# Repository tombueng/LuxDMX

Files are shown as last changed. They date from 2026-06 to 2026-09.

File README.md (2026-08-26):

<p align="center">
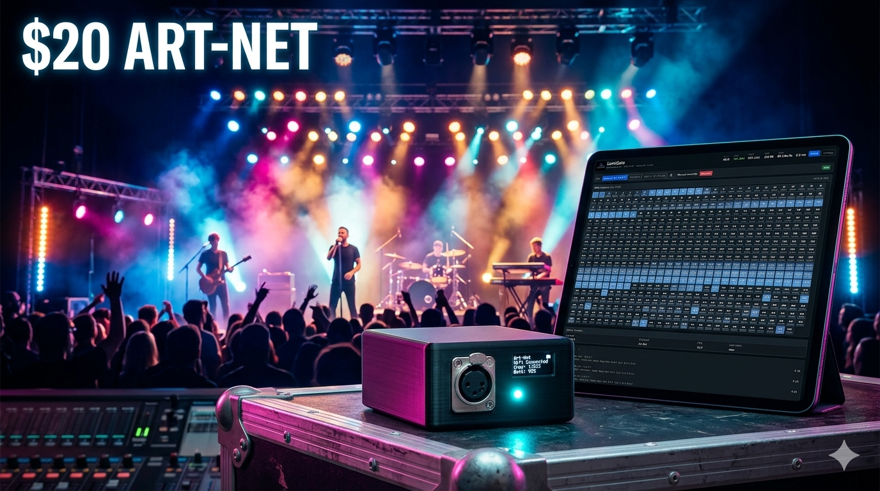
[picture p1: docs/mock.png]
LuxDMX — open-source Art-Net / sACN to DMX512 gateway with a live diagnostic web UI
  
</p>

<p align="center">
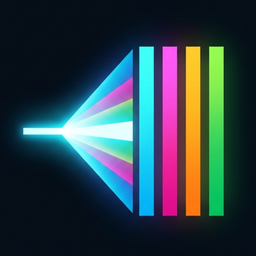
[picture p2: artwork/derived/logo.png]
LuxDMX logo
  
</p>

<h1 align="center">LuxDMX</h1>

<p align="center">
  <b>Open-source Art-Net / sACN (E1.31) &rarr; DMX512 gateway for ESP32 / ESP32-S3 / Ethernet.</b>
</p>

<p align="center">
  Not just another Art-Net node &mdash; a network DMX node <i>and</i> a live diagnostic tool.<br>
  Watch all 512 channels update in real time in your browser, get warned the instant
  <b>two consoles fight over a universe</b>, see per-sender FPS and frame jitter, and drive
  <b>galvanically-isolated</b> DMX out. Builds for a few dollars.
</p>

<p align="center">
  
  
  
  
</p>

<p align="center">
  <a href="https://tombueng.github.io/LuxDMX/"><b>⚡ Flash from your browser</b></a> &nbsp;·&nbsp;
  <a href="https://luxdmx.org/video"><b>▶ Watch the demo</b></a> &nbsp;·&nbsp;
  <a href="hardware/README.md"><b>🛠 Custom PCB</b></a> &nbsp;·&nbsp;
  <a href="#flashing-pre-built-firmware"><b>Install</b></a>
</p>

| Status page | Settings page |
|---|---|
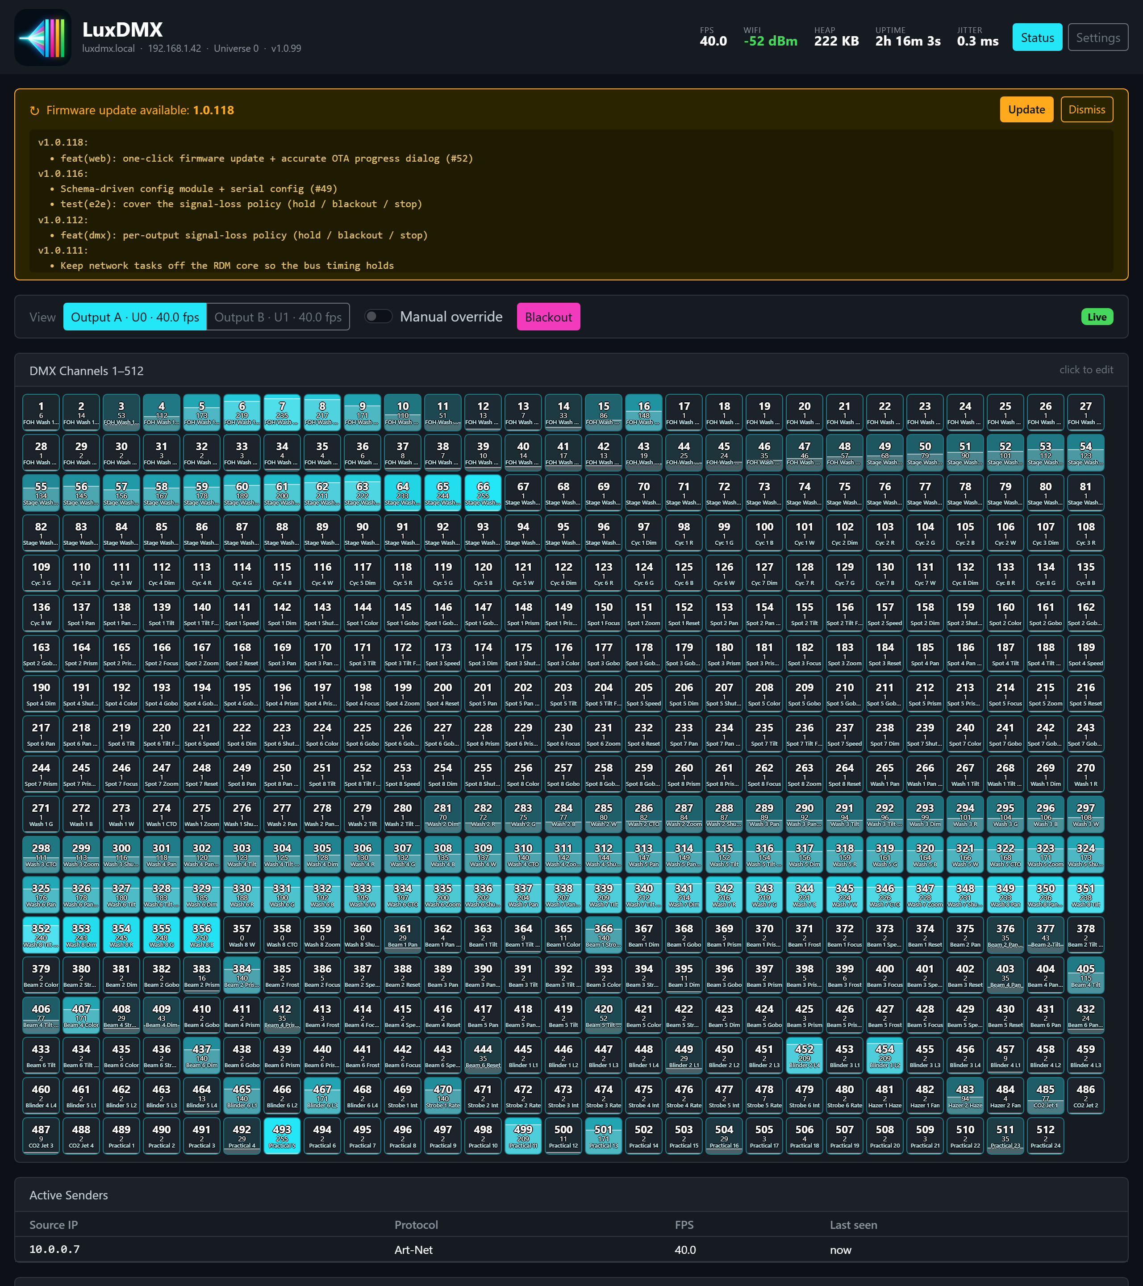
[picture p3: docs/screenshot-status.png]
Status page
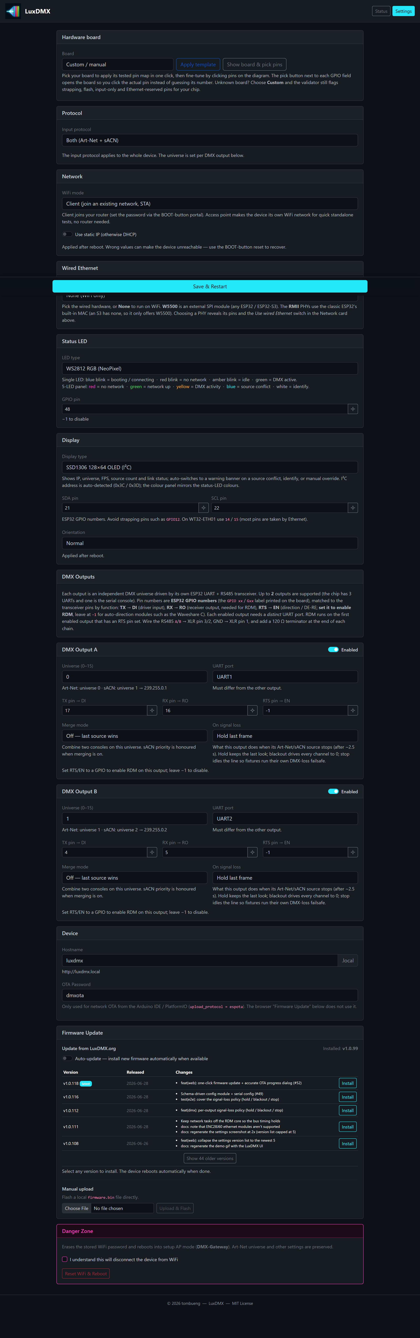
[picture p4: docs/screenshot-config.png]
Settings page
|  |  |

### Web UI walkthrough

A guided tour of every control — manual channel control, labels, sparkline history, identify, blackout, and all settings:

LuxDMX web UI walkthrough (https://luxdmx.org/video)

▶ **[Watch the full walkthrough on YouTube](https://luxdmx.org/video)** &nbsp;·&nbsp; regenerate with [`docs/screenshot.mjs`](docs/screenshot.mjs)

---

## Features

| Feature | Details |
|---|---|
| **Art-Net → DMX512** | Full 512-channel, unicast or broadcast, universe configurable (0–15) |
| **sACN / E1.31 → DMX512** | Multicast receive, universe configurable, runs alongside Art-Net |
| **Protocol selection** | Art-Net only / sACN only / Both — configurable in web UI |
| **Live Web UI** | Bootstrap 5 dark theme, WebSocket push (~10/s), all 512 channels visible |
| **Sender list** | Shows all active Art-Net / sACN senders with per-sender FPS |
| **Conflict detection** | Warning banner when multiple senders are active simultaneously |
| **Source merging** | Per-output HTP (highest takes precedence) / LTP (latest wins) / off, honouring the sACN priority field |
| **Jitter stat** | Real-time inter-frame timing deviation (EMA) |
| **Change log** | Live log of DMX value changes with top-N changed channels per frame |
| **Sparkline** | Per-channel history sparkline in the channel detail modal |
| **Channel labels** | Name any channel (e.g. "Front Wash L") — shown in grid, modal, and change log |
| **Identify** | Flash a channel to full for ~1.5 s to physically locate the fixture |
| **Manual DMX control** | Click any channel in browser, set value via slider |
| **Blackout button** | Zero all channels instantly from browser |
| **Art-Net / Manual toggle** | Switch between protocol passthrough and manual override |
| **Signal-loss policy** | Per-output choice when the source stops: hold last frame (default), blackout, or stop sending. Continuous 40 Hz refresh bridges brief input gaps either way |
| **Static IP or DHCP** | Configurable static IP/gateway/subnet/DNS, or automatic DHCP |
| **Mesh-aware WiFi** | Scans all channels and joins the **strongest** AP (multi-AP/mesh friendly) |
| **First-run setup portal** | On first boot (or BOOT-button held) LuxDMX opens its own `LuxDMX-setup` access point with a captive portal. The on-brand page (served from the same web UI) lets you either join your WiFi or run the device as its own access point, no router needed |
| **Selectable network mode** | Pick the interface (WiFi or wired Ethernet) and WiFi mode (client/STA or standalone AP) in the web UI, on boards that have both |
| **Standalone AP mode** | LuxDMX hosts its own WiFi network so a phone/tablet/console connects directly and sends Art-Net with no router (reachable at `192.168.4.1`) |
| **Wired link-loss policy** | Pick what happens if wired Ethernet is selected but the link is down: keep retrying (default, never opens a hotspot), a standalone WPA2 AP, reboot, or fall back to your saved WiFi network. A runtime watchdog applies it even if the cable is pulled mid-run, and the fallback AP never opens *unsecured*. The WiFi setup portal is BOOT-button-only (physical access), never an automatic fallback |
| **Versioned OTA** | Pick & install any past release from a table, or auto-update to latest |
| **OTA Updates** | ArduinoOTA (IDE/CLI) + manual `.bin` upload + one-click update from luxdmx.org |
| **mDNS + DHCP hostname** | Reachable as `dmx-gateway.local` via mDNS, *and* the device sends its hostname over DHCP (option 12) so your router registers it by plain name. Clients without mDNS (e.g. Windows) can then reach it as `dmx-gateway` / `dmx-gateway.fritz.box`. Hostname configurable |
| **REST API** | `GET /dmx.json`, `/senders.json`, `/log.json`, `/version.json`, `/labels.json` |
| **Status LED** | Plain GPIO, WS2812 RGB NeoPixel, or 5-LED panel (v6 board) — one status language: green = up (stays on; slow blink = DMX coming in), blue = RDM/identify **added on top of green** (both LEDs on the panel, cyan on a single RGB LED), orange = Ethernet-on-WiFi-fallback, red = no network, Knight-Rider boot |
| **Up to 2 DMX outputs** | Two independent universes, each its own UART + RS485 transceiver (same universe on both = splitter) |
| **RDM (E1.20)** | Discover and configure fixtures on the wire: DISC_UNIQUE_BRANCH discovery, GET/SET DEVICE_INFO / DMX start address / identify / sensors, on an RDM-capable output (one with a DE/RE pin). esp_dmx-free RMT-TX + UART-RX engine |
| **RDM over Art-Net** | Full Art-Net 4 RDM output gateway (ArtPoll / ArtTodRequest / ArtTodControl / ArtRdm) so a console (DMX-Workshop, MagicQ, grandMA3, OLA) does RDM to the fixtures over the network. Discovery is scheduled one transaction per DMX frame, so RDM never stalls the DMX output. See [docs/rdm.md](docs/rdm.md) |
| **Remote node config (ArtAddress)** | Configure the node from the console's own network window (MagicQ Network Manager, DMX-Workshop, ...): rename it and move each output to a different universe, saved to NVS so it survives a reboot. On by default and **unauthenticated**, like every other Art-Net command. See [Remote node config over Art-Net](#remote-node-config-over-art-net-artaddress) |
| **Remote IP config (ArtIpProg)** | A controller can read and set the node's IP / mask / gateway (or switch it to DHCP) over the network with Art-Net `ArtIpProg`, so a box that landed on an unreachable address is recoverable without the BOOT button or a serial cable. **Off by default** (Art-Net has no auth, so on = anyone on the wire can renumber it); the new address applies on the next boot. See [Remote IP config over Art-Net](#remote-ip-config-over-art-net-artipprog-off-by-default) |
| **Status display** | Optional I²C OLED (SSD1306 / SH1106) or colour SPI OLED (SSD1351) — IP, universe, FPS, sources + auto-rotating conflict/identify/manual banners |
| **On-unit controls** | Optional rotary encoder and/or up to 4 buttons drive a small on-display menu to set the universe (and protocol) without a phone or PC, and the choice persists. Works with any mix of inputs — encoder-only, one button, or the lot. See [docs/controls.md](docs/controls.md) |
| **Configurable DMX pins** | Per output: universe, UART port, TX / RX / RTS GPIO — set at runtime via web UI, no recompile |
| **NVS persistence** | Universe, protocol, IP config, labels, hostname, OTA password, LED/DMX pin config survive reboots |
| **Config reset** | Hold BOOT button 3 s on startup, or via `/reset` page |
| **Remote restart** | Restart the box from the web UI (**Device → Restart device**) or `POST /reboot`, without changing a setting. Useful when a long-running gateway needs a nudge, or to free up memory before a firmware update |
| **Ethernet support** | WT32-ETH01 (LAN8720) and the v6 board (W5500) run wired LAN *or* WiFi, switchable at runtime; any ESP32 / ESP32-S3 + an external SPI module (W5500 or DM9051) works too, and a **classic ESP32 can pick a SPI chip (W5500 / DM9051) or the built-in MAC + an RMII PHY** (LAN8720, IP101, RTL8201, DP83848, KSZ8081, JL1101) in `/config`; DHCP or static |
| **Dual/triple target** | Builds for ESP32 (WROOM-32), ESP32-S3 (DevKitC-1), WT32-ETH01 |

---

## Hardware

> ### 🛠 Custom PCB — LuxDMX v6
>
> Want the real thing instead of breadboard + modules? There's a complete **open-source 4-layer PCB**:
> ESP32-S3 with **both WiFi and wired Ethernet** (W5500), **two galvanically-isolated DMX universes**
> (two XLR-5 outputs), **802.3af PoE** or USB-C power + flashing, a 5-LED status panel, BOOT/RST buttons,
> and an optional OLED/TFT display header. All palm-sized and fabricable at JLCPCB for a few dollars.
>
> **v6 is DMX512-A Protected** (ANSI E1.11 Annex C): each DMX output survives a sustained fault on the data
> pins — someone plugging mains (30 VAC) or up to ±42 VDC into the XLR — without damage. A series Bourns TBU
> high-speed protector blocks the fault in <1 µs and the board self-recovers when it's removed. Full
> [E1.11 / DMX512-A compliance breakdown →](hardware/E1.11_COMPLIANCE.md)
>
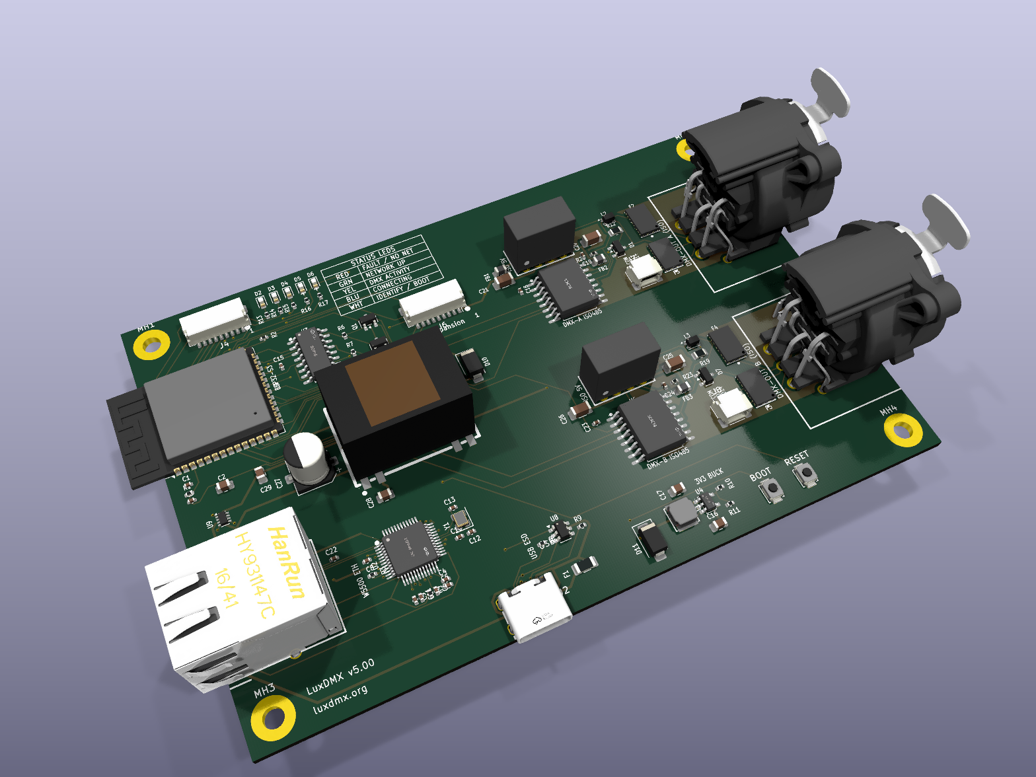
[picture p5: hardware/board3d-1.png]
LuxDMX v6 custom PCB — DMX512-A Protected
> [](hardware/README.md)
>
> **→ Full design, component rationale, BOM, gerbers & JLCPCB fab guide: [`hardware/`](hardware/README.md)**

The rest of this section covers the simpler **breadboard / module** build (an off-the-shelf ESP32 DevKit
+ an isolated RS485 module) — perfect for getting started without fabricating a board.

### Bill of Materials — WiFi build (ESP32 / ESP32-S3)

| # | Component | Description | Link |
|---|---|---|---|
| 1 | **ESP32 DevKit v1** | ESP32-WROOM-32, 30-pin, any CH340/CP2102 variant | [Amazon.de search](https://www.amazon.de/s?k=ESP32+DevKit+WROOM-32) |
| 2 | **Waveshare TTL to RS485 (C)** | Galvanically isolated RS485 transceiver, auto-direction | [Amazon.de – B0D4TZQYVG](https://www.amazon.de/dp/B0D4TZQYVG) |
| 3 | **XLR-5 female panel socket** | Standard DMX output connector (XLR-3 also works) | [Amazon.de search](https://www.amazon.de/s?k=XLR+5+Pin+Buchse+Panel) |
| 4 | **Jumper wires / dupont cables** | Male–male for breadboard, or direct solder | any |
| 5 | **USB-A to Micro-USB cable** | Power + serial flash | any |

### Bill of Materials — Ethernet build (WT32-ETH01)

| # | Component | Description | Link |
|---|---|---|---|
| 1 | **WT32-ETH01** | ESP32 + LAN8720 Ethernet PHY, built-in RJ45 | [Amazon.de search](https://www.amazon.de/s?k=WT32-ETH01) |
| 2 | **Waveshare TTL to RS485 (C)** | Same as WiFi build | [Amazon.de – B0D4TZQYVG](https://www.amazon.de/dp/B0D4TZQYVG) |
| 3 | **XLR-5 female panel socket** | Same as WiFi build | any |
| 4 | **Ethernet cable** | Cat5e or better | any |
| 5 | **5V power supply** (500 mA+) | WT32-ETH01 has no USB port — use a 5V supply on the VIN pin | any |

> The WT32-ETH01 has a built-in RJ45 jack and LAN8720 PHY soldered on-board. No additional Ethernet module needed.

**Optional for enclosure:**
- Project box / DIN-rail enclosure
- 120 Ω termination resistor across DMX A/B at the cable end (required for long runs)

---

### The RS485 Module: Waveshare TTL to RS485 (C)

This module is the key interface between the ESP32's UART and the DMX RS485 bus.

| Property | Value |
|---|---|
| Product name | Waveshare TTL to RS485 (C) |
| Isolation | Galvanic, 2500 V RMS (SP3485 + isolation transformer) |
| Direction control | Automatic — no DE/RE pin needed |
| TTL voltage | 3.3 V or 5 V (VCC selects level) |
| Max baudrate | ≥ 250 kbps (verified working at DMX rate) |
| Connector (TTL side) | 6-pin 2.54 mm header: VCC / GND / RXD / TXD / (unused) / (unused) |
| Connector (RS485 side) | Screw terminal: A / B / GND |
| Dimensions | ~38 × 14 mm |

> **Why galvanic isolation?**  
> DMX fixtures are often powered from separate circuits or have ground loops. The isolated module prevents ground noise from corrupting the signal and protects the ESP32 from voltage spikes.

> **Why auto-direction?**  
> Standard RS485 requires toggling a DE/RE pin to switch between transmit and receive. The Waveshare (C) variant handles this internally based on line activity — no GPIO needed, firmware is simpler. Trade-off: RDM (which requires half-duplex arbitration) is not supported by this module.

---

### Pinout Reference

**Waveshare TTL to RS485 (C) — TTL header (left side):**

```
Pin 1  VCC   → ESP32 3.3V
Pin 2  GND   → ESP32 GND
Pin 3  RXD   → ESP32 GPIO17  (default TX pin — configurable in web /config)
Pin 4  TXD   → ESP32 GPIO16  (default RX pin — configurable in web /config)
Pin 5  —     (not connected)
Pin 6  —     (not connected)
```

> **Different hardware?** If your RS485 module or ESP32 board uses different GPIO pins, change TX/RX under **Settings → DMX Output Pins** in the web UI. No recompile needed.

**Waveshare TTL to RS485 (C) — RS485 screw terminal (right side):**

```
A  →  DMX XLR pin 3  (Data+)
B  →  DMX XLR pin 2  (Data–)
GND→  DMX XLR pin 1  (Shield/Ground)  [optional but recommended]
```

---

### Wiring Diagram

LuxDMX Wiring Diagram

**Connection table:**

| ESP32 pin | → | Module pin | → | XLR pin |
|---|---|---|---|---|
| GPIO17 (TX) | → | RXD | — | — |
| GPIO16 (RX) | ← | TXD | — | — |
| 3.3V | → | VCC | — | — |
| GND | → | GND | — | — |
| — | — | A (RS485+) | → | Pin 3 |
| — | — | B (RS485–) | → | Pin 2 |
| GND | — | GND | → | Pin 1 (optional) |

#### WT32-ETH01 wiring (different pins — GPIO16 used by LAN8720)

| WT32-ETH01 pin | → | Module pin | → | XLR pin |
|---|---|---|---|---|
| GPIO4 (TX) | → | RXD | — | — |
| GPIO5 (RX) | ← | TXD | — | — |
| 3.3V | → | VCC | — | — |
| GND | → | GND | — | — |
| — | — | A (RS485+) | → | Pin 3 |
| — | — | B (RS485–) | → | Pin 2 |

> **Do not use GPIO16 on the WT32-ETH01** — it gates the LAN8720's 50 MHz oscillator (the Arduino core declares it as `ETH_PHY_POWER`), so driving it kills the Ethernet link. GPIO0 is the RMII reference clock and is equally off-limits.
>
> GPIO17 **is** free to use — it's plain `TXD2` on this board and has no Ethernet role. (An earlier version of this page said otherwise; that was wrong.) Note it also drives the on-board TX activity LED, so expect a few mA of extra load and a flickering LED while DMX is clocking.

---

### Assembly Guide

#### Step 1 — Prepare the ESP32

No soldering required if using a DevKit with pre-soldered headers. Place it on a breadboard or in your enclosure.

#### Step 2 — Connect ESP32 ↔ RS485 module

Using dupont jumper wires:

| Color convention | From | To |
|---|---|---|
| Red | ESP32 **3.3V** | Module **VCC** |
| Black | ESP32 **GND** | Module **GND** |
| Yellow | ESP32 **GPIO17** (TX) | Module **RXD** |
| Green | ESP32 **GPIO16** (RX) | Module **TXD** |

> Use **3.3V**, not 5V — the ESP32's GPIOs are not 5V tolerant.

#### Step 3 — Wire the XLR connector

The DMX standard uses XLR-5 (5-pin), but most DMX fixtures also accept XLR-3. Pin numbering is the same:

| XLR Pin | Signal | RS485 module |
|---|---|---|
| 1 | Shield / GND | Module GND (optional) |
| 2 | DMX Data– | Module **B** |
| 3 | DMX Data+ | Module **A** |
| 4 | (unused in DMX) | — |
| 5 | (unused in DMX) | — |

Screw the wires into the RS485 module's terminal block firmly.

#### Step 4 — Termination resistor (for longer cable runs)

For DMX cable runs over ~10 m, solder a **120 Ω resistor** between pins 2 and 3 (A and B) at the **far end** of the DMX chain (i.e., inside the last fixture's XLR input). Most professional fixtures include this internally.

#### Step 5 — Power

The ESP32 DevKit is powered via its **Micro-USB port**. Any 5V USB power supply works (500 mA is sufficient). The RS485 module draws its power from the ESP32's 3.3V rail.

---

### Notes

- **Do not connect DE/RE** — the Waveshare (C) handles direction automatically. Connecting them will break transmission.
- **Keep TTL wires short** (< 20 cm). Long unshielded wires on the TTL side pick up noise; the RS485 side handles long distances natively.
- **XLR gender:** Use a **female** XLR panel socket for the DMX output. DMX sources (transmitters) use female XLR; receivers use male XLR. LuxDMX is a source.

---

## Software Stack

LuxDMX is built entirely on free and open-source software: firmware, web UI, tests, and
the hardware design tooling. Firmware versions are pinned in `platformio.ini`; everything
below is what we actually pull in and what each piece does for us.

### Firmware, third-party libraries

| Library | Version | License | What we use it for |
|---|---|---|---|
| [rstephan/ArtnetWifi](https://github.com/rstephan/ArtnetWifi) | `^1.5.0` | MIT | Art-Net receiver: parses ArtDMX/ArtPoll on UDP 6454. |
| [ESP32Async/ESPAsyncWebServer](https://github.com/ESP32Async/ESPAsyncWebServer) | git | LGPL-3.0 | The whole HTTP side: web UI, REST API, WebSocket live channels, OTA upload, and the first-run setup portal. All non-blocking, so DMX keeps clocking while someone browses the config page. |
| [ESP32Async/AsyncTCP](https://github.com/ESP32Async/AsyncTCP) | git | LGPL-3.0 | TCP backend for the above. We give it a bigger stack/queue and pin it to core 0 (see the build flags in `platformio.ini`) so it can't preempt the RDM bus timing on core 1. |
| [Adafruit NeoPixel](https://github.com/adafruit/Adafruit_NeoPixel) | `^1.12.3` | LGPL-3.0 | Drives the WS2812 RGB status LED (DevKit boards, and any DIY build with an addressable LED). |
| [Adafruit GFX Library](https://github.com/adafruit/Adafruit-GFX-Library) | `^1.11.11` | BSD | Shared drawing primitives and fonts behind every supported display panel. |
| [Adafruit SSD1306](https://github.com/adafruit/Adafruit_SSD1306) | `^2.5.13` | BSD | 128×64 / 128×32 mono I²C OLEDs. |
| [Adafruit SH110X](https://github.com/adafruit/Adafruit_SH110X) | `^2.1.12` | BSD | SH1106 / SH1107 mono OLEDs (the 1.3" panels). |
| [Adafruit SSD1351](https://github.com/adafruit/Adafruit-SSD1351-library) | `^1.3.2` | BSD | 128×128 colour SPI OLED. |
| [Adafruit BusIO](https://github.com/adafruit/Adafruit_BusIO) | transitive | MIT | I²C/SPI abstraction the Adafruit display drivers sit on. |

> The two `ESP32Async` libraries and Adafruit NeoPixel are **LGPL-3.0**. We link them
> unmodified, which is what the LGPL asks for; the LuxDMX source itself stays MIT.

There is no DMX or RDM library. Both protocols are ours: `dmx_rmt.h` clocks DMX512 out of
the RMT peripheral, and `rdm_rmt.h` is an RDM E1.20 controller on RMT-TX plus a RX-only
UART, with the E1.20 types declared in `rdm_types.h`. This used to be
[someweisguy/esp_dmx](https://github.com/someweisguy/esp_dmx); we moved off its UART driver
when Ethernet DMA contention started tearing frames (issue #64) and dropped the dependency
entirely once nothing but its type declarations was left.

### Firmware, platform and built-ins

[arduino-esp32 v3](https://github.com/espressif/arduino-esp32) (LGPL-2.1) on top of
[ESP-IDF 5.x](https://github.com/espressif/esp-idf) (Apache-2.0), delivered by the
[pioarduino](https://github.com/pioarduino/platform-espressif32) platform fork (the
mainline PlatformIO platform is stuck on v2.x, which has no W5500 Ethernet).

| Component | What we use it for |
|---|---|
| RMT peripheral | DMX512 transmit clocked out in hardware, immune to the core-0 network DMA contention behind issue #64, plus the TX half of the RDM controller. |
| `WiFi.h` / `ETH.h` | WiFi STA/AP, and wired Ethernet on both paths: W5500 over SPI and LAN8720 over RMII. |
| built-in UDP | sACN / E1.31 receive on port 5568. |
| `ArduinoOTA`, `Update`, `HTTPUpdate`, `HTTPClient`, `WiFiClientSecure` | OTA updates: the Arduino OTA path, web upload, and the self-update check against the GitHub release. |
| `ESPmDNS` | `dmx-gateway.local` discovery. |
| `Preferences` | NVS-backed persistent config. |
| `DNSServer` | Captive-portal DNS while the device is in setup-AP mode. |
| `Wire` / `SPI` | I²C and SPI buses for the displays and the W5500. |
| `driver/uart.h` | The RX-only UART that catches RDM responses. |
| FreeRTOS | Tasks, queues, and the core pinning that keeps network work off the DMX/RDM core. |

### Web UI

| Library | Version | License | What we use it for |
|---|---|---|---|
| [Bootstrap](https://getbootstrap.com/) (CSS only) | 5.3.3 | MIT | Layout and styling for every page. Vendored at `src/assets/bootstrap.min.css` and served gzipped from flash, so the UI works on a device with no internet. |
| [esp-web-tools](https://github.com/esphome/esp-web-tools) | 10 | Apache-2.0 | The browser flasher on the project page (`web/index.html`), so nobody needs a toolchain to install firmware. |

No JS framework. The pages are plain ES6, and the board pin-picker and the RDM sensor
charts are hand-rolled SVG. It all has to fit in flash next to the firmware.

### Build, CI, and tests

| Tool | License | What we use it for |
|---|---|---|
| [PlatformIO Core](https://platformio.org/) | Apache-2.0 | Build system, dependency pinning, and flashing. |
| [esptool](https://github.com/espressif/esptool) | GPL-2.0 | Serial flashing and merging the factory image. |
| [Playwright](https://playwright.dev/) (`@playwright/test ^1.60`) | Apache-2.0 | The end-to-end suite in [docs/tests/](docs/tests/): drives a live device with real Art-Net/sACN and asserts the REST API, WebSocket, and web UI. |
| [Pillow](https://python-pillow.org/) | MIT-CMU | Renders the display previews in [docs/](docs/) from the firmware's own layout math. |
| [GitHub Actions](https://github.com/actions) (`checkout`, `cache`, `setup-python`, `upload-artifact`, `*-pages`) | MIT | Builds every push, publishes the OTA release, deploys the Pages site. |

The native config round-trip test (`test/native/`) deliberately uses no framework: it
compiles the config engine on the host against small `Arduino.h` / `Preferences.h` shims.

### Hardware design tooling

| Tool | License | What we use it for |
|---|---|---|
| [KiCad 9](https://www.kicad.org/) + the `pcbnew` Python API | GPL-3.0 | The board itself, and the scripts under [hardware/scripts/](hardware/scripts/) that place parts, fix planes, and gate the design on DRC. |
| `kicad-cli` | GPL-3.0 | Gerber/drill export, DRC runs, schematic PDF, all scripted with no GUI in the loop. |
| [SKiDL](https://github.com/devbisme/skidl) | MIT | Schematic-as-code: `hardware/scripts/luxdmx.py` generates the netlist the schematic and board are built from. |
| [Freerouting 2](https://github.com/freerouting/freerouting) | GPL-3.0 | Autorouting passes (the jar lives in `hardware/tools/`, not in git). |
| [openpyxl](https://openpyxl.readthedocs.io/) | MIT | Real `.xlsx` BOM and CPL files; JLCPCB rejects hand-rolled ones. |

### RDM test fixture (separate sub-project)

[RDM/](RDM/) is a standalone RP2350 (Pico Plus 2 W) DMX/RDM responder used to test this
controller's on-wire timing. It builds on [arduino-pico](https://github.com/earlephilhower/arduino-pico)
(LGPL-2.1) and [Pico-DMX](https://github.com/jostlowe/Pico-DMX) (BSD-3-Clause) for the PIO
DMX engine.

---

## Flashing Pre-built Firmware

> ### ⚡ Flash from your browser — no install, no command line
>
> Open **[the web flasher](https://tombueng.github.io/LuxDMX/)** in desktop **Chrome or Edge**,
> plug in your board over USB, pick your model, and click flash. That's it — no Python, no esptool,
> no toolchain. It always installs the latest release.
>
> The manual / scripted methods below still work if you prefer them, or for the WT32-ETH01 (which has no USB port).

No toolchain needed. GitHub CI builds the firmware on every push to master.

**[Download latest release](https://github.com/tombueng/LuxDMX/releases/tag/latest)** — includes `firmware.bin`, `bootloader.bin`, `partitions.bin`, `boot_app0.bin`.

### Boot mode (required for all methods)

You must manually enter download mode before flashing:

1. Hold **BOOT** button
2. Press and release **EN** (or **RST**) while keeping BOOT held
3. Release BOOT — the chip is now in download mode
4. Run the flash command

> **ESP32-S3 DevKitC-1:** use the **USB-UART** port (labeled on the board), not the native USB port. The native USB port cannot be used with esptool.

### Windows — one-liner (PowerShell)

Downloads and runs [`flash.ps1`](flash.ps1), which installs Python + esptool automatically:

```powershell
Set-ExecutionPolicy -Scope Process Bypass; irm https://raw.githubusercontent.com/tombueng/LuxDMX/master/flash.ps1 | iex
```

Or save and run it manually:

```powershell
# Download
Invoke-WebRequest https://raw.githubusercontent.com/tombueng/LuxDMX/master/flash.ps1 -OutFile flash.ps1
# Run
Set-ExecutionPolicy -Scope Process Bypass
.\flash.ps1
```

The script: installs Python 3 via `winget` if missing → installs `esptool` via pip → downloads the four firmware blobs from the latest GitHub release → lets you pick a COM port → guides you through boot mode → flashes.

### macOS / Linux — ESP32 (WROOM-32)

```bash
pip install esptool

REPO=tombueng/LuxDMX
for f in firmware.bin bootloader.bin partitions.bin boot_app0.bin; do
  curl -sL "$(curl -s https://api.github.com/repos/$REPO/releases/tags/latest \
    | python3 -c "import sys,json; assets=json.load(sys.stdin)['assets']; \
      print(next(a['browser_download_url'] for a in assets if a['name']=='$f'))")" -o $f
done

# Enter boot mode first (see above), then:
esptool.py --chip esp32 --port /dev/ttyUSB0 --baud 460800 \
  --before default_reset --after hard_reset \
  write_flash -z --flash_mode dio --flash_freq 80m \
  0x1000 bootloader.bin 0x8000 partitions.bin \
  0xe000 boot_app0.bin 0x10000 firmware.bin
```

### macOS / Linux — ESP32-S3 (DevKitC-1)

> **Important:** bootloader goes at `0x0000` on S3 (not `0x1000` like the original ESP32).

```bash
pip install esptool

REPO=tombueng/LuxDMX
for f in firmware-esp32s3.bin bootloader-esp32s3.bin partitions-esp32s3.bin boot_app0.bin; do
  curl -sL "$(curl -s https://api.github.com/repos/$REPO/releases/tags/latest \
    | python3 -c "import sys,json; assets=json.load(sys.stdin)['assets']; \
      print(next(a['browser_download_url'] for a in assets if a['name']=='$f'))")" -o $f
done

# Enter boot mode first, use the USB-UART port, then:
esptool.py --chip esp32s3 --port /dev/ttyUSB0 --baud 921600 \
  --before default_reset --after hard_reset \
  write_flash -z --flash_mode dio --flash_freq 80m \
  0x0000 bootloader-esp32s3.bin 0x8000 partitions-esp32s3.bin \
  0xe000 boot_app0.bin 0x10000 firmware-esp32s3.bin
```

> Replace `/dev/ttyUSB0` with your port (`/dev/tty.usbserial-*` on macOS).

### macOS / Linux — WT32-ETH01

```bash
pip install esptool

REPO=tombueng/LuxDMX
for f in firmware-wt32eth01.bin bootloader-wt32eth01.bin partitions-wt32eth01.bin boot_app0.bin; do
  curl -sL "$(curl -s https://api.github.com/repos/$REPO/releases/tags/latest \
    | python3 -c "import sys,json; assets=json.load(sys.stdin)['assets']; \
      print(next(a['browser_download_url'] for a in assets if a['name']=='$f'))")" -o $f
done

# Enter boot mode (hold BOOT + press RST), then:
esptool.py --chip esp32 --port /dev/ttyUSB0 --baud 460800 \
  --before default_reset --after hard_reset \
  write_flash -z --flash_mode dio --flash_freq 80m \
  0x1000 bootloader-wt32eth01.bin 0x8000 partitions-wt32eth01.bin \
  0xe000 boot_app0.bin 0x10000 firmware-wt32eth01.bin
```

---

## Build & Flash

### Requirements

- [PlatformIO](https://platformio.org/) with VS Code extension
- ESP32 connected via USB (CH340 or CP2102)

### Project Structure

```
LuxDMX/
├── src/
│   ├── main.cpp          ← firmware logic
│   ├── config/
│   │   └── config_schema.cpp  ← THE field table: one row per setting
│   ├── pages/            ← edit web UI here (plain HTML)
│   │   ├── index.html
│   │   ├── config.html
│   │   ├── config_saved.html
│   │   ├── reset.html
│   │   └── reset_done.html
│   ├── assets/           ← images served by the ESP32
│   │   └── logo.webp     ← 256×256 WebP (~5 KB), embedded into the firmware on build
│   └── generated/        ← auto-created at build time, gitignored
├── include/              ← config_schema.h (Config struct) + config_enums.h
├── lib/EmbeddedConfig/   ← reusable schema-driven config engine (NVS + serial console)
├── templates/            ← per-board default VALUES (esp32dev.ini, luxdmx_v6.ini, ...)
├── docs/                 ← documentation assets (README images)
├── extra_scripts.py      ← PlatformIO pre-build hook
└── platformio.ini
```

Config is schema-driven: every persisted setting is described once as a row in
`src/config/config_schema.cpp`, and that one table drives NVS load/save, the
`/config` web form, and the serial console. Defaults live in `templates/*.ini`
(picked per build with `-DDEFAULT_TEMPLATE=...`), not as `-D` macros. The engine
itself is a standalone PlatformIO library under `lib/EmbeddedConfig/`.

### How the build pipeline works

Before every `pio run`, PlatformIO executes `extra_scripts.py`, which:

1. Reads every `src/pages/*.html` file
2. Reads every image/CSS in `src/assets/` (`*.png`, `*.webp`, `*.svg`, `*.css`)
3. Converts them to C `PROGMEM` arrays / string literals and writes them to `src/generated/*.h`
4. `main.cpp` `#include`s those headers — the HTML and images become part of the firmware binary
5. Embeds the board default `templates/*.ini` into `src/generated/config_templates.cpp` (via `tools/gen_config_templates.py`), so a build's defaults come from a data file, not hand-edited macros

**To change the web UI**, edit the HTML files in `src/pages/` and rebuild — no C++ changes needed.  
**To replace the logo**, drop a new `src/assets/logo.webp` (or re-run `artwork/derive-logos.sh`) and rebuild. WebP keeps the embedded logo around 5 KB instead of ~117 KB for the equivalent PNG, and it is served straight from flash so it costs no heap.

Dynamic values (IP address, universe number, etc.) use `{{PLACEHOLDER}}` tokens in the HTML; `main.cpp` substitutes them at request time with `String::replace()`.

### First Flash (USB)

```bash
pio run --target upload
```

> **If upload fails** ("Wrong boot mode"): Hold **BOOT** button, tap **EN/RST**, release BOOT — chip enters download mode. Then retry upload.

### OTA Updates (after first flash)

- **From browser:** open `http://dmx-gateway.local/config` → Firmware Update section → upload a `.bin` file or click "Update from LuxDMX.org". (The home page also has an **Update** button when a newer release is out, which installs the latest straight away.)
- **From a URL (works when the upload doesn't):** same section → **Install from a URL**. The device reboots and fetches the file itself with a fresh heap, instead of you pushing it into a running system. That matters because a gateway that has been up a while fragments its heap, and a push upload can then die partway with nothing but a dropped connection to show for it. Serve your build off the machine you built it on and paste the URL:

  ```bash
  cd .pio/build/esp32s3dev && python -m http.server 8000
  # then: http://<your-ip>:8000/firmware.bin
  ```

  Use `http://`, not `https://` — a TLS handshake wants ~50 KB of *contiguous* heap, which is usually the exact thing you have run out of. Plain HTTP streams straight into flash and needs almost none.

> When you install from LuxDMX.org, the device reboots into a dedicated update mode and pulls the new firmware there, then reboots again into it. This is deliberate: the HTTPS download needs a large block of free RAM that the fully running gateway (DMX, RDM, Art-Net, web UI) no longer leaves free, so it does the download early at boot when the RAM is untouched. The device is offline for about a minute during the install; the progress page waits for it to come back. The local `.bin` upload doesn't need this and flashes directly.

| Downloading update | Back online |
|---|---|
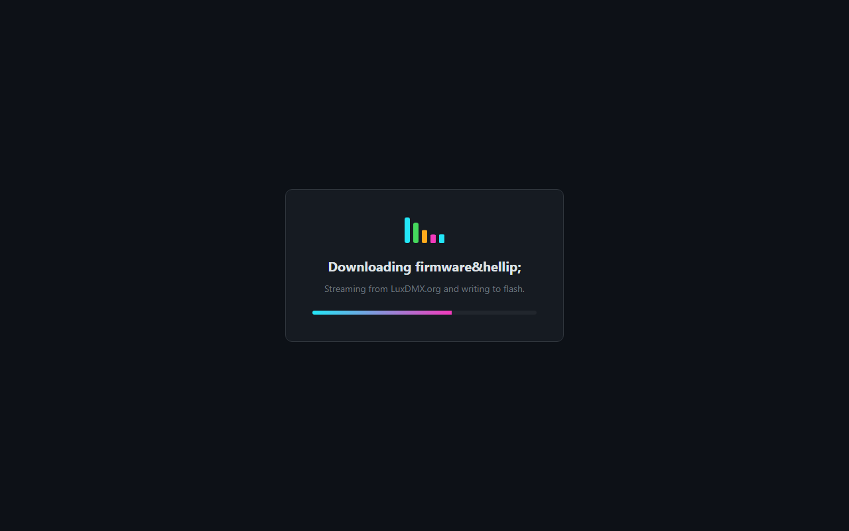
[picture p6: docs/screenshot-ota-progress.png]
OTA progress
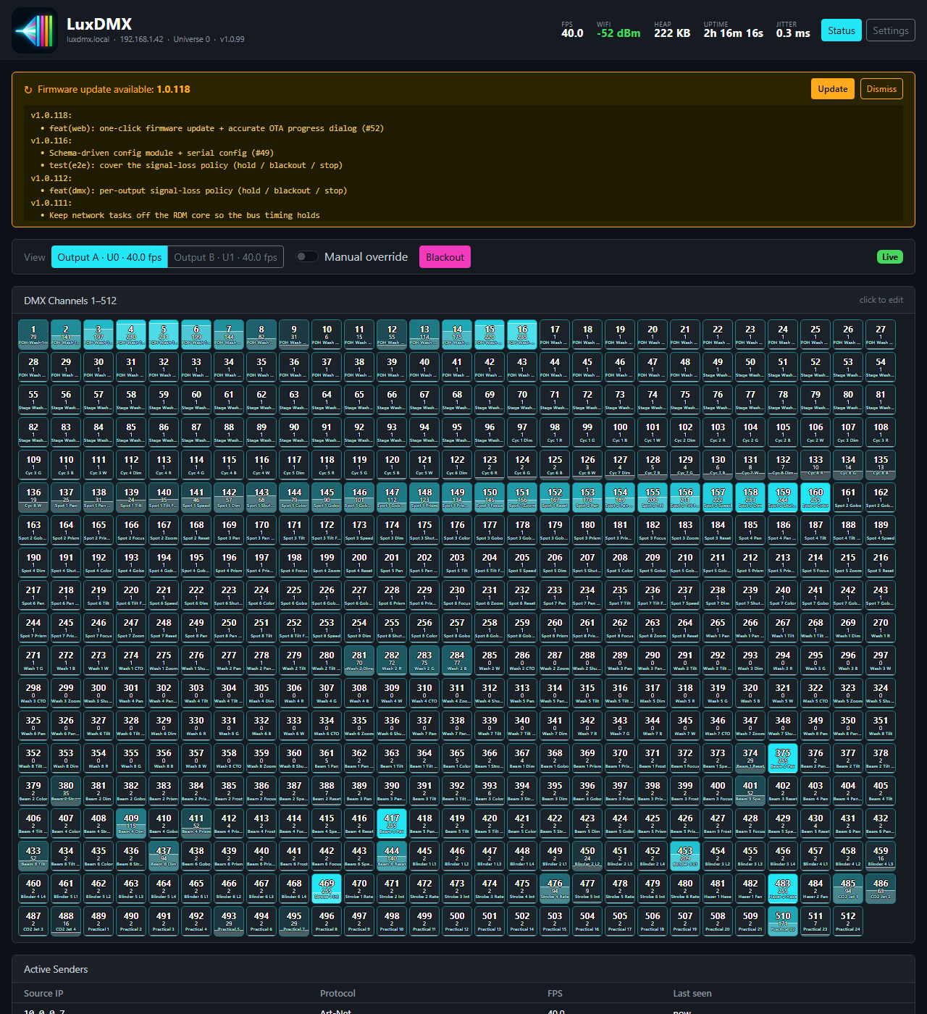
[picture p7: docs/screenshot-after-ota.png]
After OTA
|  |  |

- **From IDE:** uncomment in `platformio.ini`:
```ini
upload_protocol = espota
upload_port     = dmx-gateway.local
upload_flags    = --auth=dmxota
```

> The **OTA Password** (Settings → Device) guards **only** this IDE / PlatformIO
> `espota` path. The browser "Firmware Update" above (`.bin` upload + luxdmx.org install)
> is **not** protected by it.

---

## First Setup

### WT32-ETH01 (Ethernet)

Out of the box, connect an Ethernet cable and power on — DHCP assigns an IP automatically. Open `http://dmx-gateway.local` or check your router for the assigned IP. WT32-ETH01 also has WiFi: you can switch it to WiFi client or a standalone access point in **`/config` → Network** (see [Network mode](#network-mode-wifi-ethernet-or-standalone-ap) below).

### 1. Setup portal (first run)

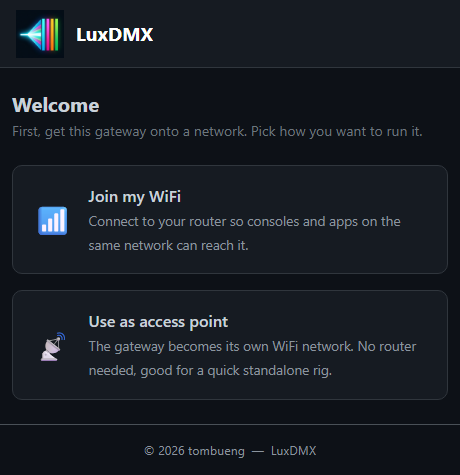
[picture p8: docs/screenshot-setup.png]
Setup portal — pick a path
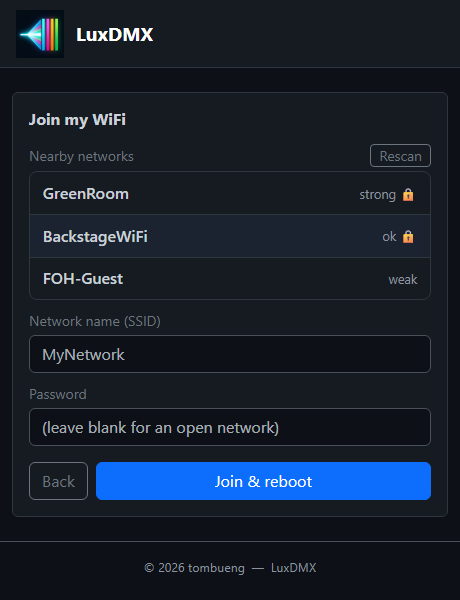
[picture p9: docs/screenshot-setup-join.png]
Setup portal — join WiFi
|  |  |
|---|---|

On first boot (or after a WiFi reset, or with the BOOT button held at power-up), LuxDMX
opens its own setup access point and a captive portal:

- **SSID:** `LuxDMX-setup` (open, no password — it's first-run physical-access setup)
- Connect with a phone or PC → the "sign in to WiFi" sheet auto-opens the on-brand setup
  page (or browse to `192.168.4.1`)
- Pick one of two paths:
  - **Join my WiFi** — choose your network from the scanned list (or type the name),
    enter the password.
  - **Use as access point** — the device becomes its own WiFi network, no router needed.
    Set an optional AP password (8+ chars for WPA2), or leave it open.
- The device saves your choice and reboots into it. The confirmation page then waits for
  the device to come back on its new network and jumps to it automatically: `http://<hostname>.local`
  (default `dmx-gateway.local`) after joining your WiFi, or `192.168.4.1` in access-point mode.
  Reconnect this phone/PC to the same network and it'll open on its own.

The setup AP is named `LuxDMX-setup` on purpose, so it doesn't collide with the device
hostname that the **standalone AP mode** broadcasts.

> **Mesh / multi-AP WiFi:** LuxDMX scans all channels and joins the
> **strongest** AP for your SSID (and re-picks it on reconnect), so it won't
> latch onto a distant node. The ESP32 is **2.4 GHz only** — make sure the AP
> nearest the device broadcasts 2.4 GHz. Check `rssi` on the status page: a
> healthy link is roughly −40 to −65 dBm. If it sits near −80 dBm right next to
> a router, the nearby node likely isn't offering 2.4 GHz — use a dedicated
> 2.4 GHz IoT SSID, or the **WT32-ETH01 (Ethernet) build** for a wired,
> rock-solid connection.

### Network mode: WiFi, Ethernet, or standalone AP

Choose how LuxDMX connects in **`/config` → Network**. Changes apply after a reboot.

- **Interface** (boards with wired Ethernet — WT32-ETH01, v3, or **any board with a W5500 / DM9051 SPI module** picked under *Wired Ethernet*): **WiFi** or **wired Ethernet**. WT32-ETH01/v3 default to Ethernet/DHCP; turn off "Use wired Ethernet" to run on WiFi. On a plain ESP32/ESP32-S3, first pick the SPI chip (W5500 or DM9051) under *Wired Ethernet* and set its pins, then enable "Use wired Ethernet".
- **WiFi mode:**
  - **Client (STA)** — join your existing 2.4 GHz network (the default; set the SSID + password via the setup portal above, or right here in **`/config` → Network**).
  - **Standalone AP** — LuxDMX hosts its own WiFi network, so a phone, tablet, or console joins it directly with **no router required**. SSID = the device hostname (`dmx-gateway` by default); set a password of 8+ characters for WPA2, or leave it empty for an open network. The device is reachable at **`192.168.4.1`**.
- **Wired link-loss policy** (boards on wired Ethernet), for when *the wired Ethernet link is down*:
  - **Keep retrying the wired link** (default): never opens a hotspot, reconnects on its own when the cable is back. Best on a show.
  - **Standalone WiFi AP**: the device becomes its own network (needs an **AP password**; it refuses to open an *unsecured* AP).
  - **Reboot and retry**: power-cycle to re-attempt the link.
  - **Join WiFi**: fall back to the saved WiFi network (STA) when there is no wired link — handy for a board that is sometimes wired and sometimes not. Needs stored WiFi credentials; a link drop while running reboots (a clean boot then joins WiFi), and the next boot prefers wired again if the cable is back. It only ever joins the *already-saved* network, so a dropped link can't move the device somewhere new.

  A runtime watchdog applies the policy even if the cable is pulled while running (the old fallback only ran at boot, so a mid-show unplug used to strand the device). There is **no automatic WiFi setup portal** on link loss, on purpose: that would let anyone who can drop the link force the device onto their own WiFi. To move the device to a new WiFi, hold the **BOOT button** at power-up for the setup portal (physical access required).

  On the W5500 (SPI Ethernet) the watchdog first tries to **recover the link in place** before falling back: the chip can occasionally come up (or come back after heavy traffic like an OTA) reporting no link even though the cable is fine, and a plain reboot doesn't clear it. A full re-initialise (tear the driver down, hard-reset the chip, bring it back up) re-negotiates the link and clears it, without a reboot and without DMX ever stopping. This runs both at boot and from the runtime watchdog, so a wedged link recovers on its own; `/info.json` exposes `ethRecoverAttempts` and `ethRecoveries` so you can see it happen.

**Using AP mode with an iPad / console app** (Luminair, Photon, etc.): set WiFi mode to Standalone AP and reboot, join the `dmx-gateway` network, then point the app's Art-Net output at **`192.168.4.1`** (or broadcast `192.168.4.255`).

> **AP-mode caveats:** the joined device has **no internet** while on LuxDMX's AP; it is **2.4 GHz only** with a small client limit; and **Art-Net** (unicast/broadcast) is more reliable than **sACN** multicast over a SoftAP, so prefer Art-Net in this mode.

#### Remote IP config over Art-Net (ArtIpProg): off by default

A node that ends up with an address that doesn't work on the network it's plugged into normally needs
the **BOOT button** or a serial cable to fix. Art-Net has an answer for exactly this: **ArtIpProg**
(opcode `0xf800`). A controller (e.g. DMX-Workshop's node list, right-click, *Configure IP Address*)
reads the node's IP / mask / gateway and can set a new one, or switch it to DHCP. LuxDMX applies the
change, persists it, and replies with **ArtIpProgReply** (`0xf900`).

This is **off by default** (`ipprog` in **`/config` → Network**), and for good reason: the Art-Net
protocol has **no authentication or rate limiting**, so while it is on, *anyone who can send a UDP
packet to the device can change its network address*, including onto an address you can't reach it at.
Turn it on only on a trusted network, when you actually need it. While it's off, the device does not
reply to ArtIpProg at all, which is the spec's own way of declaring "not supported".

A programmed address is **stored and applied on the next reboot**, not slammed onto the running
interface, so a controller can't knock a live node off the wire mid-frame. The reply confirms what was
stored, and the change takes effect cleanly at the next boot.

#### Remote node config over Art-Net (ArtAddress)

Consoles expect to configure an Art-Net node without leaving the console. LuxDMX answers
**ArtAddress** (opcode `0x6000`), so from MagicQ's *Network Manager* (or DMX-Workshop, OLA,
grandMA3, ...) you can:

- **Rename the node.** The short and long names a console lists it under. They are stored separately
  from the hostname on purpose: the hostname drives mDNS and the DHCP client name and needs a reboot,
  while these are just a label. Set them locally too, in **`/config` → Device**.
- **Move an output to another universe.** The console programs `NetSwitch` / `SubSwitch` / `SwOut`,
  which together make the 15-bit port-address; `BindIndex` picks which output. It applies **live** (no
  reboot, and sACN re-joins the new multicast group by itself) and is written to NVS.
- **Set the merge mode** (`AcMergeHtp` / `AcMergeLtp` / `AcCancelMerge`), the **transmit style**
  (`AcStyleDelta` / `AcStyleConst`) and the **BackgroundQueuePolicy** (`AcBqp0`…`AcBqp15`), all of
  which have been there since the RDM gateway landed.
- **Clear an output** (`AcClearOp`): zeroes that port's frame buffer. It is not a blackout latch, a
  source that keeps streaming refills it on the next frame.

Every ArtAddress is answered with an **ArtPollReply**, which is how the console reads back what
actually got applied.

Until a name is set, the node advertises its **hostname**, so several LuxDMX boxes on one network are
told apart out of the box. (They all used to answer "LuxDMX", which made a rack of them useless to
pick from in a node list.)

> **This is unauthenticated, and it is on.** Art-Net has no auth, no rate limit and no notion of who
> owns a node, so anyone who can send a UDP packet to the device can rename it or move its universes.
> There is deliberately no switch to turn it off: the same is already true of every other Art-Net
> command the node accepts, and being configurable from the console is the entire point. Treat a show
> network as the trust boundary. (`ArtIpProg` above is the exception, and stays off by default,
> because a bad address is the one change that can make the device unreachable.)

### 2. Status Page

Open `http://dmx-gateway.local` (mDNS), or `http://dmx-gateway/` if your router resolves DHCP hostnames (handy on Windows, which has no mDNS), or the IP shown in serial monitor at 115200 baud:

- Live stats: framerate, link (**WiFi** signal in dBm, **LAN** with link speed, or **AP**), uptime, free heap, jitter
- Conflict warning when sources clash on a universe, or a "merging" indicator when HTP/LTP merging is enabled for that output
- Active sender list with per-sender protocol and FPS
- All 512 DMX channels as a live grid — each cell shows the channel number large,
  its current value small, a value-proportional brightness, **and** a bottom-to-top
  gauge fill so levels read at a glance
- Hover any cell for an instant (no-delay) 2.5× zoomed preview of that cell
  (channel number, value, gauge and label)
- Click any cell → slider + sparkline history appear → set value directly
- Change log with recent DMX activity

### 3. Changing WiFi / Config Reset

The quickest way to move LuxDMX to a different WiFi network is **`/config` → Network**:
set the new SSID + password and save. If you can't reach the web UI, clear the stored
credentials instead and the device reopens the setup portal on next boot.

| Method | Steps |
|---|---|
| **Web** (easiest) | Open `http://dmx-gateway.local/reset` → click **Reset WiFi** → device reboots into the `LuxDMX-setup` portal |
| **Hardware** | Power off → hold **BOOT** → power on → keep holding for 3 seconds → release → device reboots into the `LuxDMX-setup` portal |

After reset, connect to the open `LuxDMX-setup` access point and follow the
[First Setup](#1-setup-portal-first-run) steps to join the new network.

### Serial configuration (USB)

Mostly a recovery and scripting hatch. If a board can't get on the network, plug
it in over USB, open a serial monitor at 115200 baud, and type `help`. It's a tiny
key=value interface using the same field names as the web form:

| Command | What it does |
|---|---|
| `dump` | print every setting as `key=value` (passwords masked) |
| `key=value [key=value ...]` | set one or more fields (partial: only the keys you list change) |
| `get <key>` / `set <key> <value>` | read / write a single field |
| `save [reboot]` | persist to NVS, optionally reboot to apply |
| `wifi <ssid> [pass]` | set WiFi credentials and reconnect (the usual "it's stuck offline" fix) |
| `reboot` / `factory` | restart / wipe config and restart |

`dump` and the bare `key=value` write round-trip: dump the config, change a couple
of lines, paste them back, `save`. For everyday setup use the web UI; the serial
path is there for headless tweaks and getting a stranded board back online.

---

## Web UI

The HTTP server and WebSocket are served by ESPAsyncWebServer (non-blocking),
so the web UI never stalls DMX output. Pages are gzip-compressed and dynamic
values are fetched as JSON.

The settings page has grown a lot, so every section on it (Hardware board,
Protocol, Network, Wired Ethernet, Status LED, Display, Controls, each DMX output,
Device, Firmware Update, Danger Zone) **folds away from its own header**, and the
page **opens with everything folded**. What you get is a one-screen overview: each
header carries a one-line summary of what is set inside it, e.g.

```
Network            WiFi client · Studio · DHCP
Status LED         5-LED status panel (LuxDMX v5)
Controls           encoder · 2 buttons
DMX Output A       universe 0 · UART1 · TX 17 · RDM · 40 fps
```

Click a header to unfold that section; **Expand all** at the top opens the lot. Which
sections you keep open is remembered in your browser, so the page comes back the way
you left it. Folding is purely visual: a folded section still saves its values with
the rest of the form, and a section holding a rejected pin pops back open by itself so
a blocking error can't hide behind a fold.

| URL | Method | Function |
|---|---|---|
| `/` | GET | Live status + 512-channel DMX grid (gzip) |
| `/config` | GET / POST | Change universe, protocol, per-output merge mode (off/HTP/LTP) and signal-loss policy (hold/blackout/stop), static IP, hostname, OTA password, LED config, DMX pins, on-unit controls (rotary encoder + buttons) (gzip) |
| `/reset` | GET / POST | Clear WiFi credentials, reboot to AP mode |
| `/reboot` | POST | Restart the device, changing nothing. **POST only** — a GET would let a link prefetch or a crawler drop the DMX output of a live rig. Also in the UI: **`/config` → Device → Restart device** |
| `/info.json` | GET | Current settings + status (SSID, IP, universe, version, detected `board`/`mcu` id, picked `boardSel`, etc.) |
| `/dmx.json` | GET | All 512 values, fps, rssi, uptime, heap, manual mode flag |
| `/enc.json` | GET | Rotary-encoder diagnostics: pins, the decoder's effective vs configured steps-per-detent, and counters for quadrature edges and emitted steps. `?reset=1` zeroes them, so `encsteps` can be measured rather than guessed, see [docs/controls.md](docs/controls.md) |
| `/senders.json` | GET | Active Art-Net / sACN senders (also pushed over the WebSocket) |
| `/log.json` | GET | Recent DMX change log entries (also pushed over the WebSocket) |
| `/labels.json` | GET | Channel labels object |
| `/labels` | POST | Store the full labels object (JSON body) |
| `/rdm.json` | GET | RDM controller state + discovered fixtures (TOD), incl. the Art-Net RDM node state (`artnetRdm`, `artPort`, `discovering`) + request counters |
| `/rdm/discover` | GET | Trigger an RDM discovery sweep on the bus (`{ok,op}`) |
| `/rdm/setaddr` | GET | Set a fixture's DMX start address — `?uid=MMMM:DDDDDDDD&addr=1..512` |
| `/rdm/identify` | GET | Toggle a fixture's identify — `?uid=MMMM:DDDDDDDD&on=0/1` |
| `/rdm/bqp` | GET | Set the Art-Net BackgroundQueuePolicy (background RDM status harvest), `?p=1..3` severity, `4` off |
| `/rdm/merge` | GET | Set an output's merge mode, `?out=<index>&mode=0/1/2` (off/HTP/LTP), applied live + persisted |
| `/led/bright` | GET | 5-LED panel per-colour brightness (`?r=&g=&y=&b=&w=`, 0-255), applied live; `&save=1` persists to NVS, `&test=1` lights all five for calibration (10-min window) |
| `/version.json` | GET | Current firmware version + update-available flag. `latest` is `null` when the check hasn't succeeded (it is never faked to equal `current`). The device checks `http://luxdmx.org/firmware/version.txt` over **plain HTTP** — no TLS at runtime, because a handshake needs ~40 KB of contiguous heap that a running gateway doesn't have. The old code used `setInsecure()` (no cert validation), so this gives up no authenticity that existed; the firmware image itself is the thing worth signing |
| `/autoupdate` | POST | Toggle auto-update (`enabled=0/1`) |
| `/ota/upload` | POST | Upload and flash a local `firmware.bin` |
| `/ota/github` | POST | Install a release (downloaded via luxdmx.org; `version=latest` or `1.0.N`) |
| `/ota/url` | POST | Install a `.bin` from any URL the device can reach (`url=http://host/firmware.bin`). Reboots first and downloads with a fresh heap, so it works where a push upload fails; `http://` needs no TLS and therefore almost no contiguous memory |
| `/ota/status` | GET | Live progress of an in-flight install (`{phase,pct}`) — the update page polls it |

### WebSocket (`ws://<device>/ws`, port 80)

Binary status/DMX frame pushed ~10×/s (528 + 2 bytes per output):

```
Bytes  0–1    fps × 10           uint16 big-endian (aggregate, all inputs)
Bytes  2–3    link metric        int16  big-endian (≤0 = WiFi RSSI dBm,
                                   ≥10 = wired link speed Mbps, 1 = standalone AP)
Bytes  4–7    free heap          uint32 big-endian
Bytes  8–11   uptime (s)         uint32 big-endian
Byte   12     active sender count uint8
Byte   13     source status       uint8 (0 = normal, 1 = conflict, 2 = merging)
Bytes  14–15  jitter × 10 (ms)   uint16 big-endian
Bytes  16–527 DMX ch 1–512       uint8[512] (the viewed output)
Bytes  528…   per-output fps × 10 uint16 big-endian × number of outputs
```

The web UI shows the **viewed output's** frame rate in the navbar and each output's own
rate on its selector button. `GET /dmx.json` also carries `"outfps":[…]` alongside `"fps"`.

### Source merging (HTP / LTP)

When more than one console targets the same universe, pick a per-output **merge mode** in `/config`
(or remotely from a console over Art-Net, where an `ArtAddress` `AcMergeHtp`/`AcMergeLtp`/`AcCancelMerge`
is applied live and persisted):

- **Off** — last frame wins; a clash raises the conflict warning.
- **HTP** (highest takes precedence) — each channel is the maximum across the active sources.
- **LTP** (latest takes precedence) — the most recently seen source drives the output.

The **sACN priority** field is honoured first: a higher-priority source wins outright, and equal priority falls back to the mode above (Art-Net joins at the default priority of 100). A source that stops sending drops out of the mix after ~4 s (long enough to ride out a console that throttles to a ~1 Hz keep-alive on a static look, which both sACN and most consoles do). While an output is actively merging, the status page shows a green "merging" indicator instead of the conflict banner.

### Signal-loss behaviour

DMX512 is a continuously-refreshed stream, so LuxDMX keeps clocking the line at its configured rate (40 fps by default) even when the values never change. That's normal, and it's what fixtures expect (a receiver that stops seeing frames runs its own loss timeout). What should happen once **every** source for a universe has gone quiet (no Art-Net/sACN for ~4 s) is a per-output choice in `/config`:

- **Hold last frame** (default): keep refreshing the last values, so a brief network drop or a lost multicast packet never disturbs the look.
- **Blackout**: drive every channel to 0 (still transmitted at the normal rate), so the rig goes dark when the source disappears.
- **Stop sending**: idle the line entirely, letting each fixture fall back to its own DMX-loss behaviour.

Manual control and identify always keep transmitting, whatever the policy. A freshly booted node with no source yet follows the same rule, so an output set to **stop** stays dark until a source appears.

A JSON **text** frame with the sender list + change log is pushed every 2 s
(`{"meta":1,"senders":[…],"log":[…]}`) so the browser never has to poll.

Browser → ESP32 (JSON text):
```json
{ "type": "set",      "ch": 1,  "val": 200 }
{ "type": "mode",     "manual": true       }
{ "type": "blackout"                       }
{ "type": "identify", "ch": 5              }
```

Channel labels are managed over REST (`GET /labels.json`, `POST /labels`).

### Saving settings (and when it restarts)

The save button says **Save**, not "Save & Restart", because most settings no longer need one. The
running firmware re-reads them on every use, so a universe, merge mode, signal-loss policy, output
rate, transmit style, LED brightness, encoder or button role takes effect the moment you save. The
DMX line keeps clocking through it.

Settings bound to a **GPIO** or to a **driver set up at boot** still need a restart: pin
assignments, UART port, LED and display type, and the whole network block (interface, PHY, WiFi,
static IP). When a save touches one of those, the device tells the page which ones, and you get a
dialog naming them rather than an unannounced reboot.

### Output rate and transmit style

A DMX gateway has to decide how fast to clock the wire. Until v1.0.216 LuxDMX free-ran at a fixed
40 fps no matter what the console sent, and that is fine only when the console happens to sit near
40. It isn't always: **MagicQ runs a 33.3 fps engine and MADRIX ships a 33.3 fps default**, and a
fixed 40 fps sampler fed 33.3 fps has to emit roughly one frame in six twice. Measured against a
DMX analyzer, the share of repeated frames tracks `(40 - input) / 40` almost exactly. On a 16-bit
fade that reads as stepping (issue #93).

Both settings are **per output** and apply the moment you save, without a restart.

| Transmit style | What the wire does |
|---|---|
| **Continuous** (default) | Free-runs at the rate below, whatever the source does. Predictable, and what most nodes ship. |
| **Delta** | One DMX frame per actual change from your console, so the wire follows its real update rate and nothing is repeated. Consoles often send each change several times (MagicQ sends it three times, which can look like ~100 packets/s off a 33 Hz engine); Delta ignores the duplicates and tracks the changes. Falls back to free-running after 800 ms of silence, so a held look keeps being refreshed. |

| Rate | Period | Use it when |
|---|---|---|
| 40 fps | 25 ms | default; QLC+, FreeStyler and most software sit here |
| 41.7 fps | 24 ms | fastest we offer; a full 513-slot frame already occupies 22.76 ms |
| **33.3 fps** | 30 ms | **MagicQ and MADRIX** |
| 25 fps | 40 ms | older or fussy fixtures |
| 20 fps | 50 ms | very old gear |

Two ways to fix stepping, then: set the rate to match your console, or switch that output to Delta
and stop thinking about it. Delta is the more general answer but it does hand your console's timing
jitter straight to the fixtures, which is why it isn't the default (ELC and Swisson both warn about
the same thing on their own sync modes).

There is no third option where the console tells us its rate: **neither Art-Net nor sACN has a field
for that**. A node can advertise the rate it accepts (we do, in `ArtPollReply` `RefreshRate`), but
nothing flows the other way. The rate is only ever inferred from how fast packets arrive, which is
what the **In FPS** readout in the navbar shows.

The navbar carries it too: a `C` or `D` per output (continuous or delta), with a dot on any style a
controller pushed over Art-Net, and the full wording in the tooltip. So you can see at a glance
whether a port is free-running or following the console, without opening `/config`.

**Beat warning.** You don't have to spot the mismatch yourself. When a Continuous output is
free-running against a source whose real change rate is off the output rate (e.g. a 33 fps MagicQ
engine into a fixed 40 fps output), the navbar marks that output's style with a **⚠** and the
`/config` page shows a live nudge right under its **Transmit style** dropdown, suggesting Delta. It
tracks the console's *change* rate, not the raw packet rate, so a source that sends each frame three
times still reads as ~33, and it clears the instant you switch to Delta or the two rates line up. A
static look never trips it, and neither does a console already running at the output rate.

A console can select the style remotely with Art-Net `ArtAddress` (`AcStyleDelta` / `AcStyleConst`).
When that happens the `/config` page labels the setting **set over Art-Net** instead of *set here*,
so a mode you did not pick doesn't look like your own doing. Changing it in the web UI takes it back.

---

## Visual pin configuration (board picker)

LuxDMX has a lot of GPIOs to set (status LED, 5-LED panel, OLED, two DMX outputs).
To make this idiot-proof, **Settings → Hardware board** offers:

- **Templates** — pick your board and click **Apply template** to fill every LED /
  display / DMX pin with the tested map in one step. Selecting the *LuxDMX v6*
  board applies the exact pin map of the open-hardware PCB. Your pick is saved with
  the rest of the settings, so it survives reboots and firmware updates. The v6 runs
  the generic ESP32-S3 firmware and can't be told apart from a DevKit by the firmware
  alone, so the page trusts what you picked over what it detects.
- **Click pins on a board diagram** — the pick button next to each GPIO field opens an
  interactive board so you click the actual pin instead of guessing GPIO numbers. The
  diagram colour-codes pins (free / caution / do-not-use) and shows your current
  assignments right on the board. The common dev boards (DevKitC, NodeMCU-32S, DOIT v1,
  S3 DevKitC-1) draw their **real physical header** — USB on the correct edge, every pin
  in its true row with the board's own silk, and the 3V3 / 5V / GND / EN pins shown (greyed,
  so you can wire VCC/GND by it) rather than only the GPIO pins.
- **Pick pins on the connectors too**: a board with wirable connectors (the LuxDMX board's J4
  display and J6 expansion headers) draws each one as a connector strip below the diagram:
  pins in their real order, pin 1 marked, rails greyed and inert, and every signal pin
  clickable. So you can assign display SCL by clicking J6 pin 5 rather than looking up which
  GPIO that is. Each GPIO field also carries a `J4.3` tag telling you which hole it comes
  out of.
- **Live validation** — duplicate pins, strapping/flash/input-only pins and
  Ethernet-reserved pins are flagged in red/amber before you can save.

Five boards are built into the firmware and work fully offline, covering the common
variants (which are **not** all the same pinout):

| Board | Notes |
|---|---|
| LuxDMX v6 | our board (ESP32-S3 + W5500); preset generated from the PCB source |
| ESP32 DevKitC (WROOM-32, 38-pin) | breaks out the flash pins too |
| ESP32 DevKit v1 (DOIT, 30-pin) | narrower, no flash pins on the header |
| ESP32-S3 DevKitC-1 (44-pin) | GPIO33-37 only free on no-PSRAM modules |
| Seeed XIAO ESP32-S3 | tiny board, D0-D10 silk |

The full catalog covers **34 boards** spanning every esp32 / esp32s3 board the firmware
runs on (DevKit / DOIT / NodeMCU, WEMOS LOLIN, Adafruit Feather / QtPy / HUZZAH32 / Metro,
Heltec OLED, Olimex PoE / Gateway / wESP32 Ethernet, Unexpected Maker, M5Stack, LilyGO,
SparkFun ...). It also carries the **Radig ESP32-S3 DMX/RDM Node** kit: a ready-made
carrier whose RS-485 driver and XLR socket are already wired, so picking it and hitting
Apply gives you a working, RDM-capable node without choosing a single pin (its DE/RE line
sits on a real GPIO, which is what RDM needs). Note it is not galvanically isolated.
The boards beyond the five built-ins are pulled lazily from the online
catalog ([web/boards/](web/boards/), served via GitHub Pages) and cached in your browser;
no network means you still get the built-ins plus manual entry. You can switch boards from
a dropdown inside the pin-picker popup itself.

All descriptors are generated from authoritative pinout data
(`hardware/scripts/gen_board_descriptor.py`, which doubles as a drift check over the committed
catalog): `hardware/scripts/luxdmx.py` for our own board, published header
pinouts for the hand-tuned dev boards, and the Arduino core `variants/<dir>/pins_arduino.h`
for the rest, so the GPIO numbers and reserved/strapping/flash flags are accurate per
variant (e.g. the PICO-based Feather V2 frees GPIO6-11 and reserves 16/17 instead). The
picker draws its own horizontal **diagram** for every board; there are no board photos or
realistic graphics.

See [docs/pin-picker.md](docs/pin-picker.md) for the design, the descriptor schema and
how to add a board.

---

## QLC+ Setup

1. Open **Eingänge/Ausgänge** tab
2. Click in the output area right of **Universe 1** → select **ArtNet** → interface = your PC's IP
3. Configure: Output IP = LuxDMX's IP, Art-Net Universe = `0`
4. Set transmission mode to **Full** (sends all 512 channels continuously at ~40 fps)
5. Test with **Einfaches Mischpult** → move fader → grid lights up cyan

> **Universe mapping:** QLC+ "Universe 1" = Art-Net Universe `0`. LuxDMX defaults to Universe `0`.  
> **Tip:** if "Standard" mode shows ~0.4 fps and values don't update, restart QLC+ or switch to "Full" mode.

### Ready-made demo shows

Two QLC+ workspaces are included to test fixtures and show off the gateway — open with **File → Open**, map Universe 1 → ArtNet (above), switch to **Operate** mode, and press the Virtual Console buttons:

| File | Description |
|---|---|
| [`docs/qlcplus-demo.qxw`](docs/qlcplus-demo.qxw) | Small 6-channel demo: fade, blink, running light |
| [`docs/qlcplus-show.qxw`](docs/qlcplus-show.qxw) | **30-minute, 20-channel show** — sine waves, comets, sparkle, VU bounce, crossfades, strobes, build-ups and more, sequenced into an intro→build→peak→groove→outro arc. Press **GREAT SHOW**. |

The big show is generated by [`docs/make_show.py`](docs/make_show.py) — edit the `arc` list and re-run to customize.

---

## Status LED

LuxDMX supports three LED types, configurable in the web UI. All three speak the **same
status language** — the single LED shows it as one colour at a time, the 5-LED panel lights
the matching LED:

| State | WS2812 RGB | 5-LED panel | Plain GPIO |
|---|---|---|---|
| Booting / connecting | white blink | Knight-Rider sweep | blink |
| Up, idle (no DMX in) | green (solid) | green (solid) | on |
| DMX coming in (Art-Net / sACN) | green, slow 2 s blink | green, slow 2 s blink | slow blink |
| RDM discovery / identify / RDM traffic | **green + blue = cyan** | **green stays + blue lights too** | on |
| Ethernet configured but on WiFi/AP fallback | orange (solid) | amber (solid) | on |
| No network at all | red (solid) | red (green off) | off |
| Setup portal / config AP active | purple | purple (blue + white) | on |

A few deliberate choices:

- **Green means "up and running", and it stays on.** RDM does **not** replace it — blue is *added*
  on top. On the panel that's literally two LEDs lit at once (green + blue); on the single RGB LED
  they mix to cyan. So "board is alive **and** doing RDM" reads at a glance, instead of the green
  vanishing whenever a sensor poll fires.
- **DMX *output* is not signalled.** A gateway transmits continuously, so a "DMX out" light is on
  all the time and tells you nothing. The green LED tracks DMX *coming in* from the network instead
  (a slow blink while frames arrive, solid when idle) — and blue can ride on top of that too.
- **Blue is RDM.** On whenever an RDM identify is active or RDM frames moved on the wire in the last
  second (discovery, sensor polling, or a fixture answering).
- **Only health replaces green.** Red (no network) and orange (running on the WiFi fallback because
  the wired link is down) turn the green off, because those aren't "up". Everything else keeps green.

The LED runs on its own task, so serving the web UI never freezes it.

**5-LED status panel** (`ledType 3`, the LuxDMX v6 board) — five discrete LEDs (R G Y B W). Because
they're independent, green (up) and blue (RDM) light **together**; on the single RGB LED the same
pair mixes to cyan. There is no discrete orange LED, so the panel's amber (Y) LED carries the
Ethernet-on-fallback state; purple (setup portal) lights blue + white together.

**Per-colour brightness (PWM).** The five LEDs are driven with PWM, not plain on/off, because
green and white are far brighter per mA than the others — left raw they wash the panel out. Each
colour has its own duty (`ledbrr`/`ledbrg`/`ledbry`/`ledbrb`/`ledbrw`, 0-255) so the panel looks
even; the v6 board defaults dim green/white hard. Tune it live (no reboot) via `/led/bright`
(`?g=8&w=17…`, `&save=1` to persist) — `?test=1` lights all five at once so you can balance them
by eye. **Boot/connecting** runs a Knight-Rider sweep back and forth across the five LEDs; a
single LED shows a white "working" blink instead.

Default GPIO: `2` (ESP32 DevKit on-board LED). ESP32-S3 DevKitC-1 uses GPIO `48` (built-in WS2812).
The v6 board uses **R=1 G=2 Y=6 B=7 W=15**.

---

## Display (OLED / colour OLED)

LuxDMX can drive an **optional status display** that shows the gateway's live state
without a browser — IP, output universe(s), protocol, frame rate, source count and link / DMX
activity — and **auto-switches to a full-screen alert** when something needs attention
(two consoles fighting over the universe, identify, or manual override). It's **off by
default**; enable and pin it under **Settings → Display**.

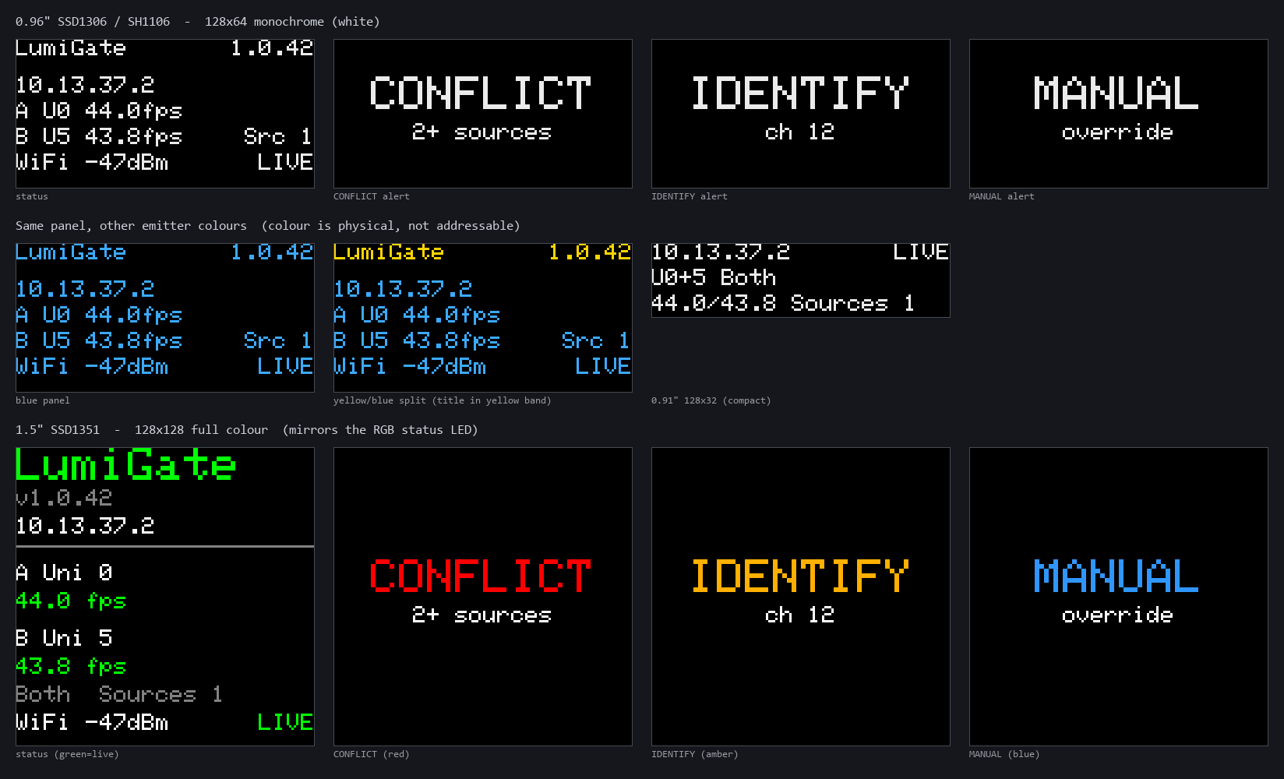
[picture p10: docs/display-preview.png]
LuxDMX display types


*Rendered from the firmware's own layout code with the real display font &nbsp;·&nbsp; regenerate
with [`docs/make_display_preview.py`](docs/make_display_preview.py). **Top:** 0.96″ /
1.3″ mono OLED (status, then the conflict / identify / manual banners). **Middle:** the same
panel in blue and yellow/blue-split, and the 0.91″ 128×32 compact layout. **Bottom:** the
1.5″ SSD1351 colour panel, which mirrors the RGB status-LED language (green = live,
amber = idle, red = conflict).*

The status screen adapts to the number of outputs: a single output shows `Uni 0` with one frame
rate, while **two enabled outputs get a row each** (`A`/`B`) with their own universe and **own
FPS** (shown above). The source count is labelled **Sources** (active Art-Net / sACN senders).

### Supported panels

| Panel | Controller | Bus | Pins | Boards |
|---|---|---|---|---|
| 0.96″ / 1.3″ OLED 128×64 | SSD1306 / SH1106 | I²C | 2 | all |
| 0.91″ OLED 128×32 | SSD1306 | I²C | 2 | all |
| 1.5″ colour OLED 128×128 | SSD1351 | SPI | ~5 | ESP32 / ESP32-S3 (not the Ethernet boards) |

Mono panels are 1-bit — white, blue and yellow/blue-split versions all behave identically
(the colour is the physical emitter, not addressable). The I²C address is auto-detected
(`0x3C` / `0x3D`). SPI colour panels need ~5 pins, so they only fit the non-Ethernet boards.

> **Two identical headers, and either cable fits.** The board has **J4 (display)** and **J6
> (expansion)** side by side, same JST SH 9-pin part. They deliberately share the same power pins
> (`1=+3V3 2=GND`), so plugging a cable into the wrong one does nothing worse than leave the display
> sitting in reset. A hard validator fails the fab export if that ever stops being true —
> [docs/display.md → Header safety](docs/display.md#header-safety-j4-vs-j6).

### Settings (Settings → Display)

| Field | Notes |
|---|---|
| Display type | off / SSD1306 128×64 / SSD1306 128×32 / SH1106 128×64 / SSD1351 colour |
| SDA, SCL | I²C pins (mono panels). Avoid strapping pins like GPIO12; WT32-ETH01 → `14` / `15` |
| CS, DC, RST, SCK, MOSI | hardware-SPI pins (colour panel) |
| Orientation | normal / flipped 180° |

See [docs/display.md](docs/display.md) for the full design — per-board pin tables and layout details.

---

## DMX Outputs

LuxDMX drives up to **2 independent DMX outputs** — each its own universe, UART port and
RS485 transceiver — configurable at runtime under **Settings → DMX Outputs** (no recompile).
The 2-output ceiling is a hardware limit: the ESP32 / ESP32-S3 expose 3 UARTs and UART0 is the
serial console, leaving UART1 + UART2. **Output B ships disabled**, so single-universe setups are
unchanged, and devices updated from older firmware keep their existing output as Output A.

Per output:

| Setting | Default (Output A / B) | Description |
|---|---|---|
| Enabled | A on / B off | Whether this output drives a DMX line |
| Universe | `0` / `1` | Art-Net universe (sACN universe = this + 1). Range 0–15 |
| UART port | `1` / `2` | Which ESP32 UART drives the line. Each enabled output needs a **distinct** port |
| TX pin | `17` (GPIO17) | ESP32 GPIO that drives the RS485 module's DI (data-in) |
| RX pin | `16` (GPIO16) | ESP32 GPIO connected to the RS485 module's RO (data-out); needed for RDM |
| RTS / DE pin | `−1` (disabled) | RS485 direction-control pin. −1 for auto-direction modules (Waveshare C). Required for RDM. |

Setting **both outputs to the same universe** turns LuxDMX into a 1-in / 2-out DMX splitter.
**RDM** runs on the first enabled output with an RTS pin set (one output at a time). For
multi-universe input, **Art-Net is recommended** (single UDP socket, no IGMP); sACN works too
(one multicast group joined per universe).

> **WT32-ETH01:** the Ethernet PHY consumes most GPIOs, so a second output is best run
> output-only (TX, no RX/RDM).

### Per-board defaults & capabilities

Applied on first boot; everything is overrideable in the web UI (no recompile).

| Board | Build env | Net | Outputs | Output A — TX / RX / RTS | Suggested Output B | Notes |
|---|---|---|---|---|---|---|
| ESP32 DevKit (WROOM-32) | `esp32dev` | WiFi | 2 | GPIO17 / 16 / −1 | UART2, TX 32, RX 33 | Plenty of free GPIO; RDM possible on both |
| ESP32-S3 DevKitC-1 | `esp32s3dev` | WiFi | 2 | GPIO17 / 16 / −1 | UART2, TX 18 (RX −1) | LED = WS2812 on GPIO48; v3 build disables the brownout detector (`CONFIG_ESP_BROWNOUT_DET=n`, a from-source build) to avoid an S3 boot-loop |
| WT32-ETH01 | `wt32eth01` | Ethernet | 2 | GPIO4 / 5 / −1 | UART2, TX-only | GPIO16 = LAN8720 PHY power, so pins are shifted; 2nd output best TX-only (no RX/RDM) |
| LuxDMX v6 (ESP32-S3 + W5500) | `esp32s3dev` + **LuxDMX v6** template | Ethernet (W5500 SPI) | 2 | GPIO17 / 18 / 8 | UART2 | Open-hardware board ([hardware/](hardware/)). No dedicated build — flash `esp32s3dev` and apply the **LuxDMX v6** template in `/config` for the fixed pin map. 5-LED status panel; W5500 on SPI3 (CS=10/INT=14/RST=9); RTS/EN=8 for RDM direction |
| ESP32-S3 with **octal** PSRAM (N8R8 / N16R8) | `esp32s3_psram` | WiFi | 2 | GPIO17 / 16 / −1 | UART2, TX 18 | Enables the 8 MB **octal** PSRAM: RDM tables, WiFi/lwIP buffers and pixel framebuffers move to external RAM, so the RDM cap auto-detects to 64 and the internal heap stays open. Measured on an N16R8: 8 MB found, 121 KB internal heap free against 57 KB with the plain image. **Octal only.** Quad vs octal is fixed at build time on the ESP32-S3, so a module with 2 MB *quad* PSRAM (`R2`) runs the plain `esp32s3dev` image and simply does not use its PSRAM. Folding quad into that image was tried and dropped on purpose: it would change the firmware every S3 in the field auto-updates to, in exchange for a size of PSRAM none of our boards use. PSRAM occupies GPIO33-37, DMX on 16/17 is clear |

**Any ESP32 / ESP32-S3 build can add wired Ethernet with an external SPI module**: the W5500 and
DM9051 drivers are compiled into every build. In **`/config` &rarr; Wired Ethernet** pick the chip
(**W5500** or **DM9051**), set its pins, then enable **Use wired Ethernet**. The two share the same
SPI wiring, so one pin card serves both. Pins default to the classic-ESP32 VSPI set (CS=5 / SCK=18 /
MOSI=23 / MISO=19 / INT=4 / RST=25) and are fully configurable (with the on-board pin-picker). The
**SPI clock** is set by **W5500 SPI MHz** (`ethfreq`, default **20**, range 1 to 80); 20 MHz is fine
on a real board, but drop it to ~8 MHz if the module is on long flying leads and is not detected (the
bring-up can otherwise hang). No special build is needed.

The **DM9051** is a W5500 alternative (sometimes easier to source). It's wired in and selectable, but
nobody's had one on the bench yet, so it's **untested on real hardware** so far. The W5500 path is
unchanged.

On a **classic ESP32** the card also lists the **ESP32 built-in MAC + RMII PHY** options (the
WT32-ETH01 style) alongside the SPI modules. The S3 has no internal MAC, so it only offers the SPI
modules (W5500 / DM9051).

When **RMII** is selected you can set the **PHY family** (LAN8720/LAN8742, IP101, RTL8201, DP83848,
KSZ8081, JL1101), the **PHY address**, the **MDC / MDIO / PHY-power** GPIOs and the **REF_CLK mode**
(GPIO0 in, or GPIO0 / 16 / 17 out). Defaults match the WT32-ETH01 (LAN8720) wiring, so a board wired
that way needs no changes. The RMII **data lines are fixed by the EMAC** (TXD0 19, TXD1 22, TX_EN 21,
RXD0 25, RXD1 26, RX_DV 27) and can't be moved; the pin-picker reserves those plus your configured
management / clock / power pins, so a DMX or LED pin that lands on one is flagged.

> **Not supported: ENC28J60.** The old blue ENC28J60 SPI modules don't work here. arduino-esp32's
> `ETH` library has no driver for them (its SPI options are W5500 / W6100 / DM9051), so there's
> nothing to call. They're also only 10 Mbit with an 8 KB buffer and no hardware TCP/IP stack, which
> is the wrong end of the trade for Art-Net/sACN under full DMX load. Use a **W5500** instead: same
> SPI bus, costs about the same, full hardware stack, and it's already built in.

> **All boards drive two outputs.** A 2nd output used to panic on the ESP32-S3 back when DMX went
> out over the UART: a latent **esp_dmx 4.1.0 bug** where the UART2 entry was guarded by an enum the
> preprocessor reads as 0, so it was compiled out (null peripheral pointer), and it needed a
> build-time patch to work at all. DMX is clocked out of the **RMT** peripheral now (`dmx_rmt.h`),
> and esp_dmx is gone from the project entirely, so neither the bug nor the patch exists any more.

**ESP32-S3 — safe GPIOs for a 2nd output:** free choices are **5, 6, 7, 8, 15, 18, 21**. Avoid
**26–37** (SPI flash / octal PSRAM — *will* crash), **19/20** (USB), **43/44** (serial console),
**0/45/46** (strapping), **48** (WS2812 LED), and Output A's **16/17**.

**Using a different RS485 module?** Wire your module's DI (data-in) to the TX GPIO and RO (data-out)
to the RX GPIO, then set the pins under Settings → DMX Outputs.

### Upgrade & crash safety

- **Existing single-universe devices are unaffected by the update.** Migration maps the old
  single-output config to **Output A** and leaves **Output B disabled**, so exactly one driver is
  installed on UART1 — byte-for-byte the same path as before.
- **No configuration can brick the device.** A safe-boot guard persists a crash counter around DMX
  init; if init ever panics (a bad pin/port), the next boots progressively disable outputs (keep
  A → all off) until the web UI is reachable. An enabled output with no TX pin is sanitized off
  automatically (firmware + a client-side check).

---

## Persistent Configuration (NVS)

| Key | Default | Change via |
|---|---|---|
| Art-Net Universe | `0` | Web `/config` or portal |
| Protocol | `Both (Art-Net + sACN)` | Web `/config` |
| Static IP / gateway / subnet / DNS | DHCP | Web `/config` (Network) |
| Art-Net remote IP config (`ipprog`) | **off** | Web `/config` (Network) |
| Art-Net node name, short (`artshort`) | — (falls back to the hostname) | Web `/config` (Device), or a console via `ArtAddress` |
| Art-Net node name, long (`artlong`) | — (falls back to the hostname) | Web `/config` (Device), or a console via `ArtAddress` |
| Auto-update | off | Web `/config` (Firmware) |
| RDM over Art-Net (`artrdm`) | on | Web `/config` (RDM) |
| RDM device limit (`rdmmaxdev`) | `0` (auto: **64** on ESP32-S3 / PSRAM, **16** on the classic ESP32) | Web `/config` (RDM) |
| Channel labels | — | Status page (channel modal) |
| Hostname | `dmx-gateway` | Web `/config` |
| OTA Password (IDE `espota` only) | `dmxota` | Web `/config` |
| LED type / GPIO pin | board default | Web `/config` (Status LED) |
| Per-output: enabled / universe / UART port / TX / RX / RTS | A on (uni 0, UART1, TX=17, RX=16, RTS=−1); B off | Web `/config` (DMX Outputs); the universe also from a console via `ArtAddress` |
| Display type / pins | off | Web `/config` (Display) |
| WiFi credentials | — | Setup portal, Web `/config` (Network), or `/reset` |

---

## Testing

End-to-end Playwright tests drive a **live device** — they inject real Art-Net and sACN/E1.31
packets over the network and assert the REST API, WebSocket and web UI react correctly (Art-Net/sACN
→ DMX, sender tracking, conflict banner, change log, manual override + blackout, labels, and the
2-output feature). See [`docs/tests/README.md`](docs/tests/README.md).

```bash
cd docs && npm install && npx playwright install chromium
LUXDMX_HOST=dmx-gateway.local npm test
```

---

## License

MIT — do whatever you want, attribution appreciated.

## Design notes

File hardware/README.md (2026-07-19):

> [!NOTE]
> **v6 has not been fabricated yet.** The board is on `master`, design-complete, and passes the full
> scripted validation (DRC, isolation, SPICE, Ethernet skew, header parity; see **VALIDATION.md**).
> An earlier spin of this design was built and came up working (rails, galvanic isolation, PoE
> standalone, both DMX universes bit-exact, RDM 64/64 on both lines), but v6 carries changes that
> have not been on physical copper yet: native USB instead of a CH340 bridge, TPS2116 priority mode,
> a 3225 crystal package, and the J4/J6 header re-pin. Those are what the first v6 article has to
> prove. Treat it as a prototype: the firmware on a plain ESP32 + an isolated RS-485 module is still
> the longest-proven path (see the main README). The ruggedization pass (USB ESD, PTC fuse, +5V TVS,
> a TPS2116 priority power mux, DMX common-mode chokes, ferrite supply filters), plated GND mounting
> holes, wider power traces, and the DMX512-A "Protected" series-TBU front end are all in.

# LuxDMX v6 — hardware

A compact, open-source **Art-Net / sACN → galvanically-isolated DMX512 gateway**, built around
an ESP32-S3 with **both** WiFi *and* wired Ethernet. Designed entirely as code (SKiDL netlist) and
routed by a fully-scripted, placement-driven pipeline — so the board regenerates itself from your
component placement, isolation barrier and all.

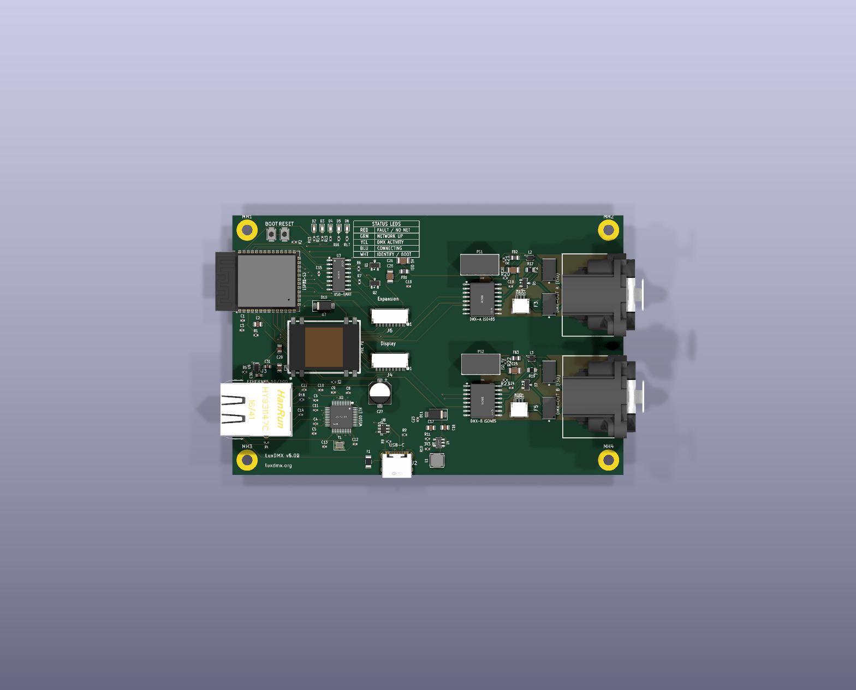
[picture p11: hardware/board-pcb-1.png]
LuxDMX v6 — PCB layout


<p align="center">
  3D render — front
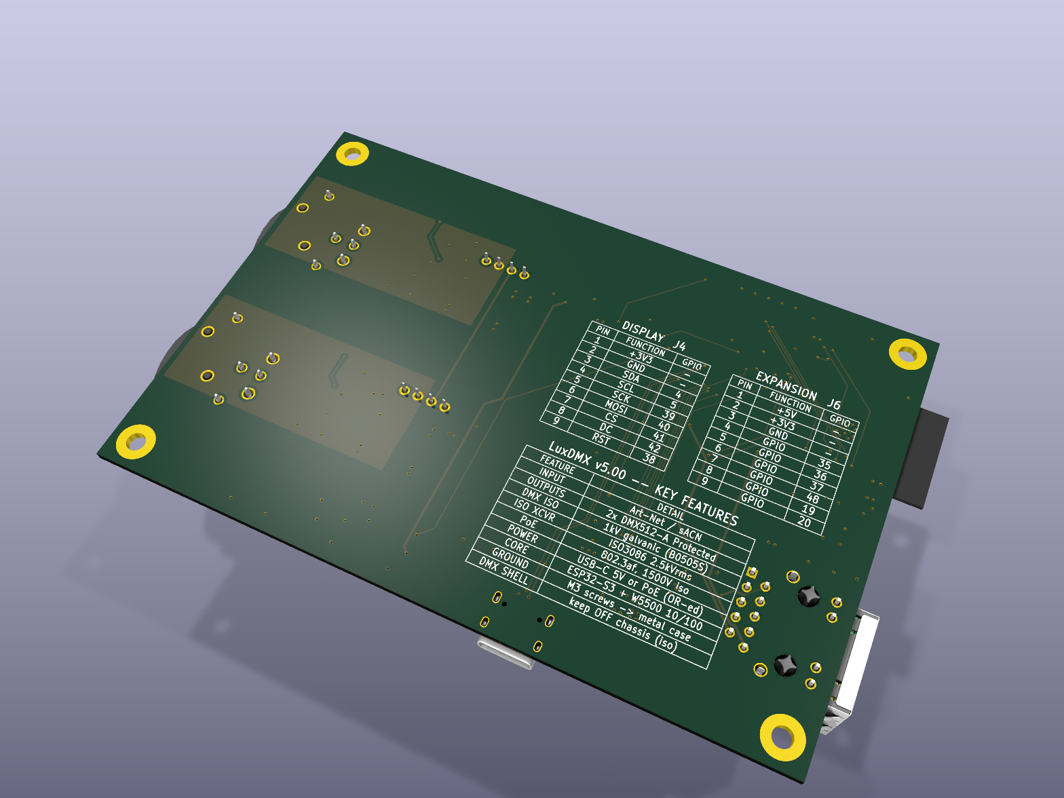
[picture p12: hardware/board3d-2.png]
3D render — reverse
  
</p>

---

## What problem does it solve?

Lighting consoles and media servers speak **Art-Net** or **sACN (E1.31)** over a network. Fixtures —
dimmers, moving heads, hazers, LED bars — speak **DMX512** over an isolated RS-485 bus. LuxDMX sits
between them: it receives Art-Net/sACN over WiFi or Ethernet and emits a clean, **opto-isolated DMX512**
signal. It's the box that lets you drive a rack of conventional stage gear from QLab, a grandMA, or any
Art-Net source — without dragging a laptop and a USB-DMX dongle around backstage.

The whole device runs on a single ESP32-S3, fits on a board you can hold in your palm, and costs a few
dollars to fabricate at JLCPCB.

---

## Headline design decisions (the "why")

| Decision | Why |
|---|---|
| **ESP32-S3** as the MCU | Plenty of GPIO, fast dual-core, native USB, mature Arduino/IDF support, and cheap. The **N8R2** brings 8 MB flash + **2 MB PSRAM**, and because that PSRAM is **quad**, it leaves **GPIO35–37** free for the expansion header. Only the **octal**-PSRAM parts (R8 and up) wire GPIO33–37 to the memory and lose them. |
| **W5500 SPI Ethernet** (not the ESP's RMII) | The S3 has **no built-in Ethernet MAC** (unlike the original ESP32), so RMII/LAN8720 is physically impossible. The W5500 is a self-contained TCP/IP-offload Ethernet controller on SPI — the *only* practical wired-Ethernet path for the S3. Wired Ethernet matters: a packed venue's 2.4 GHz band is hostile, and a show can't drop frames. |
| **Galvanically-isolated DMX** | DMX runs long cables between gear sitting on different mains circuits with different ground potentials. Without isolation you get **ground loops** (noise, flicker) and, worse, **fault currents** that can destroy the gateway when something downstream shorts. Pro DMX gear is *always* isolated. We isolate both the data (ISO3086) and the power feeding it (B0505S DC-DC), so the DMX domain shares **no copper** with the logic side. |
| **USB-C** | Reversible, modern, and carries both **power and native flashing** — one cable to power and program. |
| **4-layer PCB** | A solid inner ground plane gives the W5500's Ethernet pairs a 100 Ω reference, tames EMI, and makes the dense routing actually fit. (More below.) |

---

## The components, in detail

### Brains & networking
- **U1 — ESP32-S3-WROOM-1-N8R2** *(LCSC C2913204; 8 MB flash + 2 MB quad PSRAM)* — the MCU + 2.4 GHz WiFi radio. Runs the Art-Net/sACN
  receiver, the web UI, OTA updates, and the DMX engine. The PCB antenna hangs over the left board edge
  (no copper underneath it — intentional, for radiation efficiency).
- **U2 — WIZnet W5500** *(C32843)* + **Y1 — 25 MHz crystal, 3225** *(C9006, CL = 12 pF, load caps C12/C13 = 18 pF C0G)* + **J3 — HY931147C PoE RJ45 MagJack** *(C91754)* —
  a complete 10/100 wired-Ethernet subsystem on SPI. The magjack integrates the isolation magnetics,
  the link/activity LEDs, **and an internal PoE rectifier** (Mode A + Mode B → a single rectified DC pair
  on pins 9/10 — see *Power*). (Ethernet is isolated by the magjack's transformers; the W5500's
  current-mode TX center-tap is biased to 3V3 on the chip-side tap, independent of the PoE extraction
  on the cable side.)

### Isolated DMX output — two independent universes
Each universe is a self-contained galvanic island; the two share no copper with each other or the logic side.
- **U5 / U6 — TI ISO3086DWR** *(C183095)* — the **isolated RS-485 transceivers** (one per universe). The DMX
  driver and the logic that controls it are separated by a silicon isolation barrier rated for kilovolts.
  Wired 2-wire (Y↔A, Z↔B bridged) for standard DMX512. Universe 1 on UART/port 1, universe 2 on port 2.
- **PS1 / PS2 — B0505S-1W** *(C7465127)* — the **isolated 5 V→5 V DC-DC** modules powering the *secondary*
  side of U5 / U6. Because both the data path **and** its power are isolated, each DMX connector shares no
  ground with anything else.
- **D1 / D7 — SM712 TVS** *(C404012)* + **R12 / R19 — 120 Ω termination** — per-universe surge protection
  clamped to that universe's isolated ground, and the standard RS-485 line termination.
- **F2–F5 — Bourns TBU-CA065-200-WH** *(C913221)* — a series **high-speed protector** on each DMX data line:
  the DMX512-A **"Protected"** (E1.11 Annex C) front end. It blocks a sustained fault (someone plugging mains,
  or up to ±42 V, into the XLR) in under a microsecond and self-recovers, so the SM712 only ever sees the
  sub-microsecond transient. Full breakdown in [`E1.11_COMPLIANCE.md`](E1.11_COMPLIANCE.md).
- **R20–R23 — 470 Ω fail-safe bias** — hold each idle DMX pair in the RS-485 fail-safe state (needed for RDM).
- **J1 / J5 — XLR-5** *(C368501)* — the two DMX output connectors (Neutrik NC5FAH), each living entirely on its isolated domain.
- Nets: universe 1 = `VISO`/`GNDISO`/`DMX_A`/`DMX_B`; universe 2 = `VISO2`/`GNDISO2`/`DMX2_A`/`DMX2_B`.

### Power — USB-C **or** PoE (PoE has priority)
- **PoE (802.3af):** the **J3** magjack rectifies PoE internally and outputs DC on **`VPOE+`/`VPOE-`** →
  **U7 — SDAPO DP9900M-5V** *(C5380106)*, an **isolated PD + DC-DC module** (36–57 V in, regulated 5 V out,
  1.5 kV isolation, class 0 ≈ 13 W — far more than this board's ~2–3 W). **D10 — SMAJ58A** *(C110521)* clamps
  surges on the rectified rail. The module's `-VDC` becomes board GND; its `+VDC` is the PoE 5 V source.
- **5 V source select:** **U9 — TPS2116** power mux feeds the board **`+5V`** rail from either the **PoE 5 V**
  (`+5V_POE`, on VIN1) or the **USB-C 5 V** (`+5V_USB`, through the F1 PTC, on VIN2), with no backfeed. It runs
  in **priority mode**: `MODE` is tied to VIN1, so **PoE wins whenever it is present** and the board falls back
  to USB only when PoE goes away. The **PR1 divider (R24 = 30 kΩ / R25 = 10 kΩ)** sets the VIN1 switchover
  threshold to **Vsw = 4.0 V** (VREF 1.0 V × (30 + 10) / 10). Vsw is deliberately high, because VOUT tracks VIN1
  down until the switch actually fires: at 4.0 V the `+5V` rail stays far above the ESP's ~2.8 V hang threshold
  while PoE collapses. The pass-FET drop is only ~30 mV (vs ~0.4 V for a Schottky), so `+5V` stays ≈ 4.9 V on
  USB and the B0505S / ISO3086 VCC2 rail clears its 4.5 V minimum across the whole USB range. Input caps
  **C30 / C31** (1 µF), bulk **C29** (22 µF).
  *(The first article tied `MODE`/`PR1` to GND, which is the default "higher voltage wins" mode. With two
  near-equal 5 V sources that hunts, and a PoE→USB handover hung the board. Priority mode is that fix.)*
- **U4 — SY8089 buck** *(C78988)* + **L1 — 2.2 µH** — steps the muxed 5 V down to **3.3 V**. The feedback
  divider is **R10 = 45.3 kΩ / R11 = 10 kΩ → 3.318 V** (SPICE-verified). Powers everything on the logic side.

### Programming & USB — native, no bridge chip
- **J2 — USB-C** *(C165948)* — the USB data + power inlet, wired **straight to the ESP32-S3's native USB**
  (`USB_DM` → IO19, `USB_DP` → IO20). The S3's **USB-Serial-JTAG** peripheral sits in ROM, so a bare USB-C cable
  gives you the flashing port, the serial console **and** JTAG debug with **no bridge chip**. `esptool` resets
  the chip over USB by itself, so there is no auto-reset circuit either.
- **R8 / R9** (5.1 kΩ) — the USB-C **CC pulldowns (Rd)** that tell a host to supply 5 V.
  **U8 — USBLC6-2SC6** *(C7519)* — ESD clamp across the data pair. **F1** — self-healing PTC on VBUS.
- **UART0 is free** and broken out on **J6 pins 7/8** (`S3_TX` / `S3_RX`), since nothing spends it on a bridge.
  *(The first article carried a **CH340C (U3)** plus a **Q1/Q2** 2-transistor auto-reset. Its collectors were
  swapped, so EN and IO0 sat on the wrong transistors: flashing needed the manual BOOT-button dance, and a tool
  asserting DTR or RTS alone could yank EN or IO0. Rather than re-wire it, the bridge and the reset circuit are
  gone entirely, 6 parts fewer and 2 fewer part numbers to source.)*

### User interface & features
- **D2–D6 — 5 status LEDs** (red/green/yellow/blue/white) wired straight to GPIOs (IO1/2/6/7/15): network
  state, DMX activity, source-conflict, identify — at-a-glance status without a screen.
- **SW1 (BOOT) / SW2 (RST)** — `B3U-1000P` tact switches *(C231329)*. BOOT doubles as the config-portal /
  factory-reset button in firmware; RST is a hard reset.
- **J4 — JST SH 1.0 mm 9-pin display header** — an **optional on-board OLED/TFT status panel** connector.
  Carries **both** I²C (SDA/SCL → for SSD1306/SH1106 mono OLEDs) **and** SPI (SCK/MOSI/CS/DC/RST → for
  SSD1351 colour OLED / ST7789 TFT) on free, non-strapping GPIOs. JST SH is tiny and uses widely-available
  pre-crimped cables. *(Optional — populate only if you want the panel.)*
- **J6 — JST SH 1.0 mm 9-pin expansion header** — six free, non-strapping GPIOs for I²C / SPI / UART / PWM /
  ADC add-ons, plus 3V3 and two grounds. Any pin muxes to whatever the S3's GPIO matrix supports, so the port
  can run an I²C bus and a SPI bus at once. *(Optional.)*

#### Both headers share one power layout — on purpose

J4 and J6 are the **same connector**, so a cable fits either one. Their power pins are therefore
**identical**, and a validator (`scripts/validate_header_parity.py`, hard gate) keeps them that way:

| pin | J4 — display | J6 — expansion |
|---|---|---|
| **1** | **+3V3** | **+3V3** |
| **2** | **GND** | **GND** |
| 3 | SDA (IO4) | IO35 |
| 4 | SCL (IO5) | IO36 |
| 5 | SCK (IO39) | IO37 |
| 6 | MOSI (IO40) | IO48 |
| 7 | CS (IO41) | TX0 (IO43) |
| 8 | DC (IO42) | RX0 (IO44) |
| 9 | RST (IO38) | GND |

Plug a cable into the wrong header and nothing dies: the module still gets correct power, and only 3V3 CMOS
signals land in the wrong places. A mis-plugged display sees GND on its RST and just sits quietly in reset.

> **There is no +5V on J6** — feed 5 V loads from your own supply. Dropping it is what lets both
> headers share one power layout, and there was no free non-strapping GPIO left for a 7th signal
> anyway, so pin 9 became a second ground. See
> [docs/display.md → Header safety](../docs/display.md#header-safety-j4-vs-j6).

---

## Feature summary

- 🎛 **Art-Net + sACN (E1.31)** input, configurable universe(s)
- 🎚 **Two independent, separately-isolated DMX512 universes** — two XLR-5 outputs, each on its own
  isolation island (RDM-capable transceivers); drive two universes from one box
- 🌐 **Dual connectivity** — WiFi (captive-portal setup) *and* wired Ethernet (W5500)
- ⚡ **Power-over-Ethernet (802.3af)** — single Cat-5 cable for data *and* power; **or** USB-C — the TPS2116
  mux gives **PoE priority** and falls back to USB, so either works and you can hot-swap between them
- 🖥 **Optional OLED/TFT status display** (I²C or SPI, via the JST header)
- 💡 **5 status LEDs** + BOOT/RST buttons
- 🔌 **USB-C** — single-cable power + native flashing, plus **OTA** updates
- 🟢 Open hardware, JLCPCB-assemblable

---

## The 4-layer board & the isolation barrier

**Stack-up:** 4-layer, JLCPCB **JLC04161H-7628** (1.6 mm; L1–L2 prepreg 0.2104 mm, Er 4.05 — the dielectric the Ethernet pairs are impedance-tuned to). The two inner layers are
**ground-filled signal layers** — not classic "power planes". That's deliberate: as signal layers the
autorouter will happily route ground (and fine-pitch escapes) to the inner copper, while the fill still
gives every trace a solid 0.21 mm-away reference. The result: clean ~100 Ω Ethernet pairs and good EMI.

**Isolation:** three barriers, all enforced by net-based rules in [`luxdmx.kicad_dru`](luxdmx.kicad_dru):
- **DMX universe 1** (`GNDISO`/`VISO`/`DMX_A`/`DMX_B`) and **universe 2** (`GNDISO2`/`VISO2`/`DMX2_A`/`DMX2_B`)
  are each held **≥ 4 mm** from all other copper. Their barrier parts — **PS1/PS2** (B0505S, 2.5 mm pitch)
  and **U5/U6** (ISO3086) — are *courtyard-exempted* (isolation internal/rated), like the USB-C pads.
- **PoE-hot** (`VPOE+`/`VPOE-`, the magjack→module rectified rail) is held **≥ 2.5 mm** from everything else;
  the 1.5 kV PD isolation itself is internal to **U7** (DP9900M) and **J3** (magjack), so their courtyards
  are exempt. The board's only galvanic tie to the PoE line is through the module + magjack magnetics.

The inner ground planes are **carved** (keepout rule-areas) around every isolated/hot region so no inner
copper crosses any barrier — [`scripts/rebuild_iso.py`](scripts/rebuild_iso.py) regenerates this for all three domains from
the live part positions.

---

## Design-as-code & the routing pipeline

> [!CAUTION]
> **Do not run the pipeline steps casually on the committed board.** Everything in the list below that
> touches the `.kicad_pcb` (`sync_board`, `rebuild_iso`, `escape_connectors`, `autoroute_fr2`,
> `cleanup_pads`, `normalize_silk`, `widen_eth`, `tighten_poe_void`, `finish_partial`, `route_tbu`,
> `build_v3`) **rewrites** it. The board as committed carries **hand-made placement and silk edits** that
> those steps would wipe out. They are the tools for a *deliberate re-route from a new placement*, not a
> "refresh". Re-running them by reflex is how you lose a day.
>
> **Always safe** (read the board, never write it): `scripts/luxdmx.py` (writes only the netlist),
> `gen_schematic` / `gen_bom_from_board` / `gen_cpl` / `gen_gerbers` (write only outputs), and every
> `validate_*` gate.

The board is **generated, not hand-drawn**. [`scripts/luxdmx.py`](scripts/luxdmx.py) is a [SKiDL](https://github.com/devbisme/skidl)
netlist — the single source of truth for every part and connection. From a placement, the rest is scripted
and **adapts to wherever you put the parts**:

```text
0. python scripts/luxdmx.py            # SKiDL → luxdmx.net (only after editing the netlist source)
0b python scripts/sync_board.py          # add NEW/changed parts to the board, KEEPING existing placement,
                                 #   gridded in the enlarged area (scripts/build_v3.py = full from-scratch grid)
1. place / move parts in KiCad   →  save
2. python scripts/rebuild_iso.py         # regenerates inner GND planes + the two GNDISO pours + the three
                                 #   isolation keepouts (DMX1/DMX2/PoE) from LIVE positions — no hardcoded coords
3. python scripts/escape_connectors.py   # escapes the few fine-pitch connector pins to LOCKED vias
4. python scripts/autoroute_fr2.py       # Freerouting 2.2.4 routes the whole board, keeping locked escapes
5. python scripts/cleanup_pads.py        # mounting posts → NPTH, widen tight THT annular rings
```

Run everything with the **KiCad 10 bundled Python** (it ships `pcbnew`). `scripts/autoroute_fr2.py` drives
**Freerouting 2.2.4**, which needs **Java 25+**; the jar and a portable JDK live in `tools/` (git-ignored).
Locked tracks survive every re-route (KiCad exports them as DSN `(type fix)`), so connector escapes only
get done once. Move a part, re-run — done.

> **Adding the dual-universe + PoE parts to an existing board:** [`scripts/sync_board.py`](scripts/sync_board.py) is the
> incremental path — it keeps every already-placed footprint where it is, refreshes pad nets (e.g. J2's VBUS
> moving onto `+5V_USB`), swaps J3 to the PoE magjack, and drops the brand-new parts (U6/PS2/J5/D7, U7/D10,
> the new caps) in a grid on the right of the enlarged outline for you to place. Then run the normal
> 2→5 pipeline. `scripts/build_v3.py` remains the full from-scratch grid build if you'd rather re-place everything.

---

## Fabricating it at JLCPCB

Everything you upload is already generated in this folder.

### 1 — Bare PCB
1. Go to [jlcpcb.com](https://jlcpcb.com) → **Add gerber file** → upload **`luxdmx_gerbers.zip`**.
2. It auto-detects **4 layers**. Set: **Layers = 4**, Thickness **1.6 mm**, Impedance control =
   **JLC04161H-7628** stackup (the one the board's Ethernet impedance is designed for). Surface finish your choice (ENIG
   recommended for the fine-pitch parts).

### 2 — Assembly (SMT)
3. Enable **PCB Assembly**, then upload:
   - **BOM** → `luxdmx_BOM_jlcpcb.csv`
   - **CPL / pick-and-place** → `luxdmx_CPL.csv`
4. In the BOM matching step, confirm each LCSC part (they're all pre-filled, every line in JLC stock). The
   optional display / expansion headers **J4 / J6** (JST SH 9-pin, C160408) are in the BOM — mark them **Do
   Not Populate** if you don't want the on-board panel.
5. **Review the placement preview** — the CPL is rotation/position-corrected by `scripts/gen_cpl.py`, so parts
   should sit correctly. The ESP32-S3's antenna intentionally overhangs the left edge.

### 3 — Through-hole parts
The XLRs (J1, J5), USB-C (J2), PoE MagJack (J3), B0505S modules (PS1, PS2) and the DP9900M PoE module (U7)
are through-hole / module parts. Either add JLCPCB's through-hole assembly or hand-solder them — they're all
large, easy joints.

### Cost ballpark
4-layer, this size, 5 pcs ≈ **a few dollars** for the bare boards; SMT assembly adds the parts + a setup
fee. A complete, assembled prototype lands well under typical hobby budgets.

---

## Files

| File | What |
|---|---|
| `scripts/luxdmx.py` | **SKiDL source** — authoritative netlist (`python scripts/luxdmx.py` → `luxdmx.net`) |
| `luxdmx.kicad_pcb` / `.kicad_pro` | the board + KiCad project |
| `luxdmx.kicad_dru` | custom design rules — the two 4 mm DMX isolations, the 2.5 mm PoE isolation + exemptions |
| `scripts/sync_board.py` | **incremental** netlist→board: keep existing placement, grid the new parts (dual-universe + PoE) |
| `scripts/build_v3.py` | full from-scratch grid build (clears + re-drops every part) |
| `scripts/rebuild_iso.py` · `scripts/escape_connectors.py` · `scripts/autoroute_fr2.py` · `scripts/cleanup_pads.py` | the routing pipeline |
| `route.py` · `autoroute.py` | older Freerouting-1.9 fallbacks (no Java 25 needed) |
| `scripts/gen_bom_from_board.py` → `luxdmx_BOM_jlcpcb.csv` | JLCPCB assembly BOM |
| `scripts/gen_cpl.py` → `luxdmx_CPL.csv` / `.xlsx` | JLCPCB pick-and-place (corrected) |
| `luxdmx_gerbers.zip` | 4-layer gerbers + PTH/NPTH drill — the fab upload |
| `easyeda/` | LCSC/easyeda footprints + 3D models for the specific parts |
| `tools/` | Freerouting 2.2.4 jar + portable JDK 25 *(git-ignored — see Toolchain)* |
| `board-pcb-1.png` · `board3d-1.png` · `board3d-2.png` | layout + 3D renders |

## Status

> **Design-complete, fully validated, and the first spin is being fabricated.** Not yet bench-tested on
> real hardware, so treat this first spin as a prototype.

The board (two isolated DMX universes + PoE, **119 × 79 mm**, 4 corner plated M3 mounting holes) is
**fully routed** (0 unrouted, 0 unconnected) and passes the scripted validation:

- **DRC:** 3 clearance waivers only (2× W5500 0.5 mm-pitch escapes at 0.174 mm, USB-C CC2 at 0.160 mm),
  all above JLCPCB's 0.0889 mm floor. 0 silk-over-pad, 0 courtyard overlaps, 0 dangling vias.
- **Isolation:** 0 violations of the two 4 mm DMX and the 2.5 mm PoE creepage rules (`luxdmx.kicad_dru`).
- **Power:** SPICE-verified. The TPS2116 priority mux holds +5V at ~4.9 V on USB, so the B0505S / ISO3086
  VCC2 stays above its 4.5 V minimum across the whole USB range (>= 4.6 V even at a sagging 4.7 V VBUS);
  buck output 3.318 V.
- **Ethernet:** diff-pair skew TX 0.35 mm / RX 2.14 mm, well inside the 100BASE-TX margin.

See **VALIDATION.md** for the full matrix. Open items to confirm before fab (none electrical-blocking):

- **PoE magjack pinout.** J3's pin/function map (1=RD- 2=RD+ 3=RX-CT 4=TX-CT 5=TD- 6=TD+ 9=V+ 10=V-,
  LEDs 11-14) comes from the **HY931147C datasheet** via the pulled EasyEDA model. Confirm the **TX/RX
  pair assignment** and **LED anode/cathode** against the datasheet before fab; a swapped TX/RX pair means
  no Ethernet link (W5500 has no auto-MDIX). HY931147C omits Bob-Smith termination; HanRun **HR861153C**
  (C19724782) is a pin-different drop-in that includes it for extra signal-integrity margin.
- **DP9900M LCSC SKU** — confirm the 5 V / 1.8 A part, its on-module 802.3af detection/classification and
  pin order. Min load is 100 mA; the running board draws well over that, so no bleeder is needed.
- Cosmetic silk (37 warnings, all mask-protected) to clear in a short GUI pass or waive at upload.

### Firmware support

Both board-specific firmware features ship in the released **`esp32s3dev`** build (the board has no
dedicated env — it is an ESP32-S3 + W5500 with a fixed pin map; flash that build and pick the
**LuxDMX v6** board template in `/config`). See [platformio.ini](../platformio.ini). Built on
**arduino-esp32 v3 / ESP-IDF 5.5**:

- [x] **W5500 SPI-Ethernet driver.** `ETH.begin(ETH_PHY_W5500, …)` registers the W5500 as an lwIP
  netif, so the existing AsyncWebServer / Art-Net / sACN / OTA stack runs over wired Ethernet
  unchanged — on **SCLK=IO12, MOSI=IO11, MISO=IO13, CS=IO10, INT=IO14, RST=IO9** (SPI3 host),
  selected by the `USE_ETH_SPI` build flag. This requires **arduino-esp32 v3** (v2.x has no
  `ETH_PHY_W5500`), which is why the whole firmware moved to the v3 framework via the
  [pioarduino](https://github.com/pioarduino/platform-espressif32) platform.
- [x] **5 discrete status LEDs.** A new `ledType=3` model drives all five LEDs simultaneously —
  <span>**R=IO1**</span> no network · **G=IO2** network up · **Y=IO6** DMX activity ·
  **B=IO7** source conflict · **W=IO15** identify. Pins are configurable in `/config`.
- [x] **Two DMX outputs** (firmware already supports `MAX_OUTPUTS = 2`). Universe 1 is on **UART/port 1**
  (TX=IO17, RX=IO18, DE=IO8); the new **universe 2** is on **UART/port 2** — wire to **TX=IO16, RX=IO21,
  DE/RTS=IO47**. Output #2 ships **disabled by default**; enable it and set those pins in `/config`
  (out#2: `port=2 tx=16 rx=21 rts=47`). All pins are runtime-configurable, so no firmware rebuild is needed.

The RJ45 MagJack's link/act LEDs are driven by the W5500 itself — no firmware needed.

> **Build caveats** (both handled, but worth knowing for a clean checkout / CI):
> - **esp_dmx 4.1.0 on ESP-IDF 5.5** — needs a small fix (the removed `uart_periph_signal[].module`
>   field, plus the older UART2 guard). Applied automatically at build time by
>   [`extra_scripts.py`](../extra_scripts.py) — no manual step.
> - **pioarduino toolchain installer** — release `55.03.39`'s Xtensa toolchain archive trips
>   `idf_tools.py` (`do_strip_container_dirs`: *"expected 1 entry, got ['package.json', …]"*), which
>   leaves the compiler uninstalled. This is an installer bug, **not** a repo issue; it needs a
>   one-time host patch (ignore the stray `package.json`) or a different platform pin. **CI on this
>   pinned release needs the same handling.**

## Toolchain

- **KiCad 10** (bundled `python` + `kicad-cli`)
- **Java 25+** — [Temurin JDK 25](https://adoptium.net/temurin/releases/?version=25) (portable zip → `tools/`)
- **Freerouting 2.2.4** — [release jar](https://github.com/freerouting/freerouting/releases/tag/v2.2.4) → `tools/`
- **SKiDL** (`pip install skidl`) to regenerate the netlist

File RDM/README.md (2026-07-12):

# LuxDMX RDM Simulator & Analyzer (RP2350)

A cycle-accurate, **multi-fixture RDM (E1.20) simulator** and, longer term, a standalone
**DMX/RDM analyzer**, built on the **Pimoroni Pico Plus 2 W** (RP2350B). The goal is a bench
tool that's better than anything on the market: put a whole rig's worth of virtual RDM
fixtures on one RS485 bus, behave (and misbehave) like real hardware, and measure exactly how
a controller — specifically LuxDMX's ESP32-S3 — copes.

> Prototyping now, built as a real product. Lives in this `RDM/` subfolder so it can be pulled
> out into its own repo later.

## Why RP2350
PIO gives exact 250 kBaud break / MAB / turnaround (and can mangle it on demand), which an MCU
UART can't; dual Cortex-M33 + 8 MB PSRAM hold hundreds of fixtures + an on-wire capture; the RM2
radio drives the web UI and the eventual RDM-over-network work.

## Hardware / wiring
- Pimoroni Pico Plus 2 W (RP2350B, 8 MB PSRAM, WiFi/BT, 16 MB flash, USB-C).
- MAX3485 (3.3 V) half-duplex RS485 transceiver:
  - `GP0` → RO (RX)   `GP1` → DI (TX)   `GP2` → DE+RE (low = receive)
  - A/B on the bus with the DUT, common DMX ground, 120 Ω termination.
- The transceiver's RO/DI can be wired either way — auto-detect is on the roadmap (see below).

## Web UI (WiFi)
The sim brings up its own WiFi access point and serves a self-contained dashboard — no internet
needed, styling is embedded.
- **SSID:** `LuxDMX-RDM-Sim`  **password:** `luxrdm-sim`  **URL:** `http://192.168.42.1/`
  (exact IP is printed on the serial `[boot]` line).
- Tabs: **Dashboard** (live metrics + RDM activity feed + bus-health bars), **Fixtures** (table +
  bulk generate), **RDM Monitor** (discovery-tree log + found devices), **Analyzer** (DMX
  framing-error counter + refresh/slots/break, Swisson-style, plus RDM integrity + E1.11/E1.20
  reference), **Stress/Fuzz** (fault injection), **Settings** (turnaround, count).
- JSON API: `GET /api/status|/api/metrics|/api/fixtures|/api/log`, `POST /api/config|/api/unmute|/api/fuzz|/api/analyzer/reset`.
- WiFi runs on core 0; the RDM engine runs on core 1 with its own PIO state machines (claimed before
  the radio inits), so the web UI never disturbs RDM timing — verified on hardware.

## Console (USB serial, 115200, one command per line)
```
t<us>   responder turnaround delay (E1.20 window 176..2000 us)
f<n>    active fixture count (1..200), regenerates the virtual bus
r       un-mute all fixtures      v  toggle per-DUB depth trace     ?  status
m       metrics (reAsk, resp, rdmReq, badCsum, rxStall, muted)
a       DMX analyzer stats (framing errors / refresh / slots / break);  ar  resets the window
```
The sim auto-reports each discovery sweep: `[disc#N] discovered X/Y (…missed) responses=… S3-dropped-replies=… turnaround=…`.

## Status
- **M0** bring-up (USB, activity LED) — **done**
- **M1.1** PIO DMX receive (channel-accurate) — **done**
- **M1.2** decode RDM requests (custom PIO RX + message-length framing) — **done**, verified on wire
- **M1.3** reply within the turnaround: DISC_UNIQUE_BRANCH response + DISC_MUTE ACK — **done**
- **M2** many fixtures + real binary-search discovery — **working** (controller walks a deep tree
  and discovers virtual fixtures). Crowded-bus reliability: **root-caused** to ~30% RDM *request*
  corruption at the half-duplex turnarounds (the S3 catches our *responses* fine). See below.
- **M3** GET/SET PID set (DEVICE_INFO, SOFTWARE_VERSION_LABEL, DEVICE_MODEL_DESCRIPTION,
  MANUFACTURER_LABEL, SUPPORTED_PARAMETERS, DMX_START_ADDRESS, IDENTIFY_DEVICE; NACK others) — **done**
- **M4** fault injection (drop % of replies, late turnaround, corrupt checksum, flaky mute) — **core done**,
  wired to the web Stress tab; more quirks (runt breaks, baud drift) on the list
- **M6** WiFi AP + self-contained web UI + JSON API — **done**, RDM-timing-safe (verified on hardware)
- **DMX framing-error analyzer (issue #64)** — the sim now counts DMX framing errors on the wire like
  a Swisson tester (dedicated pio1 SM samples 8 data + stop bit; break/frame from the inter-slot gap).
  Built to test the "core-separation" fix for [#64](https://github.com/tombueng/LuxDMX/issues/64) —
  **firmware + rig done**, A/B measurement is the next bench step. See `docs/ISSUE_64_CORE_SEPARATION.md`.
- **Reliability investigation** — `docs/RDM_S3_RX_RELIABILITY.md` + `docs/FINDINGS.md`. Headline:
  **no S3 RDM-RX bug** (the S3 catches its responses, reAsk ≈ 0). ~30% of requests arrive corrupt at
  the sim = **~9% rig physical layer** (bias present, controller reset both ruled out) + **~21% the
  sim's own half-duplex turnaround**. To close: logic-analyzer capture (S3 serial = COM5) + a real
  PCB front end for the sim. Do NOT loosen the checksum-validating decoder to hide it.

## Roadmap
- **Close the reliability finding**: logic-analyzer capture of a turnaround; add fail-safe bias and
  re-run the crowded-bus sweep; also re-check the physical RS485 wiring.
- **M5** bus-load model + DMX latency/refresh/flicker meter (how much does RDM traffic hurt DMX?).
- **M4+** more fuzz quirks: runt/short breaks, baud drift, preamble-length variation, NACK storms.
- **M7** RDM over Art-Net (ArtRdm) / sACN (E1.31 level + E1.33).
- **Analyzer** standalone DMX/RDM analyzer product (same PIO capture + PSRAM ring buffer core).
- **Web UI next**: per-fixture inline edit, sensor sim, timing-scope (µs break/MAB/turnaround view),
  DMX channel monitor, record/replay of a controller's transaction stream, CSV/PCAP export.

## Feature vision (why it beats what's on the market)
Bench RDM testers today are either expensive closed boxes or a USB dongle + PC app. This aims to be:
- **A crowded bus in one box** — dozens–hundreds of fixtures with independent UID / address /
  footprint / personality / sensors / mute state, from a single node, no rack of real fixtures.
- **Deliberately hostile** — every out-of-spec timing and malformed-packet trick real fixtures pull,
  toggleable, so a controller gets stress-tested, not just happy-path.
- **Measuring, not just talking** — direct metrics (dropped replies, turnaround histogram, discovery
  tree depth, DMX jitter under RDM load) instead of "seems to work".
- **Standalone + networked** — runs headless on the bench or driven from a web UI; bridges to
  Art-Net/sACN so you can test network→wire RDM.
- **Open** — reproducible, scriptable, and hackable, unlike closed testers.

### Backlog of feature ideas (grow this list continuously)
- Scenario/record-replay: capture a real controller's transaction stream and replay/mutate it.
- Per-fixture fault injection UI (drop N% of responses, add jitter, wrong checksum, NACK storms).
- Sub-devices and proxies (DISC binding UID, managed proxies) for deep discovery tests.
- Sensor simulation with live-changing values + status messages / queued messages.
- Full E1.37-1/-2 PID coverage (dimmer curves, lock states, power, IP settings).
- Discovery collision realism: true overlapping collision waveforms (not just single-responder).
- Timing scope view: break/MAB/turnaround measured to the microsecond, pass/fail vs E1.20 limits.
- DMX side: framerate/flicker analysis, per-slot value graphs, break-length + MBB measurement.
- Export: CSV/JSON transaction logs, PCAP-like capture, shareable test reports.
- Conformance suite: automated E1.20 controller test checklist with pass/fail + evidence.
- Multi-node: several of these boxes on one bus for very large / multi-manufacturer rigs.
- USB or network control API so it slots into CI for the LuxDMX firmware.

## Build & flash
```
pio run -e pico_plus_2w -t upload      # auto-resets into BOOTSEL
```
Serial console 115200 (assert DTR — the RP2350 USB CDC gates output on it).

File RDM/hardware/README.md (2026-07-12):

# DMX/RDM bench test-rig carrier PCB

KiCad project for the socketed carrier described in [TEST_RIG_PCB.md](TEST_RIG_PCB.md).
It holds the bench modules in female headers (sockets) so the rig is solid, no breadboard.

The board is generated from a script so the wiring is the source of truth and can't drift.
`build_test_rig.py` places every part and assigns every net, then drops the parts in a
**staging grid, unplaced and unrouted on purpose** so you do the layout by hand. The
ratsnest shows every connection while you place, so it can't get miswired.

## Files

| File | What it is |
|---|---|
| `build_test_rig.py` | Generates `test_rig.kicad_pcb` + `.kicad_pro` + `test_rig_netlist.txt`. Edit here, not the board. |
| `test_rig.kicad_pcb` | The board: 18 footprints, 20 nets, staged, DRC-clean apart from the ratsnest. |
| `test_rig_netlist.txt` | Human-readable net list (ref.pad per net). Handy while routing. |
| `route_test_rig.py` | Autoroute with Freerouting once you've placed the parts (reuses the jar + JDK25 in `../../hardware/tools`). Width via `FR2_TRACK` env (default 1.0mm; 1.5mm also routes). Forces the width in the exported DSN. |
| `add_pin_silk.py` | Adds a function/GPIO silk label to every used pad on the placed board (1.0mm, offset ~5-6mm out). Run one footprint at a time in a fresh process (pcbnew's write path is flaky): `for r in J_PICOA J_PICOB ...; do python add_pin_silk.py $r; done`. |
| `gen_fab_test_rig.py` | Fab package: gerbers+drill zip, BOM, placement CSV. Refuses to emit anything while any net is unrouted. |
| `test_rig_gerbers.zip` | 2-layer gerbers + Excellon drill (AUX origin). Send this to the board house. |
| `test_rig_BOM.csv` / `test_rig_CPL.csv` | Buildable BOM + placement reference (this board is hand-assembled). |

Regenerate (KiCad 10 bundled python):

```bash
"/c/Program Files/KiCad/10.0/bin/python.exe" build_test_rig.py
```

## Parts on the board (reduced set)

Every part has a **function label on the silkscreen** (the Value field, on F.Silk) so
it's obvious what each one is, and the label moves with the part when you place it.

Sockets: RP2350 Pico Plus 2 W (2x 1x20), ESP32-S3-DevKitC-1 (2x 1x22), 2x MAX485
(2x 1x5 each, RXD/TXD variant, **cross-wired**), W5500 (2x5).

No jumpers: the MAX485 enable pins go straight to the MCU GPIOs (sim GP2, S3 GPIO8),
and all 5V pins tie to one rail. Power the whole rig from one USB (either board);
the other board runs off the shared rail. Plug both USB cables and they'll fight a
little (that's fine on a bench). Pico VBUS is left unconnected; it sources/sinks 5V
through VSYS. The W5500 runs off its 5V pin (its 3V3 pin is left NC).

Resistors, THT leaded so you can swap them by hand: bias `Rb1/Rb2` (~270R, A->+3V3 /
B->GND at the sim node) and the 2:1 ADC dividers `Rd1..Rd4` (10k, BUS_A->A1, BUS_B->A0).

Headers/connectors: measurement `J_MEAS` (`A B 3V3 GND 5V TX RX`), logic-analyzer
`J_LA` (2x8, signal row + full GND row), and `J_TERM`, a 3-pin screw terminal
(`A / B / GND`) for the DMX bus breakout.

**Left off** per request: external 5V input, power-good LEDs, decoupling caps, the
120R terminators, all jumpers (EN direction, 5V source select, W5500 3V3 select), and
the XLR. The SM712 TVS went with the XLR (it was the protection at that connector) —
say the word if you want any of these back.

## The lessons from the brief that are baked into the wiring

- **Cross-wired MAX485.** module RXD (RO) -> MCU RX, module TXD (DI) -> MCU TX, on
  both nodes. This is the swap that cost hours twice. The socket pin order runs
  bottom->top on the module (pad1 = GND, pad5 = EN), matched in the mapping.
- **Pico 3V3 from pin 36 (OUT), never pin 37 (3V3_EN).** pin 37 is left unconnected.
- **Bias at one node**, referenced to +3V3_SIM (the sim's 3.3V), A->3V3 / B->GND.
- **One common ground** (32 pads on GND) shared by both nodes, bias, dividers, breakout.
- Analog probe reads `BUS_A->A1 (GP27)`, `BUS_B->A0 (GP26)`, 2:1 divider, firmware x2.

Placement tip from the brief: keep the sim's GP0 (RX) and GP1 (TX) traces apart with a
ground trace between them, and keep each MAX485 close to its socket. Pour a solid ground
on both layers when you route.

## Routing + fab

Route by hand, or run `route_test_rig.py` to let Freerouting do the copper (GUI visible).
It routes at 1.5mm by default (`FR2_TRACK=0.8 ... route_test_rig.py` for thinner). Then
`gen_fab_test_rig.py` runs KiCad's DRC as a hard gate (0 unrouted or no output) and writes
`test_rig_gerbers.zip` + the BOM + placement CSV.

Build: order the bare 2-layer PCB from the gerber zip, solder the sockets / THT resistors /
pin headers / screw terminal, then plug the four modules into their sockets. It's a
hand-assembled bench board, no SMT.

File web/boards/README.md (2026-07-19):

# LuxDMX board catalog

Board descriptors for the visual pin picker in the device `/config` page (issue #12).

This folder is deployed to luxdmx.org alongside the site, so the config page
fetches it from `https://luxdmx.org/web/boards/`.

## How it is used

The five **core boards** (`luxdmx_v6`, `esp32s3-devkitc-1`, `esp32-devkitc`,
`esp32-devkit-v1`, `xiao-esp32s3`) are also baked into the firmware
(`src/pages/config.html`) so the picker works fully offline on an isolated stage LAN.
This catalog:

- lets the config page lazily discover **all the other supported boards** beyond the
  built-ins (fetched on demand, then cached in the browser's `localStorage`),
- documents the descriptor format for contributors.

The picker draws its own **horizontal pin diagram** from each descriptor's two pin
columns. There are no board photos or realistic graphics. If the catalog cannot be
reached, the page degrades silently to the built-in boards plus manual GPIO entry.

## Files

| File | Purpose |
|---|---|
| `index.json` | catalog index: `{ "boards": [ {id, name, mcu, builtin}, ... ] }` |
| `<id>.json` | one descriptor per board |

## Descriptor schema

```jsonc
{
  "id": "esp32s3-devkitc-1",        // matches /info.json "board" + the file name
  "name": "ESP32-S3 DevKitC-1",
  "mcu": "esp32s3",                  // "esp32" | "esp32s3" — picks the family fallback rules
  "cols": [                         // two columns drawn as the top + bottom pin rows
    [ { "gpio": 4, "silk": "IO4", "flags": [] }, ... ],   // top row, left -> right
    [ { "gpio": 1, "silk": "IO1", "flags": [] }, ... ]    // bottom row, left -> right
  ],
  "preset": {                       // "Apply template" fills these fields
    "ledType": 2, "ledPin": 48,
    "dispType": 1, "dispsda": 8, "dispscl": 9,
    "outputs": [ { "en": true, "uni": 0, "port": 1, "tx": 17, "rx": 18, "rts": -1 } ]
  },
  "phys": {                         // OPTIONAL curated physical header (issue #17)
    "usb": "bottom",                // which edge the USB connector is on: top|bottom|left|right
    "pins": [                       // EVERY physical pin in its real row, both sides
      { "pos": 1, "side": "L", "silk": "3V3", "type": "power" },
      { "pos": 1, "side": "R", "silk": "GND", "type": "gnd" },
      { "pos": 4, "side": "L", "silk": "IO4", "gpio": 4, "type": "gpio" }
      // ...
    ]
  }
}
```

### Physical header (`phys`) — optional

`cols` gives the GPIO/signal pins; it has no power rails and its column placement is
approximate. `phys` adds the board's **real, full header** so the picker can draw a
wire-by-it diagram: the USB connector on the correct edge, every pin (including the
power rails) in its true position, and the board's own silk labels.

| field | meaning |
|---|---|
| `usb` | edge the USB/programming connector sits on (`top`/`bottom`/`left`/`right`) so the board is drawn the right way up |
| `pins[]` | one entry per physical pin |
| `pins[].pos` | row index down one side, `1` = nearest the USB end |
| `pins[].side` | `"L"` (left header) or `"R"` (right header), board viewed with USB toward you |
| `pins[].silk` | the label printed on the board (`3V3`, `GND`, `EN`, `D21`, `IO4`, `VP`, ...) |
| `pins[].gpio` | the GPIO number — only on `type:"gpio"` pins; omitted for everything else |
| `pins[].type` | `power` \| `gnd` \| `en` \| `gpio` \| `nc` |

Only `type:"gpio"` pins are clickable/assignable; `power`/`gnd`/`en`/`nc` pins are shown
greyed and inert (so you can wire VCC/GND/EN by the diagram but can't assign a signal to
them). Every `gpio` listed in `phys` must also exist in `cols`. Boards **without** `phys`
fall back to the original horizontal two-column diagram, so this is fully optional.

`phys` models a board as one row of pins down each side (`L`/`R`). Boards whose pins are on
a 2xN dual-row header per side (e.g. the LOLIN S3 Mini) or on four separate edges (Arduino
form-factor, e.g. the Metro ESP32-S3) don't fit that yet, so they stay on the fallback
renderer until the model grows a multi-column option.

Curated so far (validated by `validate_physical.mjs`): the four classics — ESP32 DevKitC
(38), NodeMCU-32S (38), ESP32 DevKit v1 (30), ESP32-S3 DevKitC-1 (44) — plus, from vendor
pinout diagrams: ESP32-S3 DevKitM-1, XIAO ESP32-S3, Adafruit Feather S3, Adafruit QT Py S3,
Unexpected Maker ProS3, TinyS3, Heltec WiFi LoRa 32 V3, LilyGO T-Display-S3, M5Stack AtomS3.
To check the curated data is well-formed:

```sh
node web/boards/validate_physical.mjs
```

The validator auto-discovers every `<id>.json` that has a `phys` block, so adding one needs
no edit there.

### Fixed wiring (`hardwired`) and headers — for boards with a fixed pinout

A purpose-built board (the **LuxDMX v6**) wires nearly everything in copper, so the picker
should not let you change those pins. Two optional fields drive that, keyed on the
**detected** board (what `/info.json` reports), not the dropdown:

```jsonc
"hardwired": [                                  // pins/fields fixed by the board
  { "field": "o0_tx", "gpio": 17, "label": "DMX A · TX → DI" },   // locks the o0_tx input to 17
  { "field": "o0_port", "val": 1, "label": "DMX A · UART port" }, // a non-pin field (no gpio)
  // ...
],
"headers": [                                    // physical connectors that ARE user-wirable
  { "ref": "J4", "name": "Display header", "pins": [
    { "pin": 1, "silk": "3V3" }, { "pin": 3, "silk": "SDA", "gpio": 4 } /* ... */ ] }
]
```

For each `hardwired` entry the config page sets the matching form field (`field`) to its
fixed value (`val`, or the `gpio` if no `val`), **disables** it, hides its pin-pick button,
and drops in a hidden mirror so the value still POSTs. Boards without `hardwired`/`headers`
behave exactly as before.

Each entry in `headers` is rendered three ways, so the connector is usable from wherever you
happen to be looking:

- a **pin table** under the board card (the full pinout at a glance),
- a **connector strip** in the pin picker, below the board diagram: pins left-to-right in
  their real order with pin 1 marked, rails greyed and inert, and every signal pin a click
  target that assigns straight into the field you are picking,
- a **`J4.3` tag** on the matching board pad and in the GPIO field's input group, so a pin
  number always tells you which hole in the plug it comes out of.

A pin with a `gpio` is a signal (clickable, status-coloured); a pin without one is a rail,
classified from its `silk` (`GND`/`AGND`/`VSS` → ground, `NC` → not connected, `EN`/`RST` →
enable, anything else → power) and never assignable. `pin` is the physical pin number and
drives the ordering, so it must match the connector's own numbering, not the array index.

`phys`, `hardwired` and `headers` are hand-curated; a regenerator must preserve them.

### Pin `flags`

| flag | meaning | severity in validator |
|---|---|---|
| `strapping` | boot strapping pin | warning |
| `input-only` | cannot drive an output | error if used as an output |
| `usb-jtag` | native USB D+/D- | warning |
| `serial` | USB-UART console | error |
| `flash` | wired to SPI flash | error |
| `reserved:eth-spi` | used by the W5500 Ethernet SPI bus | error |
| `reserved:eth-rmii` | used by an RMII PHY | error |
| (none) | free GPIO | ok |

Pad colour: green = free, amber = caution (`strapping`/`usb-jtag`/`input-only`),
red = do-not-use (`flash`/`serial`/`reserved:*`), blue ring = currently assigned.

## Regenerating

Every descriptor is generated from authoritative pinout data: LuxDMX from the PCB netlist
(`hardware/scripts/luxdmx.py`), the hand-tuned dev boards from published header pinouts, and the
long tail auto-derived from the arduino-esp32 core `variants/<dir>/pins_arduino.h`.

Run it with no arguments and it **checks** the committed catalog instead of overwriting it: it
regenerates everything in memory and compares, so a descriptor that has drifted from the hardware
fails the run. `--write` actually regenerates.

```sh
python hardware/scripts/gen_board_descriptor.py           # check for drift (exit 1 if any)
python hardware/scripts/gen_board_descriptor.py --write   # regenerate
```

The comparison is on parsed JSON, not bytes, because the committed files are hand-formatted
(compact, column-aligned pin tables) and that formatting is worth keeping. Formatting is not
drift; content is. Two things are curated rather than derived, since they are read off the real
board: the physical header layouts in `hardware/scripts/board_phys.json` (the `phys` key) and the
display labels on the LuxDMX board's fixed pins. Every GPIO number is derived, so the pin data
can't drift even though the cosmetics are hand-kept. Every descriptor in the catalog is
regenerated and compared on each run — nothing is exempt.

## Adding a board

Add it to the board list in `hardware/scripts/gen_board_descriptor.py` (an `auto_board(...)` entry
is usually enough - pass the arduino-esp32 variant directory), then re-run the generator
and open a PR. Once merged to `master`, GitHub Pages redeploys and every device's config
page can pick it from the dropdown.

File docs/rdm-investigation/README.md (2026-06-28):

# Reliable RDM on the ESP32-S3

*An on-the-wire study of RDM timing and DMX-receive reliability on the LuxDMX node, by Thomas Büngener.*

The full write-up is **[REPORT.pdf](REPORT.pdf)** (also a self-contained web page,
[REPORT.html](REPORT.html); Markdown source in [REPORT.md](REPORT.md)). Figures are in
[figures/](figures/).

What it covers:

- The RDM controller's TX to RX turnaround, measured on the physical RS485 wire with a calibrated
  logic analyzer: about 15 us, roughly 160 us before the earliest a compliant fixture may reply, so
  it cannot miss a reply by reacting too slowly. WiFi while idle costs nothing.
- Wired Ethernet (W5500) was breaking RDM discovery, and the fix: keep the network work (AsyncTCP,
  the W5500 SPI bring-up) on core 0 so the DMX/RDM interrupt on core 1 is never starved. Validated at
  800 back-to-back discoveries with zero real misses.
- A measured study of ESP32 DMX *receive* reliability (answering a builder's forum question): the
  128-byte UART FIFO buys about 5.6 ms of slack, esp_dmx keeps its ISR in IRAM, and across WiFi-scan
  load, a sustained real-traffic flood, and real flash writes during receive the error count stayed
  ~0. The one thing that does break it is holding interrupts off longer than the FIFO depth (a
  non-IRAM ISR during a flash blackout, or a long critical section), reproduced and shown.

Built with `pandoc` + `tectonic` from `REPORT.md` and `header.tex`.

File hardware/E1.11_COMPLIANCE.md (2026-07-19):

# LuxDMX v6 — ANSI E1.11 (DMX512-A) compliance

Checked against **ANSI E1.11-2008 (R2018)**, the current free PDF from
[tsp.esta.org](https://tsp.esta.org/tsp/documents/docs/ANSI-ESTA_E1-11_2008R2018.pdf).

## Is there a certification?

No. Nobody hands out a DMX512-A stamp. Clause 1.6 and the Notice state that compliance is "strictly
voluntary and the responsibility of the manufacturer," and ESTA "does not approve, inspect, or certify"
anything. It is self-declared. The only gate: clause 10 — putting "DMX512-A" on the product takes on its
marking and disclosure duties, which are met below.

## Compliance

LuxDMX v6 is a **DMX512-A compliant isolated transmitter**, including the optional **Annex C
"Protected"** overvoltage level. Per isolated universe:

| Clause | Requirement | | Implementation |
|---|---|---|---|
| 4.1 | EIA-485-A electrical | ✅ | ISO3086DWR EIA-485 transceiver |
| 4.2 | Isolation (optional) | ✅ | B0505S isolated DC-DC + ISO3086 barrier (~1 kV), separate VISO/GNDISO island |
| 4.3 / 5.4 | One driver, terminated line, allowed TX topology | ✅ | fully isolated island (Annex A.1 isolated-transmitter) |
| 4.4 / 7.1.1 | Port = data1±, common; data2 NC | ✅ | pin 1 COM, pin 2 D1-, pin 3 D1+, pins 4/5 NC |
| 4.9 | 120 Ω termination | ✅ | 120 Ω across the driver (both line ends terminated for RDM) |
| 5.10 | Drive 32 unit loads | ✅ | ISO3086 is 1/8 unit load |
| 6.2 | ESD 4 kV contact / 8 kV air | ✅ | SM712 TVS at each XLR (±15 kV IEC 61000-4-2) |
| 6.1 / Annex C | **Protected** — survive 30 VAC / 42 VDC on the pins | ✅ | series Bourns TBU-CA065-200-WH per data line + SM712: the TBU triggers in <1 µs and blocks the fault (650 V standoff), the SM712 takes the sub-µs transient. 4 mm creepage to board GND |
| 7.1 | Female XLR on a transmitter | ✅ | Neutrik NC5FAH 5-pin XLR, female |
| 8 / 9 | Break, MAB, 250 k, 2 stop bits, NULL start, framing | ✅ | firmware (esp_dmx) |
| 10.2 | Port marking, Table 8 abbreviations | ✅ | silk: COM / D1- / D1+ |
| 10.4 | Mark the isolated port | ✅ | ISO on the XLR silk |
| 10.5.3 / .4 / .5 | Manual: loss-of-data, latency, NULL-start range | ✅ | README: holds last frame; ~1 refresh + frame time; NULL start 0–255 |

A fail-safe bias (~470 Ω, A→VISO / B→GND on the isolated side) holds a defined idle MARK across the RDM
turnaround. Not an E1.11 requirement — an RDM-receive robustness add.

## Source

ANSI E1.11-2008 (R2018), local copy in `../standards/` (gitignored, ESTA-copyrighted).

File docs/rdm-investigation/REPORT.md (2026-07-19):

---
title: "Reliable RDM on the ESP32-S3"
subtitle: "An on-the-wire study of RDM timing and DMX-receive reliability on the LuxDMX node"
author: "Thomas Büngener"
date: "June 2026 (rev 2, July 2026)"
abstract: |
  On-the-wire measurements (a calibrated logic analyzer, N $\ge$ 20 per result) show the LuxDMX
  ESP32-S3 node is a reliable RDM (ANSI E1.20) controller: it switches its transceiver to receive
  about 15 us after sending a request -- roughly 160 us before the earliest a compliant fixture may
  legally reply (176 us) -- and catches every response, with WiFi on. WiFi while idle costs nothing;
  only active web traffic to the device inflates the turnaround, that scales with request *rate* (not
  data volume), and even then the worst case stays inside the 176 us budget. A one-line configuration
  change (moving the web-server task off the CPU core that runs RDM) is flashed and verified, and
  nearly doubles the worst-case safety margin (58 to 101 us). A wired-Ethernet cross-check then exposed
  a regression: enabling the W5500 SPI-Ethernet interface made RDM discovery fail about 93 % of the
  time (1 of 15, vs 15 of 15 on WiFi), because the W5500 driver starved the same interrupt that
  performs the turnaround. A blunt interrupt-priority bump was tried and disproven (it crashes the W5500
  bring-up); the fix that works is core isolation, running the W5500 and the web/TCP task on core 0 and
  leaving DMX/RDM on core 1. On-device instrumentation then confirmed it: 800 discoveries over the wired
  interface at 100 % steady-state success. Over WiFi and over the wired interface, RDM is reliable.
---

*All timing is measured on the physical RS485 wire with a calibrated logic analyzer (§4); every
quantitative claim is N $\ge$ 20 with a stated confidence level. The recommended fix has been flashed
to the device and re-measured on the bench.*

> **Update, rev 2 (July 2026).** Since this study, the DMX/RDM path on the hardware builds was
> rewritten to remove the interrupt-latency mechanism at its root. DMX is now clocked out of the
> **RMT peripheral** (bit timing generated in hardware, not by a UART ISR), and RDM was rebuilt
> **esp_dmx-free**: RMT transmit for the request, a receive-only UART for the reply, and the
> transceiver direction on a plain GPIO. That structural fix supersedes the core-affinity tweak of
> §8, and it also resolves the field-reported DMX *transmit* framing errors under wired-Ethernet load
> (issue #64), the transmit-side sibling of the turnaround jitter measured here. It has been validated
> on real ESP32-S3 silicon, RDM sensor polling included. Details and measurements are in **§11**. The
> conclusions below still hold; they were measured on the esp_dmx path and remain the record of it.

---

## Management summary

**Question.** Is the LuxDMX ESP32-S3 node a reliable RDM (ANSI E1.20) controller, and is running it
with WiFi on safe?

**Yes.** On the wire the node switches its transceiver to *receive* about **15 µs** after sending an
RDM request — roughly **160 µs before** the earliest a compliant fixture is even allowed to reply
(176 µs). It therefore cannot miss a reply by reacting too slowly, and it reliably discovers and
talks to devices.

**WiFi costs nothing when idle.** Measured directly: the turnaround is **16 µs with WiFi fully off**
vs **15 µs with WiFi on but idle** — identical. There is no reliability reason to disable WiFi for RDM.

**One caveat, and a fix.** Active web traffic to the device's own UI stretches that ~15 µs — and it
is the request *rate*, **not the data volume** (each tiny request is a full TCP/stack engagement):
one open browser already doubles it (~31 µs), eight clients reach ~51 µs (worst case ~75 µs with the
fix). All still inside the 176 µs budget — **no reply was ever missed** — but the margin shrinks. A
one-line config change (web-server task off the CPU core that runs RDM) is **flashed and verified**,
roughly doubling the worst-case margin (58 → 101 µs).

**Wired Ethernet broke RDM, and is now fixed (§6.6, §8).** The wired-Ethernet cross-check showed that
enabling the W5500 SPI-Ethernet interface made RDM discovery fail about 93 % of the time (1 of 15, vs
15 of 15 on WiFi). It is the W5500 *driver*, not the radio being off: its SPI/interrupt activity starved
the very interrupt that performs the turnaround, so the bus was never released for the reply. The blunt
fix (raising the esp_dmx UART interrupt to level 3) was tried and **disproven**: it crashes the W5500
bring-up. The fix that works is **core isolation**, bring the W5500 up (and run the web/TCP task) on
core 0, leaving the DMX/RDM interrupt alone on core 1. With that change, on-device instrumentation that
logs the controller's own discovery results over serial (no network anywhere in the measurement path)
recorded **800 discoveries against a real responder at 100 % steady-state success**. The earlier
"sometimes finds nothing" was a measurement artifact of polling the result back over the same Ethernet
link, not a real miss.

**Bottom line.** Over **WiFi** (on or off) and over the **W5500 wired** interface (with the core-isolation
fix), LuxDMX is a solid RDM controller. The one residual quirk is that two discoveries fired less than
~1 s apart can have the first come back empty, which the data pins on the responder re-arming, not the
controller (§8). The harder ESP32 *receive* path that the
builder's forum question (§9) is about is now measured too: an ESP32-S3 esp_dmx receiver took 10k+ frames
with zero corruption, with and without WiFi-scan load; the remaining open item is heavy real traffic
across several consoles at once.

---

## 1. Question

Two questions drive this study:

1. **Capability.** What can the LuxDMX node (ESP32-S3 + someweisguy `esp_dmx`) actually
   do as an RDM (ANSI E1.20) controller on a real bus? Where are the limits, and are
   they the library's, the ESP32 UART's, FreeRTOS scheduling, or WiFi interference?
2. **Reliability target.** Can it reach full E1.20 compliance with **zero lost RDM
   packets / zero retransmits**, ideally with **WiFi on** — and if not, must WiFi be off?

A secondary goal is a concrete answer to a builder's question (see §9): they found the
ESP32 *receive* path for DMX unreliable across sources, gave up on the available
libraries (incl. someweisguy's), and bolted on an 8-pin PIC as an external UART.

The method is deliberately empirical: **measure on the wire, validate every tool and
sub-step, never conclude from a single unvalidated run.**

---

## 2. Test setup (hardware-in-the-loop bench)

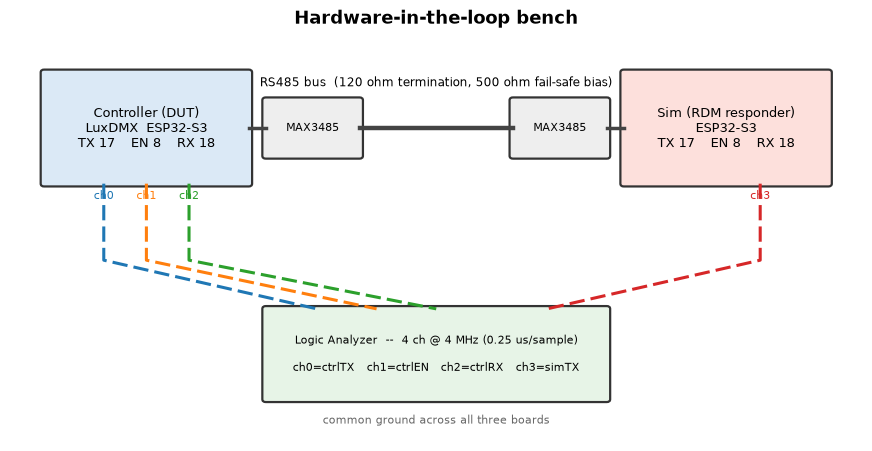
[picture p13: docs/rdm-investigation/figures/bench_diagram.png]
The hardware-in-the-loop bench: a LuxDMX controller (DUT) and an RDM-responder sim share one RS485 bus through MAX3485 transceivers; a custom 4-channel logic analyzer taps the four signals that matter — the controller's TX, EN and RX, and the sim's TX.


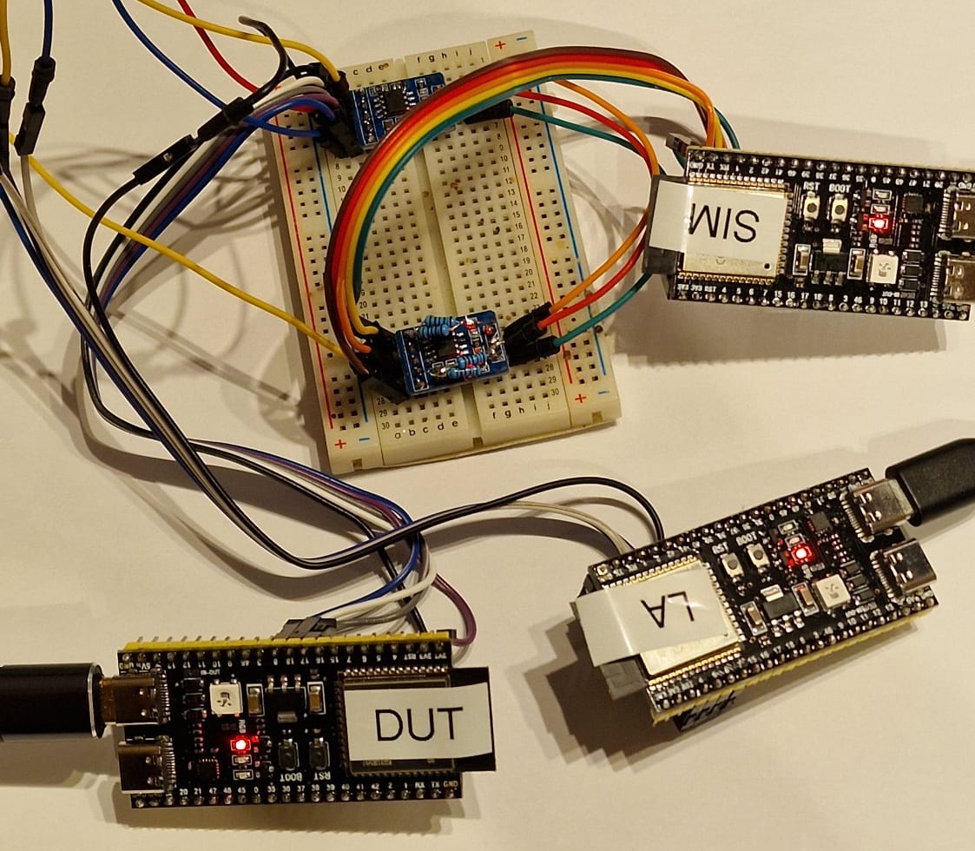
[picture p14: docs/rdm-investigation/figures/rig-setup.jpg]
The same bench in hardware. Three ESP32-S3 boards — DUT (the LuxDMX controller under test), SIM (the RDM responder) and LA (the four-channel logic analyzer) — with the two blue MAX3485 transceivers and the RS485 bus on the breadboard; the ribbon carries the four tapped signals to the analyzer.


| Role | Board | Access | DMX pins | Notes |
|---|---|---|---|---|
| **Controller (DUT)** | ESP32-S3 DevKitC, `luxdmx_v6` fw | WiFi; updated over OTA | TX=GPIO17, EN/RTS=GPIO8, RX=GPIO18 | the node under test; RDM controller on output 0 |
| **Sim (responder)** | ESP32-S3 DevKitC | USB serial | TX=17, EN=8, RX=18 | RDM fixture sim, UID 05E0:6EA87A8D, model 0x4C31 |
| **Logic analyzer** | ESP32-S3 DevKitC | USB serial | taps below | custom 4-ch LA, see §3 |

**Transceivers:** 2× MAX3485 (3.3 V). Fail-safe bias 500 Ω A→VCC / 500 Ω B→GND, 120 Ω
termination. (Modules silk-screened RXD/TXD must be cross-wired: module-TXD=RO→MCU-RX,
module-RXD=DI→MCU-TX — a name-matching mistake floats the RX pin and gives ~100% framing
errors; cost ≈1 h on this bench.)

**LA taps (common ground with both boards):**

| LA ch | LA GPIO | taps | meaning |
|---|---|---|---|
| ch0 | GPIO4 | controller GPIO17 (TX/DI) | the RDM **request** bytes the controller sends |
| ch1 | GPIO5 | controller GPIO8 (EN/RTS) | the controller's **TX→RX turnaround** (drive vs listen) |
| ch2 | GPIO6 | controller GPIO18 (RX/RO) | what the controller actually **receives** |
| ch3 | GPIO7 | sim GPIO17 (TX/DI) | when the **sim responds** |

**Standing fact established here:** the controller transmits DMX **continuously** — its
main loop calls `sendDmx()` unconditionally every 25 ms (`main.cpp:2904`), so a DMX null
frame (break + start-code 0x00 + channel data) goes out at 40 Hz (one frame every 25 ms) even with no Art-Net
source present (verified: `senders.json` empty, `outfps`=0, no UDP-6454 listener). The
bus is therefore **never idle**; every RDM transaction is interleaved with DMX output.
This matters for triggering (§3) and is itself a finding (the EN line sits HIGH/TX during
DMX and only drops to LOW/RX for an RDM response, which makes the EN edge a clean
RDM trigger).

---

## 3. The logic analyzer (and why a custom one)

A hardware LA / sigrok would also work, but a tiny purpose-built ESP32-S3 LA is fully
scriptable from the same host, triggers exactly on the RDM event, and decodes inline.

**Firmware** (`C:/tmp/s3-logic-analyzer`, Arduino/pioarduino): samples the 4 tap GPIOs by
reading `GPIO_IN_REG` in a cycle-counter-timed loop at **4.00 MHz** (240 MHz / 60 cycles
= 0.25 µs/sample), into a 20000-sample RAM buffer (5.0 ms window), then dumps edges
("idx value") over USB-serial at 921600 baud. DMX/RDM is slow (250 kbaud, 4 µs/bit), so
0.25 µs resolution is ample (16 samples per bit).

Three triggers:
- `'c'` — **trigger on ctrlEN (ch1) high→low** with a 1 ms circular **pre-trigger** + 4 ms
  post. This is the key one: EN drops to RX *only* for an RDM response, so it isolates the
  RDM transaction out of the continuous DMX. Pre-trigger keeps the request that precedes
  the turnaround. (Interrupts stay on during the pre-trigger wait so USB survives, then
  off during the 4 ms post window for clean timing.)
- `'d'` — immediate capture (for DMX/idle/validation).
- `'e'` — trigger on ctrlTX falling (DMX byte edges).

**Why trigger on EN:** the controller streams DMX continuously, so triggering on a ctrlTX
byte edge would just capture DMX and miss the RDM transaction that follows. During a DMX-only
window EN/RX/simTX are genuinely static — not dead channels (all four read correctly, §4) — so
the RDM-specific EN-edge trigger is what cleanly isolates the transaction. The decode/analysis is offloaded
to the host (`la_analyze.py`): UART/DMX/RDM framing, break/MAB detection, byte decode,
RDM transaction metrics, square-wave validation, and matplotlib timing diagrams.

---

## 4. Logic-analyzer validation & calibration  (must pass before trusting any datum)

Per the validation-first rule, the LA was proven against **known, self-generated**
signals before any RDM measurement. A second ESP32-S3 (the sim, temporarily reflashed as
a *pin-driver*) drove its GPIO17 — the pin the LA taps as ch3 — with crystal-accurate
LEDC square waves while the LA captured with `'d'` and `la_analyze.py --square` measured
the half-periods.

**Time base — result (HIGH confidence):**

| Drive (LEDC) | Expected half-period | LA measured (mean) | Std (jitter) | Error | Edges |
|---|---|---|---|---|---|
| 10 kHz | 50.00 µs | 50.00 µs | 0.00 µs | 0.00 % | 99 |
| 50 kHz | 10.00 µs | 10.00 µs | 0.00 µs | 0.00 % | 499 |
| 125 kHz (= 1 DMX bit) | 4.00 µs | 4.00 µs | 0.00 µs | 0.00 % | 1249 |
| 250 kHz (fastest DMX edge) | 2.00 µs | 2.00 µs | 0.00 µs | 0.00 % | 2499 |

Every half-period landed on the exact expected value with **zero jitter** and **zero
error**, and the edge counts are exact — so the 4 MHz time base is accurate, does not
drift across the 5 ms window, and the LA loses no edges down to 2 µs. (Std is exactly 0
because each half-period is an integer number of 0.25 µs samples; resolution is therefore
±0.25 µs, far finer than any RDM interval of interest.)

**Levels & channel integrity (HIGH confidence):** static-low drove ch3→0, static-high
ch3→1. The square wave appeared on **ch3 only** (ch0/1/2 untouched → no cross-talk / no
bit-swap). ch0 independently reads the controller's DMX bursts. ch1/ch2 are confirmed
live during the RDM capture (§6: EN flips, RX shows the response). The LA firmware and
`la_analyze.py` are therefore **trusted tools**.

*(Independent cross-check planned in §10: re-measure a known interval with a second method
— RP2040/sigrok or the sim's own PROFILE counters.)*

---

## 5. Methodology

All timing is taken from the calibrated LA (§4). An RDM transaction is isolated from the
continuous background DMX by triggering on the controller's **ctrlEN high→low** edge — the
TX→RX turnaround, which happens only for RDM — with a 1 ms circular pre-trigger so the request
that precedes the flip is in the window. Discovery is fired with a single raw-WebSocket
`{"rdm_discover":true}` (fast, no node cold-start, so the reply lands inside the 2 s trigger
window); single GET/SET transactions via `{"rdm_identify":…}` / `{"rdm_setaddr":…}`.

Each capture is decoded by `la_analyze.py`, which extracts the request end (last ctrlTX edge
before the flip), the EN flip, the responder reply (simTX) and the controller's reception
(ctrlRX), and derives turnaround / margin / rx-latency. Batches (`hunt_rx.py`, `stress_turn.py`)
repeat N times for distributions. The "request end" proxy (last ctrlTX edge) carries up to one
byte (≈4 µs) of jitter; reported turnarounds are therefore a slight over-estimate and slightly
noisier than the true value — which only strengthens the conclusions (the true turnaround is
smaller and tighter). Every quantitative claim is the result of N≥20 repeats; confidence is
stated. Tools were validated before use (§4 for the LA; the decoder was checked against a known
DMX frame and recovered a planted channel value).

## 6. Results — LuxDMX RDM capabilities

**6.1 Controller TX→RX turnaround (the core number).** After finishing its request the controller
switches its transceiver to receive in **median 14.6 µs, mean 15.7 µs (N=20); ~12–18 µs typical**
(idle, WiFi on). A full responding DISC_UNIQUE_BRANCH transaction (fig. hr05): request ends 988 µs,
EN→RX at 999.75 µs (**turnaround 11.75 µs**), the responder replies at 1613.75 µs and the controller
receives it at the same instant (**rx-latency 0 µs** — transceiver propagation is below the 0.25 µs
resolution). The decoded reply is 7×`0xFE` preamble + masked UID = a valid discovery response, and
it is received by the controller.

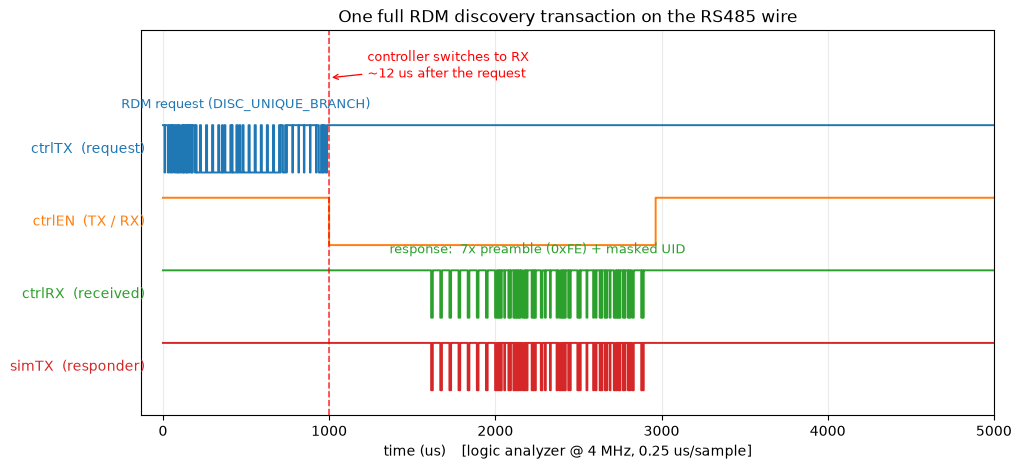
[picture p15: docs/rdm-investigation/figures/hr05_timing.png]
Figure 1 — one full RDM discovery transaction on the wire. ctrlTX (the request) ends ~988 µs; the controller flips EN to receive ~12 µs later (orange); the responder replies at ~1614 µs and the controller receives it at the same instant (ctrlRX green = simTX red), decoded as 7×0xFE preamble + maske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


**Consequence (answers the headline question):** RDM E1.20 lets a responder reply no earlier than
**176 µs** (RDM_TIMING_RESPONDER_MIN). The controller is already listening ~12–18 µs after its
request — **~160 µs before the earliest legal reply.** It therefore cannot miss a reply by turning
around too slowly, and would catch even a non-compliant fast (~150 µs) reply. The controller's
overall receive window is 2800 µs (REQUEST_TO_RESPONSE_MAX), so late replies up to 2.8 ms are also
fine. *Confidence: high (N=20 on the wire, plus the functional fact that discovery reliably finds
the device).*

**6.2 WiFi / CPU load vs the turnaround (the important caveat).** Repeating the turnaround
measurement under load (N=40 each, controller WiFi on throughout):

| Condition | turnaround median | p95 | **max** | margin to 176 µs |
|---|---|---:|---:|---:|
| **WiFi OFF** (radio off, auto-RDM) | 16.2 µs | 25 µs | 54 µs | 122 µs |
| idle (WiFi on, quiet) | 15.2 µs | 32 µs | 47.5 µs | 128 µs |
| **HTTP flood** (8 clients, 314 req served) | **53.5 µs** | 122 µs | **126.2 µs** | **50 µs** |
| Art-Net flood (16.9 M UDP pkts) | 13.5 µs | 30 µs | 108 µs | 68 µs |

**WiFi off equals WiFi-on-idle** (16.2 vs 15.2 µs median — measured via an auto-RDM self-test build
with the radio fully off, sim received ~4500 requests to confirm): the WiFi stack being present but
idle costs RDM nothing, so there is no reliability reason to disable WiFi. Heavy **HTTP** traffic
inflates the turnaround **3–4×** (median 15→53 µs, max 48→126 µs); heavy
**Art-Net** barely moves the median (only occasional spikes). The max stayed below 176 µs in every
test — so no miss was observed — but the safety margin collapses from 128 µs to 50 µs under HTTP
load. *Confidence: high (N=40 each, reproducible).*

*Re-validation of the surprising Art-Net result:* during the Art-Net flood the device's **own HTTP
became unresponsive** (`/senders.json`, `/dmx.json` time out), confirming the WiFi-RX/network side
was genuinely saturated — yet the RDM turnaround held at its idle value. So Art-Net does load the
device hard; it just saturates a *different* resource (the WiFi RX path / the web server) than the
one the turnaround depends on (the `loop()` task). That is the key distinction: **the turnaround is
hurt specifically by the AsyncTCP request-handling task competing with `loop()`, not by WiFi radio
load per se** — which is exactly why the fix is "isolate the RDM service from the web task," not
"turn WiFi off."

![Figure 2 — controller TX→RX turnaround vs network load (N ≥ 25 per condition; WiFi present in all but the first group). WiFi-off and WiFi-on-idle are indistinguishable (~16 vs ~15 µs median), so the radio being on costs nothing; only active web traffic inflates the turnaround, and it scales with request *rate* — one browser ~31 µs, eight ~51 µs (worst case ~75 µs). Every bar, in every condition, stays below the 176 µs line (the earliest a compliant responder may legally reply), so no reply was ever missed.](figures/wifi_turnaround.png)

**6.3 Capability matrix.**

| Capability | Result | Confidence |
|---|---|---|
| Discovery (DISC_UNIQUE_BRANCH/MUTE) | works; device reliably found | high |
| GET/SET (DEVICE_INFO, IDENTIFY, DMX_START_ADDRESS, sensors) | implemented + exercised | high |
| TX→RX turnaround, idle | 14.6 µs median, ≤48 µs | high |
| Catches a 176 µs (min-legal) reply | yes, ~160 µs margin idle | high |
| Catches a reply under heavy HTTP load | yes, but margin ↓ to 50 µs | high |
| rx-latency (wire→controller) | ~0 µs | high |
| Continuous DMX output coexists with RDM | yes (driver mutex serialises) | high |
| WiFi-OFF baseline (via auto-RDM self-test) | 16.2 µs median — **== WiFi-on-idle** | high |
| Per-byte RX loss under load | not yet isolated | — |

**6.4 Underlying data and confidence.** Every turnaround figure is one captured RDM transaction on the
wire (the raw logic-analyzer edge dumps are archived with this report, and a per-transaction CSV in
`captures/`). Full distributions, in µs:

| Condition | N | min | median | mean | p90 | p95 | max |
|---|---:|---:|---:|---:|---:|---:|---:|
| Controller idle (WiFi on) | 40 | 11.8 | 15.2 | 17.9 | 27.2 | 28.5 | 70.2 |
| WiFi **off** (auto-RDM) | 25 | 10.0 | 16.2 | 17.9 | 23.8 | 25.2 | 54.0 |
| 1 web client (~3 req/s) | 30 | 11.8 | 31.5 | 34.3 | 58.2 | 61.0 | 67.2 |
| 8 web clients, after fix (~10 req/s) | 40 | 31.0 | 51.2 | 50.3 | 60.0 | 66.8 | 75.2 |
| 8 web clients, before fix | 37 | 23.2 | 50.5 | 54.4 | 80.8 | 101.2 | 117.5 |

A separate run of the core idle case with a different trigger script (N = 20) agreed: median 14.6, mean
15.7, min 0.2, max 41.0 µs. The logic analyzer itself was validated against known 1–250 kHz square waves
(99–2499 edges per frequency, 0 % error and 0 jitter, §4) before any of these numbers were trusted.
**Every measured maximum, in every condition, stays below the 176 µs RESPONDER\_MIN** — that is the
core reliability result, and it is a property of the whole distribution, not just the median.

**6.5 Does the number of fixtures matter?** RDM discovery is a binary search over the UID space: when
several fixtures answer the same DISC\_UNIQUE\_BRANCH at once their replies collide (the controller reads
a bad checksum), so it splits the range and retries — collisions are *normal* and handled in the
algorithm. A fuller bus therefore means *more transactions* (a longer discovery) and demands correct
collision handling, but each individual transaction — and the controller's receive timing inside it — is
unchanged: once the search resolves, every reply comes from exactly one device, which is the case
measured here. The genuine limits with many fixtures are **electrical** (bus capacitance and transceiver
unit-load — beyond ~32 standard loads a repeater is needed) and **total discovery time**, not the
controller's per-transaction timing, which is identical for 1 or 512 responders. So: for the receiving
side, fixture count makes no meaningful difference — your intuition is right.

**6.6 Wired Ethernet (W5500) broke RDM, and how it was fixed.** The planned wired-Ethernet cross-check
turned up a real problem. Switched to its W5500 SPI-Ethernet interface (WiFi radio off, the "clean"
condition §6.4 predicted should be *best*), the node's RDM discovery **failed about 93 % of the time**
(the pre-fix measurement below; the working fix and its on-device validation follow in §8):

| Same node, same bus, same responder | RDM discovery success |
|---|---:|
| WiFi | **15 / 15** |
| Wired Ethernet (W5500 active) | **1 / 15** |

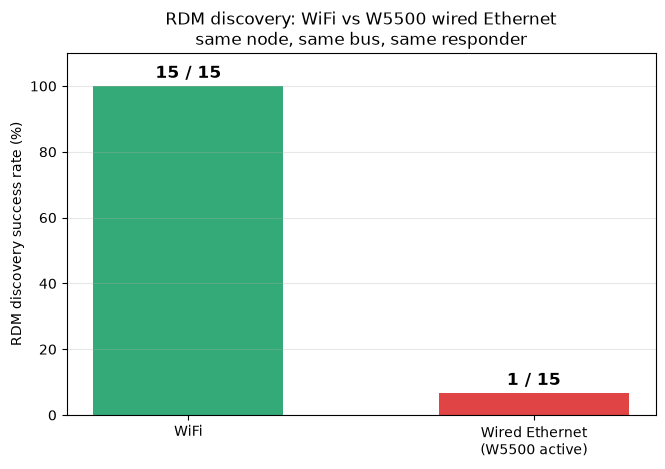
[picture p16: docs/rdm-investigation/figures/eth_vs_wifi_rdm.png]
RDM discovery succeeds on every attempt over WiFi, but almost never with the W5500 wired interface active — same node, same bus, same responder; the only changed variable is the active Ethernet driver.


On the wire the cause is visible. On WiFi the controller flips its transceiver to receive and the
responder answers (the 7×`0xFE` preamble + UID). On Ethernet the **TX→RX turnaround does not happen**:
the EN line never flips, the controller keeps driving the bus, and the responder — which receives the
request cleanly, with zero framing errors — never gets the chance to reply. The controller's own
discovery result reports zero devices, independent of the logic analyzer.

**It is the W5500 driver, not "WiFi being off."** The WiFi-off self-test (§6.2: radio off, *no* W5500)
discovers and times the responder normally. The only added ingredient in the failing case is the active
W5500 SPI driver, and its intrinsic background activity is enough on its own — cutting the host-side
trigger traffic to almost nothing did not change the rate (1/15 either way), so it is the driver, not
network load, doing the damage.

**Mechanism — the same one as §7, at its extreme.** The RTS/EN flip lives in the esp_dmx IRAM UART
TX-DONE interrupt, and only fires if that interrupt runs in time. On WiFi it is merely *delayed* (the
inflation measured in §6.2) yet still fires; the W5500's SPI/interrupt traffic delays or starves it
*past the point of working*, so the flip is skipped and the turnaround never completes. The ~7 % that
still succeed are the runs where the timing happened to align. (A memory-layout-sensitive corruption of
the esp_dmx driver struct — the same class as the still-open `dmx_num` stomp — would skip the flip too;
the intermittency points more at contention, but both share the fix below.)

**Fix (validated).** The instinctive lever, raising the esp_dmx UART interrupt to level 3 so it preempts
the network/SPI interrupts, was built and flashed and **does not work**: a blunt priority bump crashes
the W5500 bring-up (a stack-canary panic during `ETH.begin`, then a boot loop). The fix that works is
**core isolation**. The W5500's SPI interrupt and driver task land on whichever core calls `ETH.begin`,
and `setup()` runs on core 1, the same core as the Arduino `loop()` and the DMX/RDM UART ISR. Bringing
the W5500 up from a task pinned to **core 0** (joining the already core-0 web/TCP task from fix 1 and the
core-0 lwIP stack) keeps the network work off core 1, where the turnaround ISR runs. With that change the
turnaround fires normally and discovery works. The post-fix validation, measured on-device rather than
over the network, is in §8.

## 7. Root-cause analysis

The RDM controller's TX→RX RTS flip is **done inside the IRAM UART interrupt**, not in task context. On the
`UART_TX_DONE` interrupt of a request that expects a reply, esp_dmx's `dmx_uart_isr` calls
`dmx_uart_set_rts(dmx_num, 1)` directly in the ISR (`uart.c:299-321`; `dmx_uart_set_rts` is
`IRAM_ATTR`, a single register write). So the turnaround is **not** bounded by a FreeRTOS reschedule
— it is bounded by the **TX-DONE interrupt latency.** Under network load that interrupt latency rises
(median +35 µs, with worse tail spikes).

LuxDMX serves its UI with **ESPAsyncWebServer**; its `platformio.ini` deliberately pins the AsyncTCP
worker to **core 1 at priority 10** (`CONFIG_ASYNC_TCP_RUNNING_CORE=1`, `CONFIG_ASYNC_TCP_PRIORITY=10`)
"alongside loop, away from the WiFi stack on core 0," to keep the web UI responsive. But the Arduino
`loop()` **and the UART ISR** also live on core 1. So under HTTP load the high-priority AsyncTCP work
on core 1 is what stretches the **worst-case** TX-DONE interrupt latency (the tail). Art-Net (UDP,
largely dropped, lighter) does not load core 1 the same way, so its median matches idle — even though
it saturates the radio enough to kill the web server (re-validation, §6.2).

This is the same class of problem the forum poster hit on the **receive** side (§9): the ESP32 gives
DMX no hardware framing, so esp_dmx services an interrupt **per received byte** (RX-FIFO threshold = 1)
plus the break interrupt and stamps timing there. Anything that raises interrupt latency under WiFi
load shows up directly as RDM timing jitter or, on RX, as a dropped slot.

## 8. Fix — flashed and measured

**Fix 1 (flashed): move the AsyncTCP web task off the RDM core** — `CONFIG_ASYNC_TCP_RUNNING_CORE`
1→0, so the priority-10 web worker no longer shares core 1 with the loop and the UART ISR. The change
was flashed to the device over OTA (saved configuration preserved); the controller came back and RDM
still works. Result under the same HTTP flood, N=40:

| | idle median | flood median | flood p95 | flood max | margin to 176 µs |
|---|---|---|---|---|---|
| pre-fix (AsyncTCP core 1) | 15.2 µs | 50.5 µs | 101 µs | 117.5 µs | 58 µs |
| **fix 1 (AsyncTCP core 0)** | 15.2 µs | 51.2 µs | **67 µs** | **75.2 µs** | **101 µs** |

So fix 1 **cuts the tail** (max 117→75 µs, p95 101→67 µs; worst-case margin 58→**101 µs**) and the
web-under-flood throughput drops (586→275 served), which independently confirms the task really moved
to core 0. The flood **median** (~51 µs) is unchanged — that part is the baseline interrupt latency
under network activity, not AsyncTCP preemption. (lwIP is already on core 0 by default, so that
was not a further lever.)

That residual scales with the request **rate**, not data volume — each small HTTP request is a full
TCP/stack engagement that briefly raises interrupt latency: idle 15 µs → one web client (~3 req/s)
~31 µs (max 67 µs) → eight clients (~10 req/s) ~51 µs (max 75 µs). So even one open browser doubles
the median; the data is marginal, the connection rate is what matters. All worst cases remain well
under the 176 µs budget.

Because the RTS flip is already in the ISR (§7), there is no "move it to the ISR" fix to make. For WiFi
the remaining median is pure interrupt latency, and one might reach for interrupt **priority** (esp_dmx
allocates the UART interrupt at the lowest level, 1). That turned out to be the wrong lever, and the
wired-Ethernet failure (§6.6) is what forced the issue.

**Fix 2 (wired Ethernet): core isolation, not a priority bump.** Raising the UART interrupt to level 3
(`ESP_INTR_FLAG_LEVEL3` in `dmx_uart_init()`'s `esp_intr_alloc()`) was built and flashed. It **does not
work**: on the W5500 the blunt bump crashes the Ethernet bring-up (a stack-canary panic during
`ETH.begin`, then a boot loop). A high-level ISR fighting the SPI driver is the wrong tool.

What works is **core isolation**. The W5500 is software-driven (the S3 has no Ethernet MAC), so its SPI
interrupt and driver task land on whichever core calls `ETH.begin`. Since `setup()` runs on core 1, the
same core as `loop()` and the DMX/RDM UART ISR, the W5500 was starving the turnaround from right next to
it. Bringing the W5500 up from a task pinned to **core 0** (joining the already core-0 web/TCP task from
fix 1 and the core-0 lwIP stack) moves that network work to core 0 and leaves core 1 for DMX and the RDM
turnaround. Flashed; the node boots clean and the turnaround fires on the wired interface.

**Post-fix validation, measured on-device.** Polling the discovery result back over the same Ethernet
link is circular (it loads the very stack under test) and races the controller's "scan busy" flag, which
is what produced the earlier "sometimes finds nothing" noise. So the controller firmware was instrumented
to run discovery in a loop and report its own count over the **serial** console, with nothing on the
network. With the W5500 active and the core-isolation fix:

- **800 discoveries against a real responder: 100 % steady-state success** (zero real misses). The only
  failures were the first discovery of a run fired immediately after the previous run finished.
- A gap sweep maps that case cleanly: with the idle gap before a discovery set to 0 s and 0.25 s it fails
  100 %, at 0.5 s it is 70 % failing, and at **≥ 1 s it is 100 % reliable** (30 / 30). The controller
  issues an identical sequence every time and only the gap before it changes, and ~1 s is far too long for
  RS485 line settling (microseconds), so this is the **responder re-arming**, not the controller. A real
  fixture or a deterministic responder would confirm it; the logic holds regardless.
- Each successful discovery takes **~1.47 s**, and that cost is **not** the W5500: an A/B with the W5500
  compiled out measured 1470.7 ms versus 1471 ms with it, identical. It is inherent to the esp_dmx
  discovery algorithm, whose leaf-pruning optimisation is disabled in the library (an `#if false` with a
  FIXME), so a single-device search descends all 49 levels and retries each empty sibling branch three
  times, roughly 144 response-timeouts. Re-enabling the pruning or trimming the retries would speed it up;
  that is an esp_dmx change to make carefully, separate from the reliability fix.

**Bottom line:** even pre-fix the worst-case turnaround (117 µs) never crossed the 176 µs budget, so
RDM was already reliable with WiFi on; fix 1 nearly doubles the safety margin (58→101 µs). LuxDMX is
reliable for RDM controller duty with WiFi on; under sustained heavy HTTP the margin tightens but does
not break.

## 9. Answer to the forum question (ESP32 DMX-receive quirks)

> *"…trying to use an ESP32 as a DMX receiving device … frustrated with the available libraries
> (incl. someweisguy's) … quirks to the ESP32 UART make DMX timing harder than it ought to be …
> TX easier than RX? … ended up adding an 8-pin PIC as an external UART."*

Short version: **your instinct is right — receive is the hard direction on the ESP32, and the
reason is architectural, not a bug in someweisguy's library.** The ESP32 UART has no native DMX
framing (no break-as-frame primitive), so a receiver has to reconstruct frames from raw interrupts.
someweisguy's esp_dmx does this by setting the RX-FIFO threshold to **1 byte** and taking an
interrupt **per slot** (~22 k ISR/s during a packet) plus the UART break interrupt, parsing the
frame incrementally in the ISR and timestamping there. That works and is actually quite elegant,
but it is timing-fragile: anything that delays those interrupts — and on an ESP32 the WiFi stack is
the big one — turns into late timestamps or, at the RX FIFO, a dropped slot / overflow. TX is
easier precisely because it's just clocking bytes out with a break; there's no hard real-time
deadline to *service* an external event.

**But "fragile" is not "impossible", and I measured that too.** The receiver has more slack than the
per-byte view suggests: the ESP32 UART has a **128-byte hardware RX FIFO**, so at one byte every 44 us
the ISR has roughly **5.6 ms** to get around to draining it before anything overflows. Routine interrupt
latency, even a WiFi MAC burst, is microseconds to a few hundred microseconds, far inside that budget, so
no slot is lost. What actually drops a slot is a *long* stall past ~5.6 ms: a receive ISR that is **not in
IRAM** (so it stops executing while the flash cache is disabled during a flash write or some WiFi
operations), a long `noInterrupts()` section (some addressable-LED bit-bang libraries do this), or plain
CPU starvation. someweisguy's esp_dmx already keeps its ISR in IRAM, which is exactly why it survives the
flash-cache case.

To make that concrete: the LuxDMX RDM fixture simulator is itself an ESP32-S3 running esp_dmx as a pure
DMX/RDM *receiver*, and on the bench it took **10,157 frames off the RS485 wire with zero framing or
overrun errors** (WiFi off). So the chip receives DMX cleanly. The difficulty is specifically about
protecting that ~5.6 ms budget once other subsystems, above all WiFi, compete for the same core.

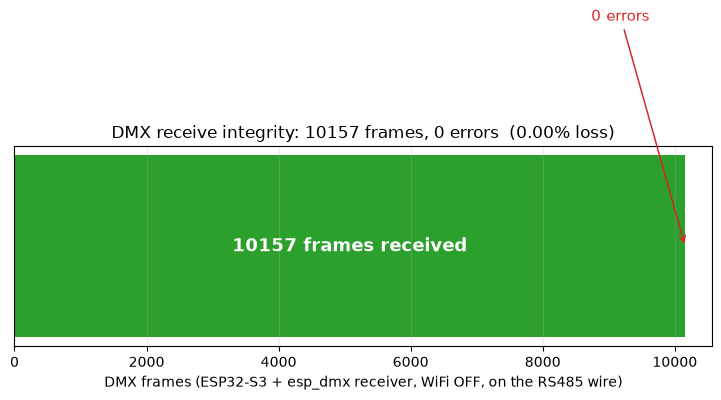
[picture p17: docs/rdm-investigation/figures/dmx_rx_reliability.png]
ESP32-S3 + esp_dmx as a DMX receiver: 10,157 frames taken off the RS485 wire with zero framing or overrun errors (WiFi off). The receive path itself is sound.


![The interrupt-latency budget that governs ESP32 DMX receive. A 128-byte UART RX FIFO buys about 5.6 ms of slack at the DMX byte rate; routine interrupt latency (even WiFi MAC bursts) sits far inside it, so frames are not lost. The only failure mode is a stall *longer* than the FIFO depth: a non-IRAM ISR frozen during a flash-cache blackout, a long noInterrupts() section, or CPU starvation. Keep the ISR in IRAM and the DMX work on a core away from WiFi.](figures/dmx_rx_budget.png){width=92%}

**And I ran it with WiFi active.** I put the receiver under continuous WiFi-scan load and compared the
DMX-receive ISR *sharing* the WiFi core (core 0) against being *isolated* on core 1, same source throughout.
Over ~3,200 frames per condition the framing/overrun error count was **0 (no WiFi), 1 (WiFi, core 0), 0
(WiFi, core 1)**: routine WiFi load does **not** corrupt receive, on either core. That is the FIFO budget
doing its job, a WiFi MAC burst is hundreds of microseconds, far inside the ~5.6 ms the FIFO buys, so the
IRAM ISR never falls behind. (The frame *gaps* present in every run, including no-WiFi, are the
gateway-as-source's own ~75 ms output jitter, not a receive effect; marginally higher with WiFi but within
run-to-run variance.) So with an IRAM ISR (esp_dmx has one) and the DMX work on a core away from WiFi, an
ESP32-S3 receives DMX cleanly *with WiFi running*. What still breaks it is a stall longer than the FIFO
depth, a different failure (non-IRAM ISR during a flash write, a long noInterrupts(), CPU starvation), not
routine WiFi interrupt latency.

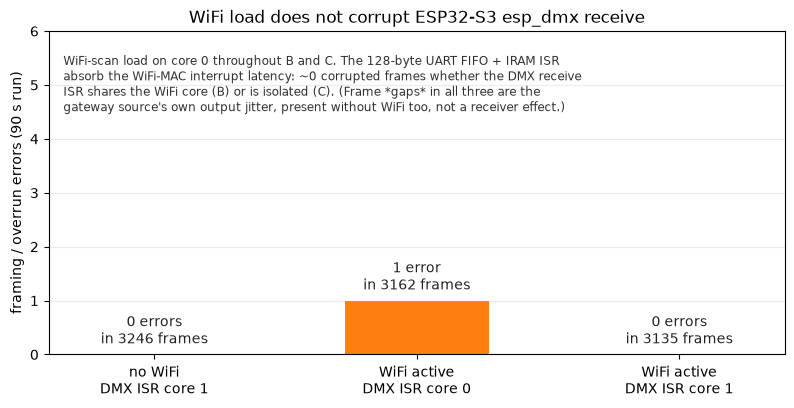
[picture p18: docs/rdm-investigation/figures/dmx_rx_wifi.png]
With WiFi-scan load running throughout, the DMX-receive framing-error count stayed at ~0 whether the receive ISR shared the WiFi core (B) or was isolated on core 1 (C), the same as no-WiFi (A). The 128-byte FIFO + IRAM ISR absorb the WiFi-MAC interrupt latency. ~3,200 frames per condition.


**And under real sustained traffic, not just scan load.** I joined the receiver to the bench WiFi as a
station and had a host blast a continuous TCP stream at it (a raw sink on the device, drained as fast as it
arrived) while it kept receiving DMX. Over the ~50 s flood the framing-error count did not move: **0 new
errors with the DMX ISR isolated on core 1, and 0 new with it sharing the WiFi core (core 0)**. So real
heavy traffic does not corrupt receive either. One detail fell out: with the DMX ISR on the WiFi core the
*network* throughput dropped (2.9 to 0.7 Mbit/s on this weak-signal link), because the DMX ISR and driver
now compete for that core. The DMX receive still wins, it is high-priority and in IRAM; it is the WiFi
bandwidth that gives way. So even in the worst placement the lights stay safe, you just pay for it in
network speed, which is one more reason to keep DMX on its own core.

**So what actually breaks it?** Two more runs nail the mechanism by reproduction. First I deliberately
blocked interrupts on the receive core for 8 ms every 100 ms, longer than the 5.6 ms FIFO budget: framing
errors jumped to **25 in 60 s, about 13x the baseline's 2**. That is the failure, on demand: hold the ISR
off longer than the FIFO depth and slots are lost. (The source here is only ~36 Hz with idle gaps between
frames, so this is a lower bound; a back-to-back console stream would lose more.) Then I ran *real* flash
writes during receive (NVS commits, which disable the flash cache for milliseconds at a time): framing
errors stayed at **3, the same as baseline**. esp_dmx survives that because its ISR is in IRAM and keeps
executing through the cache blackout. A DMX library whose ISR is **not** in IRAM would freeze during
exactly those flash blackouts (and during the cache-disable windows WiFi creates) and corrupt receive.
That is the most likely root of "ESP32 DMX receive is unreliable" reports like yours: not WiFi interrupt
latency in itself (the FIFO soaks that up), but a driver or a code path that holds the receive ISR off
longer than the FIFO can cover. esp_dmx is built to avoid it; a lot of simpler DMX libraries are not.

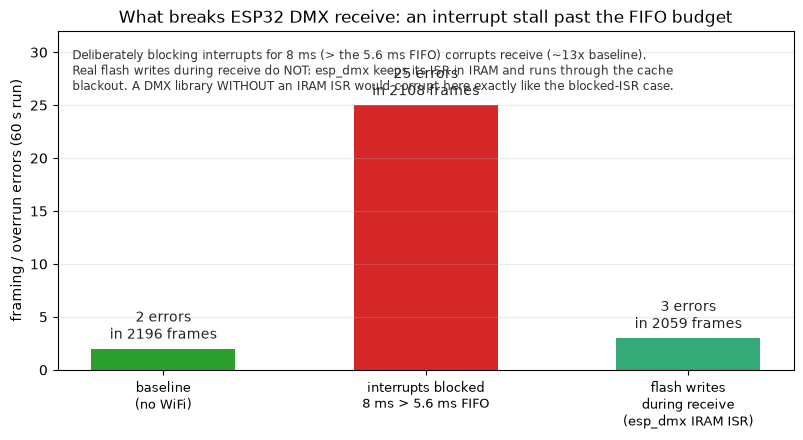
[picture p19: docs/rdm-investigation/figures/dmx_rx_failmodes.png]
Receive failure modes, measured (~2,100 frames / 60 s each). Only blocking interrupts past the 5.6 ms FIFO budget corrupts receive (~13x baseline). Real flash writes during receive do not, because esp_dmx's IRAM ISR runs through the cache blackout; a driver without an IRAM ISR would corrupt here ju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


I measured this exact effect from the controller side. The DMX/RDM transmit + turnaround runs in
the Arduino `loop()` task, and the moment I put the device under WiFi/HTTP load a higher-priority
network task preempts it: the TX→RX turnaround stretched from ~15 µs to ~50–125 µs (data in §6.2,
root cause §7). On receive the same preemption costs you slots. So a "rock-solid across many
sources" ESP32 DMX *receiver* needs the UART servicing isolated from WiFi: per-byte/break handling
in an IRAM ISR, the DMX work pinned to a core away from WiFi at high priority, and ideally the
frame-edge handling (break detect, the turnaround) moved fully into hardware/ISR rather than a task.

Which is the same conclusion you reached from the other end: a small dedicated MCU as an external
UART is rock-solid because it does *nothing else* — no WiFi, no scheduler, no contention. Your 8-pin
PIC is a hardware version of "isolate the DMX timing from everything else." On the ESP32 you can get
most of the way there in software (IRAM ISR + core pinning), and my fix (§8) is exactly that for
the transmit/turnaround path; for a bulletproof multi-source *receiver* the external-UART approach
(PIC, or an RP2040 PIO doing the DMX framing) is still the most robust, and is the path I'd take
for a product that must receive from arbitrary consoles. For *transmit + RDM controller* duty — what
LuxDMX does — the ESP32 with esp_dmx is solid once the timing is isolated from WiFi.

To directly answer "how extensively have you tested the output": output (TX) I've exercised
continuously (40 Hz null frames + Art-Net-driven) plus full RDM controller traffic on a hardware
bench with a logic analyzer; it's solid. On *receive*, I've now run an ESP32-S3 (esp_dmx) as a DMX
receiver on the same bench through the whole gauntlet: 10k+ frames with zero framing/overrun errors (WiFi
off); with WiFi-scan load, ISR on the WiFi core and isolated, still ~0 (1 in ~9,500); with a sustained
real-traffic TCP flood at the device while it receives, still 0 new; and through real flash writes mid-
receive, still ~0 (the IRAM ISR runs straight through the cache blackout). So the receive path is sound,
and the WiFi and flash conditions that wreck a naive driver do not corrupt it. The one piece left is the
spread across many *real* consoles with their odd break / MAB / inter-slot timing, which needs actual
desks (or a precision PIO source feeding adversarial timing); that's the last item and it's on the list.

## 10. Cross-validation, limitations, next steps

**Validated:** LA time base (0 % error / 0 jitter vs known 1–250 kHz, §4); decoder (recovered a
planted DMX channel value); every number is N≥20. The turnaround result agrees two ways: on the
wire (LA) and functionally (discovery reliably succeeds).

**Scope, and why the *receive* case is genuinely harder.** This study covers the RDM *controller*
path — sending requests, the TX→RX turnaround, and receiving the short replies (the controller's
receive path was intact in every capture; the full preamble + UID always arrived). It deliberately
does **not** cover using the ESP32 as a continuous-DMX *receiver*, which is the harder job, for a
structural reason. The controller receives *occasionally and on its own schedule*: it asks, then
listens for one short reply inside a generous 2800 µs window — so there is slack, and a slightly late
reply (or an interrupt serviced slightly late) is still caught. A continuous receiver has **no slack**:
it must take a per-byte UART interrupt every ~44 µs, back-to-back, 513 bytes per frame, ~40 times a
second, indefinitely, on a clock set by an external console it does not control (and across consoles
whose break / MAB / inter-slot timing differs and is sometimes marginal). Miss a single byte-deadline —
because a WiFi interrupt ran first — and the RX FIFO overflows, the frame is corrupted, and a fixture
visibly glitches. The very mechanism measured here (interrupt latency rising under WiFi load) costs the
*controller* only a thinner margin, but would cost a continuous *receiver* a dropped byte. That is why
the forum builder found ESP32 DMX receive unreliable across sources, and why a dedicated small MCU — or
an RP2040 PIO state machine — doing nothing but the UART, with no WiFi or scheduler to steal cycles, is
the robust answer for *that* role. It does not change the controller result: LuxDMX transmits DMX and
runs RDM; it does not receive a DMX stream. (The turnaround's "request-end" reference carries ≤4 µs of
byte-position jitter — a conservative over-estimate that only makes the margins look slightly worse
than they are.)

**Next steps.** (1) **Wired-Ethernet RDM is fixed** (core isolation, §8) and validated on-device at 100 %
steady-state. What remains there is optional: confirm the ~1 s responder re-arm against a second
(ideally deterministic) responder, and speed up the esp_dmx discovery sweep by re-enabling its disabled
leaf-pruning. (2) **Receive path: measured across the board, one case left.** No-WiFi (10,157 frames, 0
errors), WiFi-scan load on/off the DMX core, a sustained real-traffic TCP flood, the deliberate ISR-stall
reproduction, and real flash writes during receive are all done (§9): the chip receives DMX cleanly, and
the WiFi and flash conditions that wreck a naive driver do not corrupt esp_dmx (IRAM ISR + the 128-byte
FIFO). The one piece left is the spread across many *real* consoles with their odd break / MAB / inter-slot
timing, which needs actual desks, or a precision RP2040 PIO source feeding adversarial timing on its own
rig. (3) **Cross-check the LA's time
base** with a second, independent capture method (e.g. an RP2040 / sigrok logic analyzer).

## 11. Update (rev 2): RMT-DMX and the esp_dmx-free RDM path

*Added July 2026. §4 through §10 record the original esp_dmx-based measurements and stand as written;
this section documents the structural fix that replaced the core-affinity tweak of §8 and its
validation on real ESP32-S3 hardware.*

### 11.1 Why a structural fix

§7 traced the RDM turnaround jitter to interrupt latency: the RTS flip rides an esp_dmx UART ISR, and
network DMA stretches that ISR under load. The same mechanism has a transmit-side twin. A user on the
WT32-ETH01 (issue #64) saw the DMX *output* pick up framing errors on a Swisson tester once wired
Ethernet was busy: esp_dmx clocks the break and MAB from a timer ISR, and under RMII-Ethernet DMA that
ISR is delayed just enough to malform a frame's break. Moving tasks between cores narrows the tail
(§8) but does not remove the dependency: as long as the frame timing is produced by an ISR, a late ISR
can still corrupt a frame.

The fix that removes the dependency is to stop timing DMX from an ISR at all.

### 11.2 RMT-DMX (transmit)

DMX transmit now runs through the ESP32 **RMT peripheral** (`dmx_rmt.h`). A frame is pre-encoded into a
(level, duration) symbol stream and the RMT clocks it out entirely in hardware at its own 1 MHz tick
(1 tick = 1 µs, one DMX bit = 4 ticks, exact, no jitter). The CPU only refills a buffer; the timing is
the RMT's. If a refill is ever late the RMT idles the line HIGH (a benign extra mark) instead of
corrupting the break, so the failure mode of §7 simply cannot happen on transmit. On the S3 the first
output takes the one DMA-capable RMT channel (the IDF driver is blunt about it: "Only the last channel
has the DMA capability") and streams a whole frame from RAM with no refill ISR at all; a second output
falls back to the refill-ISR path, which is safe here because DMX runs on core 1, away from the core-0
network DMA that caused #64.

Measured on the same LA rig as the rest of this report: **0 framing errors at 40.0 Hz under a
15,000 packet/s Art-Net flood**, on both the WT32-ETH01 (internal RMII) and a bare ESP32-S3 driving a
MAX485. Issue #64 does not reproduce on the RMT path.

### 11.3 esp_dmx-free RDM

With transmit on the RMT, the RDM controller was rebuilt to match (`rdm_rmt.h`): the request is sent
from the RMT channel, the reply is read on a dedicated **receive-only UART**, and the transceiver
direction (DE/RE) is a plain GPIO toggled around the transaction. The turnaround measured in §6/§8
(about 15 µs, comfortably inside the 176 µs budget) is preserved, and it no longer depends on an
esp_dmx UART ISR: the direction flip is now a direct GPIO write, so the class of contention §7
describes is gone from the turnaround too. The E1.20 behaviour is unchanged: discovery, GET and SET all
round-trip.

### 11.4 Validated on real ESP32-S3 silicon

The original numbers ran on the bench controller; rev 2 adds a full pass on an actual ESP32-S3 node
(RMT-DMA transmit), over both WiFi and the W5500 wired interface, against the RP2350 responder:

- DMX output clean at 40.0 Hz, 0 framing errors on both universes (`outfps [40, 40]`).
- RDM **discovery** found all 32 fixtures; **GET** DEVICE_INFO and the software-version label, **SET**
  DMX start address, and **sensor polling** (GET SENSOR_DEFINITION / SENSOR_VALUE against a responder
  exposing a drifting temperature sensor) all round-tripped.
- W5500 wired came up cleanly once the SPI clock was dropped for the flying-lead bench: the default
  20 MHz hangs on jumper wires, 8 MHz is solid (`ethfreq`). On the real LuxDMX board 20 MHz is fine.

### 11.5 Crash-hardening found under stress

Pushing the node hard (sustained 15k packet/s floods with a WebSocket client and JSON polling open
throughout) surfaced a separate class of failure that has nothing to do with DMX timing. Under
post-flood heap **fragmentation** (esp-idf #13588: the free heap stays high but the largest contiguous
block collapses) a large contiguous allocation in the web / OTA / WebSocket paths could throw an
uncaught `bad_alloc` and reboot the node. That reboot, not the wire, was the source of the occasional
framing-error bursts seen during a flood: the DMX line was clean until the node reset and sprayed
garbage on the way down. Fixes: guard the big allocations on the largest-contiguous-block figure (not
total free) with a try/catch backstop, degrade to a 503 or a skipped push instead of aborting, and
stream `/dmx.json` in ~1.4 KB chunks so it needs no large contiguous buffer at all. After that a 15k
packet/s flood produced **0 reboots, 0 aborts, and the DMX output stayed clean throughout**. On a wired
S3 (heap around 153 KB) there were zero 503s; the fragmentation pressure is a WiFi-heap effect.

### 11.6 What this changes, and what it does not

The reliability picture from §8 and §10 is unchanged and, if anything, stronger: RDM is a solid
controller over WiFi and wired, and the DMX output is now clean under load by construction rather than
by task placement. The core-affinity change of §8 is no longer the mechanism that carries the fix (the
RMT path does), though keeping the network work on core 0 is still good hygiene. The receive-path study
of §9 stands unchanged: LuxDMX transmits DMX and runs RDM, it does not receive a continuous DMX stream,
and a dedicated small MCU or an RP2040 PIO is still the right tool for that separate job.

## Appendix A. LA firmware (`s3-logic-analyzer`)  ·  B. `la_analyze.py`  ·  C. raw captures + figures
*(listings attached in the repo; figures/hr05_timing.png is the reference transaction.)*

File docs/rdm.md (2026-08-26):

# RDM Plan — Remote Device Management (E1.20) for LuxDMX

Add **RDM** to LuxDMX: auto-discovery + bidirectional comms, on top of the existing
Art-Net / sACN → DMX output.

> **Status (implemented).** RDM is built. The controller no longer rides on esp_dmx — it's a
> self-contained **RMT-TX + UART-RX** engine (`src/rdm_rmt.h`) that shares the DMX output's RMT
> channel: it transmits DISC/GET/SET requests through RMT, flips the transceiver's DE/RE (a plain
> GPIO) to receive, and reads the reply on a dedicated RX-only UART. No peripheral install/teardown
> per transaction, so nothing leaks or stalls the DMX clock. Discovery is an **iterative** binary
> search (an explicit range stack, not recursion — a 48-deep recursion overflowed the DMX task
> stack and reset the board) and re-reads a garbled branch before calling it a collision, so a stray
> bit flip on a lone fixture doesn't split forever. Trigger it over HTTP (`/rdm/discover`,
> `/rdm/setaddr`, `/rdm/identify`) or the web UI. Validated on the RP2350 responder rig: discovery +
> GET DEVICE_INFO / SW_VERSION_LABEL + SET address / identify all round-trip. This design doc below
> is the original plan and the hardware/transceiver background — still accurate except that the
> firmware path is now RMT, not esp_dmx.
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

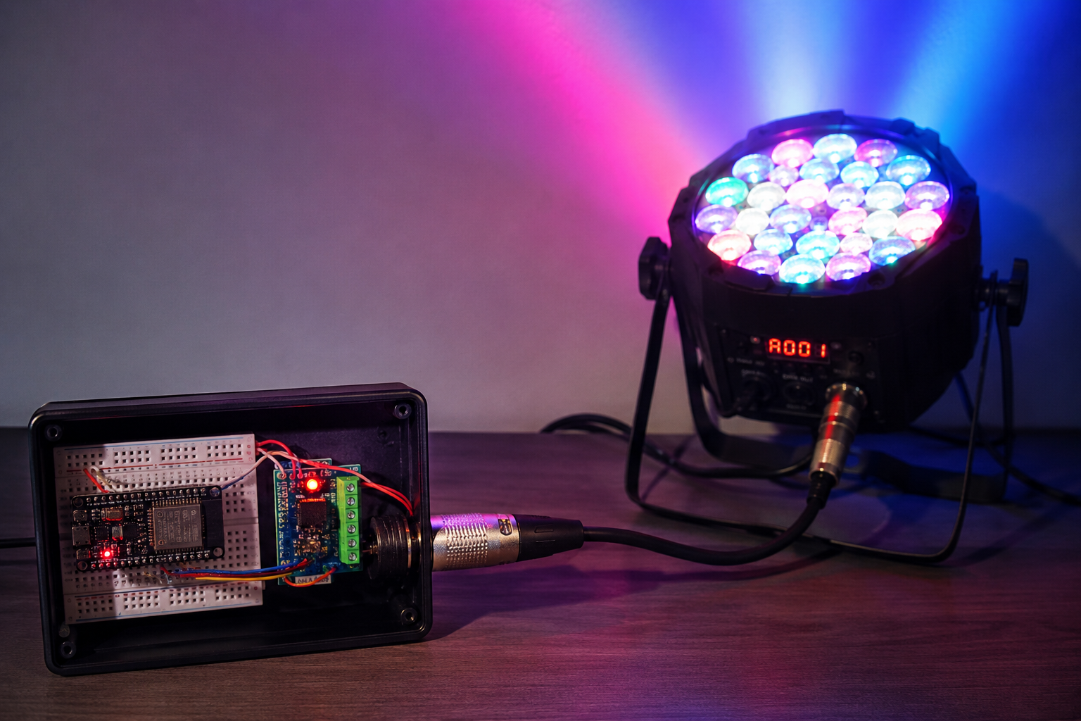
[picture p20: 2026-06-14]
docs/mock1.png

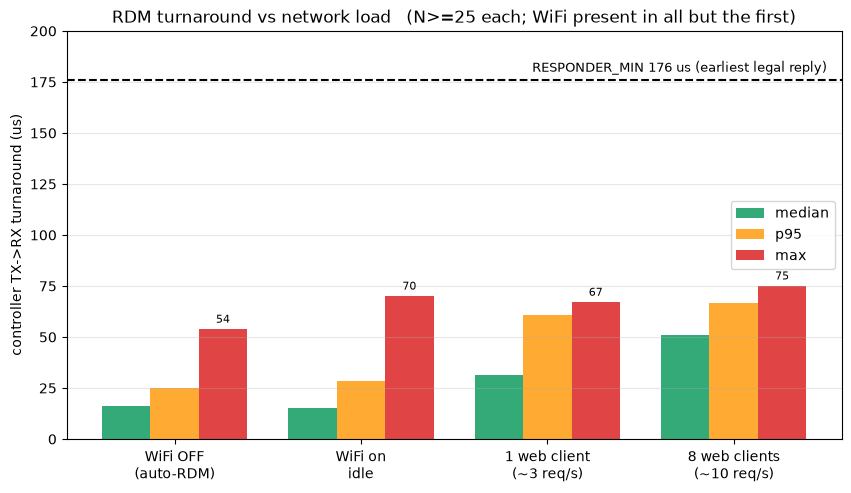
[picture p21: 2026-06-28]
docs/rdm-investigation/figures/wifi_turnaround.png

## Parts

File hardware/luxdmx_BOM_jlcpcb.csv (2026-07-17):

Comment | Designator | Footprint | LCSC Part #
100nF 0402 | C1,C5,C8,C9,C10,C11,C14,C18,C19,C22,C23,C24 | C_0402_1005Metric | C1525
10uF 0805 | C2,C28 | C_0805_2012Metric | C15850
1uF 0402 (EN power-on RC) | C3,C4 | C_0402_1005Metric | C52923
4.7uF 0402 | C6 | C_0402_1005Metric | C23733
18pF 0402 C0G (W5500 xtal load, CL=12pF) | C12,C13 | C_0402_1005Metric | C307443
22uF 0805 | C16,C17,C29 | C_0805_2012Metric | C45783
10uF 1206 | C20,C21,C25,C26 | C_1206_3216Metric | C13585
100uF 25V SMD electrolytic (PoE output bulk) | C27 | CP_Elec_6.3x7.7 | C970685
1uF 0603 (TPS2116 VIN1 input cap) | C30,C31 | C_0603_1608Metric | C15849
SM712 TVS SOT-23 | D1,D7 | SOT-23 | C404012
LED red 0603 | D2 | LED_0603_1608Metric | C2286
LED green 0603 KT-0603G | D3 | LED_0603_1608Metric | C12624
LED yellow 0603 NCD0603Y2 | D4 | LED_0603_1608Metric | C89811
LED blue 0603 KT-0603B | D5 | LED_0603_1608Metric | C2288
LED white 0603 | D6 | LED_0603_1608Metric | C2290
SMAJ58A TVS SMA (rectified-PoE surge clamp) | D10 | D_SMA | C110521
SMAJ5.0A TVS SMA (+5V transient clamp) | D11 | D_SMA | C151932
BSMD1206-150-16V 1.5A/16V resettable PPTC fuse (USB VBUS) | F1 | Fuse_1206_3216Metric | C883133
TBU-CA065-200-WH 200mA 650V high-speed protector (DMX Protected series) | F2,F3,F4,F5 | DIO-SMD_3P-L6.5-W4.0-BI | C913221
600R@100MHz ferrite bead 0805 (+5V to DMX DC-DC) | FB1,FB2,FB3 | L_0805_2012Metric | C1017
Neutrik NC5FAH XLR-5 female horizontal PCB (E1.11 DMX out) | J1,J5 | CONN-TH_NC5FAH | C368501
USB-C data (TYPE-C-31-M-12) | J2 | USB-C_SMD-TYPE-C-31-M-12_1 | C165948
RJ45 MagJack HY931147C PoE 10/100 (integrated rectifier + magnetics) | J3 | RJ45-TH_HY931147C | C91754
JST SH 1.0mm 9-pin SMD SM09B-SRSS-TB (optional display; pre-crimped cables) | J4,J6 | JST_SH_SM09B-SRSS-TB_1x09-1MP_P1.00mm_Horizontal | C160408
JST SH 1.0mm 3-pin SMD SM03B-SRSS-TB (DMX-A breakout) | J7,J8 | JST_SH_SM03B-SRSS-TB_1x03-1MP_P1.00mm_Horizontal | C160403
2.2uH power inductor (CKCS4030) | L1 | IND-SMD_L4.0-W4.0 | C354584
ACM2012-201-2P common-mode choke (DMX-A pair) | L2,L3 | L_CommonModeChoke_Coilank_ACM2012 | C383338
B0505S-1W iso DC-DC (EVISUN) | PS1,PS2 | PWRM-TH_B0505S-1W | C7465127
10k 0402 | R1,R2,R11,R25 | R_0402_1005Metric | C60490
12k 0402 W5500 EXRES1 (12.4k spec OOS at LCSC; 12k within 100BASE-TX +-5%) | R3 | R_0402_1005Metric | C25752
330R 0402 | R4,R5 | R_0402_1005Metric | C2930002
5k1 0402 | R8,R9 | R_0402_1005Metric | C25905
45.3k 0402 1% (buck FB top -> 3.32V) | R10 | R_0402_1005Metric | C2933099
120R 0805 (DMX-A termination) | R12,R19 | R_0805_2012Metric | C17437
1k 0402 | R13,R15 | R_0402_1005Metric | C106235
150R 0402 | R14,R16,R17 | R_0402_1005Metric | C2909321
49.9R 1% 0402 W5500 TX center-tap bias | R18 | R_0402_1005Metric | C25120
470R 0402 (DMX-A fail-safe bias) | R20,R21,R22,R23 | R_0402_1005Metric | C2909361
30k 0402 1% (TPS2116 PR1 divider top, Vsw=4.0V) | R24 | R_0402_1005Metric | C138008
tact sw B3U-1000P | SW1,SW2 | SW_SPST_B3U-1000P | C231329
ESP32-S3-WROOM-1-N8R2 (8MB flash + 2MB quad PSRAM; quad keeps IO35/36/37 free, octal R8 would not) | U1 | ESP32-S3-WROOM-1 | C2913204
W5500 SPI Ethernet | U2 | LQFP-48_L7.0-W7.0-P0.50-LS9.0-BL | C32843
SY8089 buck 5->3.3V | U4 | SOT-23-5_L3.0-W1.7-P0.95-LS2.8-BR | C78988
ISO3086DWR isolated RS-485 | U5,U6 | SOIC-16_L10.3-W7.5-P1.27-LS10.3-BL | C183095
DP9900M-5V PoE PD + isolated DC-DC module (802.3af) | U7 | PWRM-SMD_DP9900M-5V | C5380106
USBLC6-2SC6 USB ESD/TVS array (SOT-23-6) | U8 | SOT-23-6 | C7519
TPS2116DRLR ideal-diode power mux (USB/PoE 5V OR-ing) | U9 | SOT-583-8 | C3235557
25MHz crystal 3225 SMD (C9006 X322525MOB4SI, CL=12pF, mainstream/always-in-stock pkg) | Y1 | Crystal_SMD_3225-4Pin_3.2x2.5mm | C9006

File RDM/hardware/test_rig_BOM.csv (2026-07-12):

Qty | Designators | Value | Description / part
4 | J_485A_L,J_485A_R,J_485B_R,J_485B_L |  | Female header socket 1x5, 2.54mm
1 | J_LA |  | Pin header (male) 2x8, 2.54mm
1 | J_MEAS |  | Pin header (male) 1x7, 2.54mm
2 | J_PICOA,J_PICOB |  | Female header socket 1x20, 2.54mm
2 | J_S3B,J_S3A |  | Female header socket 1x22, 2.54mm
1 | J_TERM |  | Screw terminal 3-pin, 5.08mm
1 | J_W5500 |  | Female header socket 2x5, 2.54mm
2 | Rb1,Rb2 | 270R | Resistor THT axial, 7.62mm pitch
4 | Rd1,Rd2,Rd3,Rd4 | 10k | Resistor THT axial, 7.62mm pitch
# plug-in modules (seat in the sockets, not soldered / not on the PCB)
1 |  |  | ESP32-S3-DevKitC-1 - DUT: LuxDMX controller (0.9" / 2x22)
1 |  |  | Pimoroni Pico Plus 2 W (RP2350) - RDM simulator (standard Pico 2x20)
2 |  |  | MAX485 module (RXD/TXD variant) - one per node, cross-wired
1 |  |  | W5500 SPI Ethernet module (2x5) - for the S3

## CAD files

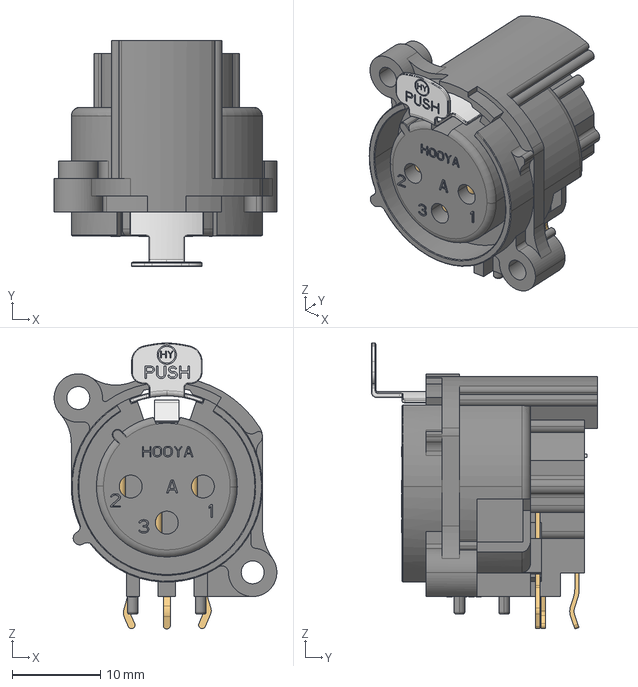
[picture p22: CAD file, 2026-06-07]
hardware/3d/XLR-328P.step
25.3 x 25.7 x 32.5 mm

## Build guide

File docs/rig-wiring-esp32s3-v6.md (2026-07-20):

# HIL rig wiring, ESP32-S3 (luxdmx_v6 pinout) + MAX485 + W5500

The hardware-in-the-loop bench with an **ESP32-S3** as the controller, wired to a MAX485
transceiver for DMX/RDM and a W5500 for wired Ethernet, with an RP2350 acting as the
DMX analyzer / ground-truth / RDM responder on the bus.

Firmware: there is no dedicated v6 env any more — build the released `esp32s3dev` target with the
source-build escape-hatch flags so it boots straight into the v6 pin map (see platformio.ini):
`pio run -e esp32s3dev --build-flags "-DBOARD_LUXDMX_V6 -DDEFAULT_TEMPLATE=luxdmx_v6"`
then flash the factory image over USB:
`esptool --chip esp32s3 --port <COM> --baud 921600 write_flash 0x0 .pio/build/esp32s3dev/firmware.factory.bin`
(a factory flash wipes NVS → fresh config below; set WiFi/`useeth` afterwards over the serial console).
Or flash a plain `esp32s3dev` build and apply the **LuxDMX v6** board template in `/config` instead.

## Controller pins (luxdmx_v6 config defaults)

| Signal | S3 GPIO | config key |
|---|---|---|
| Output 0 DMX out (DI) | **GPIO17** | `o0_tx=17` |
| Output 0 RDM rx (RO)  | **GPIO18** | `o0_rx=18` |
| Output 0 DE/RE (dir)  | **GPIO8**  | `o0_rts=8` |
| Status LED (5-panel)  | 1/2/6/7/15 | `ledtype=3`, `ledr/g/y/b/w` |

## S3 → MAX485 (DMX / RDM transceiver)

```
  S3 GPIO17 (o0_tx) ─────► DI            A ─┬───────────► DMX bus A ──► RP responder
  S3 GPIO18 (o0_rx) ◄───── RO   MAX485   B ─┤
  S3 GPIO8  (o0_rts)─────► DE + RE (tied)   │  220R bias: A→3V3, B→GND ; 120R term across A/B
  3V3 ──────────────────► VCC              GND ── common
  GND ──────────────────► GND
```
- Module is DE-only style: DE and RE tied together, driven by `o0_rts`. Receiver stays live so
  the controller reads its own echo / the RDM reply on `o0_rx`.
- **Gotcha (bit us):** if the module is silk-labelled **RXD/TXD** instead of DI/RO, cross them,
  the receive line is `TXD (=RO) → MCU RX (GPIO18)`, NOT name-matched. Name-matching floats the RX
  pin: RDM sends fine but no reply comes back and discovery finds 0.

## S3 → W5500 (SPI wired Ethernet)

| W5500 | S3 GPIO | config key |
|---|---|---|
| SCS / CS | **GPIO10** | `ethcs=10` |
| SCLK / SCK | **GPIO12** | `ethsck=12` |
| MOSI / SI  | **GPIO11** | `ethmosi=11` |
| MISO / SO  | **GPIO13** | `ethmiso=13` |
| INT | **GPIO14** | `ethint=14` |
| RST | **GPIO9**  | `ethrst=9` |
| VCC | 3V3 | n/a |
| GND | GND | n/a |

- W5500 modules are **3.3 V logic**, power from 3V3, not 5 V.
- Enable it in firmware: set both `useeth=1` and `ethon=1` (serial console), then `save reboot`. A
  bare `key=value` only writes RAM, without `save` it's gone on the next boot. Default is off, so
  out-of-the-box the board comes up on WiFi.
- **Do NOT use the generic `esp32s3dev` env's default W5500 pins**, they're inherited from the
  classic-ESP32 base and include GPIO23/25, which don't exist on the S3. Use the pins above.
- **SPI clock (bit us):** the default `ethfreq=20` (20 MHz) is fine on the real LuxDMX board but too fast
  for flying breadboard leads, the W5500 bring-up then HANGS in `ETH.begin()` (no serial after the
  banner, looks like a wiring fault but isn't). On this jumper-wire bench it comes up clean at
  `ethfreq=8`. Drop the clock before you suspect the wiring. Recover a hung board by re-flashing the
  factory image (resets the config).

## RP2350 analyzer / responder taps

```
  RP GP5  (ground-truth UART @250k) ◄── S3 GPIO17  (o0_tx, DMX out, logic-level tap, before/at DI)
  RP GP13 (reply capture)           ◄── S3 GPIO18  (o0_rx, the RDM reply line)
  RP transceiver A/B                ◄─► DMX bus A/B  (RP is the fixture responder + PIO analyzer)
  Common GND between S3, MAX485, W5500, and the RP, required.
```
- `gtRefresh`/`gtFramingErr` (the GP5 UART) are the authoritative "is the DMX output clean" numbers.
- **Gotcha (bit us):** GPIO16 vs GPIO17. If the DMX-out tap/DI land on GPIO16 instead of 17, the S3
  reports `outfps 40` but nothing reaches the analyzer. Confirm the out signal is on **GPIO17**.
- The GP5 ground-truth tap is clamped to **one** output's TX pin, while the RS485 pair carries
  whichever output is wired to the transceiver. Wire the bus to output B (GPIO16) and leave GP5 on
  GPIO17 and you get `gtFrames: 0` forever: the second tap is watching an output nobody is driving.
  The wire specs treat "0 frames seen" as "tap not wired" and skip the ground-truth assertions
  rather than reporting a vacuous 0 errors, but on a bench where both taps matter, move GP5 too.

## Driving this rig from the e2e suite

`docs/tests/dmx-wire.spec.mjs` and `rdm-wire.spec.mjs` measure the DMX output and the RDM
transactions through this analyzer instead of trusting the gateway's own counters:

```bash
cd docs
LUXDMX_ANALYZER=<rp2350-ip> LUXDMX_URL=http://<gateway-ip> LUXDMX_WRITE=1 npm test
```

The specs probe which output the analyzer actually hears (marker pattern per output, then look at
the line), so they follow a re-wired bench instead of assuming output A. The analyzer needs a build
whose `/api/dmx` publishes under a seqlock — see the note in `docs/tests/README.md`.

## Verified on this rig (2026-07-09)
- RMT-DMA DMX output clean: 40.0 Hz, 0 framing errors (first real-S3 validation of the RMT path).
- RDM discovery 32 fixtures + GET DEVICE_INFO / SW label / sensor polling all good.
- Crash fixes hold: 15k pkt/s flood + WS + JSON poll, 0 reboots / 0 aborts, DMX stayed clean.

## S3-specific quirks found here (now handled)
- **Only one DMA-capable RMT channel** (was: `rmt: no free tx channels` on out1). The S3 has 4 RMT
  TX channels but the IDF driver can DMA only the *last* one ("Only the last channel has the DMA
  capability"). So out0 claims the DMA channel; out1 can't get a second one. `dmx_rmt.h` now tries
  DMA first and falls back to the non-DMA refill-ISR path, so both universes init (`outfps [40,40]`).
  The refill ISR runs on core 1, away from the core-0 network DMA that made DMA necessary for #64,
  so the fallback is safe.
- **Post-flood heap fragmentation (WiFi only).** Under a heavy flood `minFree` dips to ~1 KB; afterward
  the free heap is fine (~99 KB on WiFi) but too fragmented for one big contiguous response, the
  known esp-idf #13588 behaviour. `/dmx.json` is now streamed with `sendChunked` (small ~1.4 KB
  segments, no large alloc), and `sendJsonSafe` guards the remaining dynamic-JSON handlers to a clean
  503 instead of a `bad_alloc` crash. On the **wired** S3 (heap ~153 KB) the flood produced **zero**
  503s. If you want maximum headroom, run wired.

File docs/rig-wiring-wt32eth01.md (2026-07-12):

# HIL rig wiring, WT32-ETH01 + MAX485

The hardware-in-the-loop bench with a **WT32-ETH01** (ESP32 + on-board LAN8720 RMII Ethernet)
as the controller, wired to a MAX485 for DMX/RDM, with an RP2350 as the DMX analyzer /
ground-truth / RDM responder on the bus.

Firmware: `wt32eth01` env (RMT DMX + the crash fixes). It clocks DMX out of RMT and uses the
on-board wired Ethernet, so there is **no W5500 to wire**, just plug the RJ45 into the LAN.
OTA update: `curl -F firmware=@.pio/build/wt32eth01/firmware.bin http://<ip>/ota/upload`.

## Controller pins (this rig's running config)

| Signal | WT32 GPIO | config key |
|---|---|---|
| Output 0 DMX out (DI) | **IO5**  | `o0_tx=5` |
| Output 0 RDM rx (RO)  | **IO4**  | `o0_rx=4` |
| Output 0 DE/RE (dir)  | **IO33** | `o0_rts=33` |
| Output 1 DMX out | IO32 | `o1_tx=32` (unwired on this rig) |

Note: the `wt32eth01` template default is `o0_tx=4 / o0_rx=5`; this bench runs them swapped
(`o0_tx=5 / o0_rx=4`) to match the physical wiring. Use whatever matches your board, the ground
truth is: DMX out is on IO5, RDM rx is on IO4.

## WT32 → MAX485 (DMX / RDM transceiver)

```
  WT32 IO5  (o0_tx) ─────► DI            A ─┬───────────► DMX bus A ──► RP responder
  WT32 IO4  (o0_rx) ◄───── RO   MAX485   B ─┤
  WT32 IO33 (o0_rts)─────► DE + RE (tied)   │  220R bias: A→3V3, B→GND ; 120R term across A/B
  3V3 ──────────────────► VCC              GND ── common
  GND ──────────────────► GND
```
- DE-only style module: DE + RE tied, driven by `o0_rts`. Receiver stays live so the controller
  reads its own echo / the RDM reply on `o0_rx`.
- **Gotcha:** RXD/TXD-labelled modules must be crossed (`TXD=RO → MCU RX`), not name-matched, or the
  RX pin floats and RDM replies never arrive.

## Ethernet

On-board **LAN8720 RMII**, nothing to wire, just the RJ45 to the LAN. (RMII uses IO0/IO16-19/21-23/25-27
internally; keep DMX/other pins off those.) Enabled via `useeth=1`, `wiredphy=1`.

## RP2350 analyzer / responder taps

```
  RP GP5  (ground-truth UART @250k) ◄── WT32 IO5  (o0_tx, DMX out, logic-level tap)
  RP GP13 (reply capture)           ◄── WT32 IO4  (o0_rx, the RDM reply line)
  RP transceiver A/B                ◄─► DMX bus A/B  (RP is the fixture responder + PIO analyzer)
  Common GND between WT32, MAX485, and the RP, required.
```
- `gtRefresh`/`gtFramingErr` (the GP5 UART) are the authoritative "is the DMX output clean" numbers.

## Verified on this rig
- RMT DMX output clean: 40.0 Hz, 0 framing errors, even under a 15k pkt/s Art-Net flood (issue #64 fix).
- Crash fixes hold: heavy flood + WebSocket + `/rdm.json` poll → 0 reboots, 0 aborts, DMX stayed clean.
- 5-hour realistic soak: 37 cycles, 0 reboots, no leak.

## Serial
- USB-serial is a CH340 (open DTR/RTS low so opening the port doesn't reset the running board).
- Logger streams to `C:\tmp\wt32_serial.log`; stop it before using the COM port for a serial write,
  restart after.

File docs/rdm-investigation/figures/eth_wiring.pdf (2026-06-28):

# Attach a W5500 SPI-Ethernet module to the DUT

All six GPIO are configurable in LuxDMX (/config -> W5500 card, or set ethcs/ethsck/...). The DUT is already set to these. Wire to these pins and you only need to flip "use Ethernet" once the module is connected; or wire anywhere free and change the config.

ESP32-S3 (DUT) | W5500 module
3V3 | 3V3

power (3.3 V logic — NOT 5 V on the S3)

GND | GND

common ground (DUT + W5500 + bench)

GPIO12 | SCLK

SPI clock

GPIO11 | MOSI

SPI master out (W5500 DI)

GPIO13 | MISO

SPI master in (W5500 DO)

GPIO10 | SCS

chip select

GPIO14 | INT

interrupt (active low)

GPIO9 | RST

reset (active low)

Keep SPI wires short. If the link is flaky on long/loose wiring, lower the clock: set ethfreq 1
These six GPIO (9–14) do not touch the DMX/RDM pins under test (TX17 · EN8 · RX18) — the RDM bench is undisturbed.

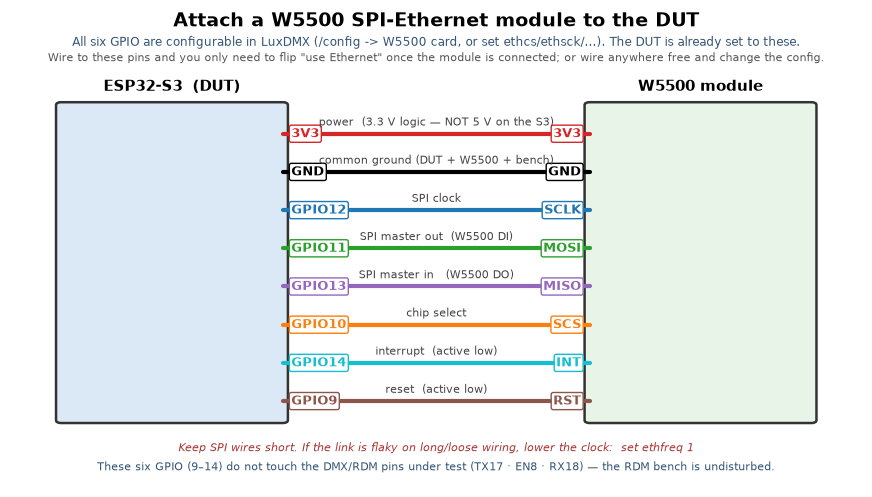
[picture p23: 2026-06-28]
docs/rdm-investigation/figures/eth_wiring.png

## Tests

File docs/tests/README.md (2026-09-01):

# LuxDMX end-to-end test suite

Playwright tests that drive a **live LuxDMX device** end-to-end: they send real
Art-Net and sACN/E1.31 packets over the network and assert the device's REST API,
WebSocket, and web UI react correctly.

## Prerequisites

- A LuxDMX on the same LAN, reachable and powered.
- Node 21+ (uses the built-in global `WebSocket`).
- *Optional*, for the two on-the-wire specs: an [RP2350 analyzer](https://github.com/tombueng/dmx-analyzer)
  on the gateway's DMX line (see [Measuring the wire](#measuring-the-wire)).
- Dependencies + the Chromium browser:

```bash
cd docs
npm install
npx playwright install chromium
```

## Run

```bash
cd docs
npm test                 # all default (non-destructive) tests
npm run test:headed      # watch the browser
npm run report           # open the last HTML report
```

### Targeting the device

Resolution order: `LUXDMX_URL` → mDNS lookup of `LUXDMX_HOST` → fallback IP
(`192.168.178.197`).

```bash
LUXDMX_HOST=dmx-gateway.local npm test
LUXDMX_URL=http://192.168.1.50 npm test
```

### Device-mutating tests (opt-in)

A few tests change config and reboot the device (multi-output round-trip, the
boot-loop regression). They are skipped unless you opt in:

```bash
LUXDMX_WRITE=1 npm test
```

They always restore the original configuration afterwards.

One more device-mutating test lives outside the Playwright runner, because it drives raw
sockets rather than a browser:

```bash
LUXDMX_WRITE=1 LUXDMX_URL=http://<ip> node docs/tests/ota-upload-truncated.mjs
```

It proves a firmware upload that stops mid-stream is rejected instead of being reported as
a success (see the header comment for the failure it guards). It writes the device's OTA
slot but never completes a valid image, so the running firmware is never replaced.

### Measuring the wire

`dmx-wire.spec.mjs` and `rdm-wire.spec.mjs` check what actually came out of the XLR, using an
[RP2350 analyzer](https://github.com/tombueng/dmx-analyzer) sitting on the DMX line as a second
pair of eyes (wiring: `docs/rig-wiring-esp32s3-v6.md`). Everything else in this suite asks the
gateway how it thinks it is doing; these two ask the bus.

```bash
LUXDMX_ANALYZER=192.168.178.105 LUXDMX_WRITE=1 npm test
```

- The analyzer has no mDNS, so point `LUXDMX_ANALYZER` (or `LUXDMX_ANALYZER_URL`) at its IP.
  Both specs **skip themselves** when nothing answers, so a run without the rig stays green.
- They work out which output they are watching by driving each enabled output with a marker
  pattern and seeing which one appears on the line, so re-wiring the bench between workstreams
  does not silently test an output nobody is listening to.
- The analyzer's `/api/dmx` must be a build with the seqlocked publish path (it reports a `tr`
  counter). An unlocked build serialises the frame buffer while the next frame overwrites it and
  reports ~2.9% torn frames that are the instrument, not the gateway — which is exactly the
  failure the torn-frame test is looking for.

### Standalone config-UI tests (no device, no Playwright runner)

These behaviour tests drive the real `src/pages/config.html` in a headless browser against a stub
device — run them directly with `node`, they self-report and exit non-zero on failure:

```bash
node docs/tests/v6-locks.mjs      # board detected as luxdmx_v6 -> copper pins locked + mirrored,
                                  #   the J4 display-header pins stay editable, headers listed
node docs/tests/v6-template.mjs   # generic S3 board -> picking the "LuxDMX v6" template fills the
                                  #   fixed pin map: W5500 SPI + LED + display + DMX pins get set,
                                  #   panel brightness is pushed to /led/bright?...&save=1, and the
                                  #   v6's copper pins lock behind the pick. This is the flow a v6
                                  #   owner uses now that there is no dedicated v6 build.
node docs/tests/board-persist.mjs # the picked board STICKS: /info.json boardSel beats the detected
                                  #   (compile-time) board id, the locks follow the restored pick,
                                  #   the selector submits as board=..., "custom" stays custom, a
                                  #   device with no saved pick still falls back to detection, and
                                  #   an unknown saved board degrades to detection instead of wedging
node docs/tests/dm9051-roundtrip.mjs  # a DM9051 box survives a /config save: the wired selector
                                  #   reads ethSpiPhy from /info.json and posts it back unchanged.
                                  #   Guards the bug where /info.json didn't publish the field, so
                                  #   any save silently rewrote a DM9051 device to W5500.
```

## What's covered

| Spec | Feature (network → web UI) |
|---|---|
| `web-ui.spec.mjs` | Pages load; REST contract (`/info`, `/dmx`, `/senders`, `/log`, `/version`, `/labels`, `/rdm`); W5500 SPI-Ethernet config fields + `/config` pin card; the W5500 role pins are not flagged "reserved" against their own role (Save stays enabled) and a fixed-pin board offers an Advanced unlock while the J4 display pins stay editable; the picker lists the J4 + J6 header pinouts and tags each header pad with its pin; **luxdmx_v6** shows J4/J6 with identical power pins (+3V3, GND) and no 5V anywhere on J6, IO35 on pin 3, UART0 on 7/8 and pin 9 a 2nd GND; the Join-WiFi link-loss fallback reveals the WiFi credentials on a wired box (AP fallback shows the AP password instead); home-page Update button → in-place install popup (newest version, no `/config` detour); OTA UI labelled "LuxDMX.org"; `/logo.webp` served as a small WebP image (replaces the ~117 KB PNG); the `/config` sections all start folded (summary in every header, unfold from the header, state remembered per browser, fields still submitted while folded, header switches keep working, Collapse/Expand all). Any test that drives a field on `/config` must unfold first — use `openConfig(page)` / `expandAll(page)` from [`lib/ui.mjs`](lib/ui.mjs) instead of a bare `page.goto('/config')` |
| `ota-url.spec.mjs` | Install firmware from a URL (`POST /ota/url`): a URL with no scheme (or `ftp://`, or empty) is refused with 400 and does **not** reboot the device, `GET` schedules nothing, and the Firmware Update card's URL form only enables its button for a real `http(s)://` URL. Opt-in: serves this repo's `firmware.bin` from a throwaway local HTTP server, points the device at it, and asserts the device really goes away, really fetches the image, comes back, and keeps hostname / universe / version. This is the path that works when a push upload can't: the device reboots and downloads with a pristine heap. |
| `reboot.spec.mjs` | Remote restart: `GET /reboot` must **not** restart anything (POST-only, so a prefetch or a crawler can't black out a live rig), the Device section offers a Restart button that is a plain button and not a form submit, and clicking it asks first with Cancel doing nothing. Opt-in: `POST /reboot` really does restart (the device is checked to actually go away, not just to answer), comes back within a minute, uptime restarts from zero, and hostname / universe / interface / WiFi SSID / LED config all survive — `/reboot` is not `/reset`. |
| `artnet.spec.mjs` | Art-Net ArtDMX → DMX values, live grid, sender + FPS tracking; tight back-to-back burst keeps tracking (socket-drain regression). The per-loop latency win itself needs a logic analyzer on the DMX wire and isn't asserted here. |
| `sacn.spec.mjs` | sACN / E1.31 → DMX values, live grid, sender tracking |
| `conflict.spec.mjs` | Two simultaneous senders → conflict banner |
| `merge.spec.mjs` | Issue #10: per-output merge mode shape + UI; HTP per-channel max, sACN priority override, LTP persistence (opt-in) |
| `changelog.spec.mjs` | DMX changes appear in `/log.json` + the change-log card |
| `manual-blackout.spec.mjs` | Manual override + per-channel set + blackout (via the UI) |
| `labels.spec.mjs` | Channel labels round-trip + grid rendering |
| `multi-output.spec.mjs` | Issue #4: `outputs[2]` shape, migration, RDM binding, UI; splitter + pin-less-output regression (opt-in) |
| `ota-update.spec.mjs` | `/ota/status` shape; home-page Update button → install popup → progress dialog shows the real phase/percent and only reloads onto the live page once the device reports the new version (full flash→update→restore cycle is opt-in) |
| `output-rate.spec.mjs` | Per-output DMX transmit rate + style (issue #93): `/info.json` carries `rate`/`style`/`styleSrc` plus a per-output beat flag (`beat`) and detected change rate (`chgHz`); `/config` renders both selectors including the 33.3 fps entry and the provenance badge; ArtPollReply `RefreshRate` tracks the configured rate and `GoodOutputB` bit6 the configured style; the navbar renders one C/D letter per output with a dot marking a style a controller pushed over Art-Net (and a ⚠ marking a beat risk), and spells it out in the tooltip. Behavioural (opt-in): picking 33.3 fps really moves the transmit rate off 40, Delta makes the output follow a deliberately slow source instead of free-running, Delta tracks the real change rate rather than the packet rate when the source repeats each frame 3x (the MagicQ-burst case that reopened #93), a Continuous output beating a rate-mismatched source raises the beat warning while Delta and a rate-matched source clear it (reading the ~33 Hz *change* rate, not the ~100 packets/s), and a silent source in Delta falls back to the configured rate so the line never stops. The duplicate-frame share, and the proof that the rate arrives on the *wire* rather than merely being scheduled, are in `dmx-wire.spec.mjs`. |
| `save-live.spec.mjs` | Saving `/config` only restarts when something that needs it changed: the save button reads `Save` (not `Save & Restart`); a live-only change (output B merge mode) applies with no modal, sticks, and uptime does not go backwards; a pin/driver-bound change (hostname) pops the modal, names the setting that forced the restart, and the device really does restart. Mutating parts opt-in via `LUXDMX_WRITE=1`, original hostname/merge restored. |
| *(bench only, not Playwright)* `tear_test.py` | Proves the DMX output frame is never read while it is being written. Fills all 512 channels with one value, so a torn frame shows as two values with a split point, and sweeps the input rate. A/B against the pre-fix firmware: 8.81% torn at 44 fps in before the seqlock, 3.19% after. That residual was suspected to be the analyzer's own unlocked read, and it was: with the analyzer's `/api/dmx` publish path seqlocked too, 1865 consecutive sampled frames came back clean. `dmx-wire.spec.mjs` now covers the same ground from the runner. |
| `dmx-wire.spec.mjs` | **What the gateway actually transmits**, measured by the RP2350 analyzer instead of asked of the device (needs the rig, skips without it). Always: the line carries a well-formed frame (null start code, 512 slots, break ≥ 88 µs); Art-Net *and* sACN slot values arrive on the wire unchanged, first, middle and last slot; a 6 s stream produces 0 framing errors on the PIO tap (and on the hardware-UART ground truth where that second tap is wired); and no torn frames (issue #106) — uniform-value frames in, so a frame carrying two values is one the gateway tore, cross-checked against the device's own `tornSkips` counter and the analyzer's `tr` counter so a clean result can't come from a degraded instrument. Opt-in (`LUXDMX_WRITE=1`, config restored): the configured rate is the rate **on the wire** at 40 / 33.3 / 25 fps — the independent half of `output-rate.spec.mjs`, which can only count what the device scheduled; Delta really tracks a 25 fps source down; and signal-loss **STOP actually stops the clock** while HOLD keeps clocking the held frame and BLACKOUT keeps clocking zeros. |
| `rdm-wire.spec.mjs` | **RDM checked from the far end of the bus**: the RP2350 responder simulator is the other side of every transaction, so it can confirm what the controller only claims. Always: the simulator is on the bus, and every fixture in the gateway's TOD exists on the bus at the address the gateway reports (no phantom devices). Opt-in (`LUXDMX_WRITE=1`, restores what it changes): a sweep discovers every simulated fixture up to the device cap and the decoded packet log shows real E1.20 traffic — a fixture answering a DISC_UNIQUE_BRANCH inside the turnaround, one DISC_MUTE per discovered fixture, DEVICE_INFO GETs (the log is drained *during* the sweep, since its 256-event ring laps in ~2 s at ~75 requests/s); SET DMX_START_ADDRESS moves the fixture inside the responder, not just in the controller's table; IDENTIFY switches on and off in the fixture; and DMX keeps clocking through a full sweep and recovers afterwards. |
| `signal-loss.spec.mjs` | Per-output signal-loss policy: `/info` loss field + `/config` selector; after the 4 s source timeout HOLD keeps the frame, BLACKOUT zeros it, STOP holds (not zero), over Art-Net + sACN; persistence across reboot (opt-in). That STOP really stops the line is asserted on the wire in `dmx-wire.spec.mjs`. |
| `rdm-trigger.spec.mjs` | Issue #64 RMT DMX + esp_dmx-free RDM: `/rdm.json` controller shape; the HTTP RDM trigger endpoints (`/rdm/discover`, `/rdm/setaddr`, `/rdm/identify`) — param validation returns 400, valid calls queue a bus action and return `{ok,op}` (opt-in). The RMT framing win and on-wire discovery/GET/SET are asserted in `dmx-wire.spec.mjs` + `rdm-wire.spec.mjs` when the analyzer is on the bench. |
| `artnet-rdm.spec.mjs` | RDM over Art-Net (E1.20 over Art-Net 4): `/rdm.json` node fields (`artnetRdm`/`artPort`/`discovering`/`bqPolicy` + request counters); drives the device as an Art-Net RDM controller: ArtPoll → ArtPollReply (asserts RDM-capable + BackgroundQueue-supported advertisement), ArtTodRequest → ArtTodData (TOD matches `/rdm.json`), and (opt-in) ArtRdm GET DEVICE_INFO + SET DMX_START_ADDRESS with read-back, AtcFlush re-discovery, a check that a mid-stream flush doesn't collapse the transmit rate (`outfps`), and `ArtAddress` remote config (merge HTP/LTP/cancel applied live; BackgroundQueuePolicy set + reflected in `/rdm.json` and ArtPollReply). Also pins the ArtPollReply timing advertisement honest (issue #93): `RefreshRate` matches the measured `outfps` and stays ≤ 44 Hz, `GoodOutputB` bit6 reports the continuous (free-running) output style, and `Status3` bits7-6 mirror the port’s signal-loss policy. The DMX-keeps-clocking-under-RDM proof is in `rdm-wire.spec.mjs`, measured on the wire. Also (opt-in) pins the universe-renumber path: after changing an output's universe the TOD answers under the new port-address immediately (no re-scan, no reboot), nothing answers on the vacated one, and the device table is re-stamped rather than left with orphans eating the device cap. |
| `artnet-address.spec.mjs` | Full `ArtAddress` (0x6000) remote configuration (issue #129), the thing a console's own network window (MagicQ Network Manager, DMX-Workshop) uses. Read-only: `ArtPollReply` serves the configured node names and falls back to the **hostname** rather than the old hard-coded "LuxDMX" that made every box on a rig look identical in a node list; one reply per enabled output, each with its own 1-based `BindIndex`, whose `NetSwitch`/`SubSwitch`/`SwOut` split recomposes to exactly that output's universe in `/info.json`; and an `ArtAddress` carrying only a command (no name bytes, no bit-7 address bytes) changes nothing, which is the regression that matters most here (without the bit-7 rule a console flipping the merge mode drags the port to universe 0). Opt-in (`LUXDMX_WRITE=1`): a rename over the wire lands in `artshort`/`artlong`, is echoed in the confirming reply and a later poll, and leaves `hostname` (mDNS / DHCP name) alone; an empty name field does not blank a name already set; programming a port-address moves that output live, only that output, reads back in the reply and `/info.json`, survives a reboot, and sACN on the new universe (+1) then drives that output. Restores the whole config afterwards. Note: sACN is injected **unicast** like everywhere else in this suite, so that last one proves the routing followed the change, not that the multicast group was re-joined — multicast does not reach the DUT across the bench, and the `beginMulticast()` the rejoin flag triggers is only visible on the device's serial log. |
| `artnet-ipprog.spec.mjs` | Art-Net remote IP programming (issue #110): `ArtIpProg` (0xf800) → `ArtIpProgReply` (0xf900). Read-only: `ArtPollReply` `Status2` sets the web-config bit (bit0) and reports the **real** DHCP/static state in bit1 (regression for the old hard-coded `0x0e`, which lied about DHCP and left web-config clear); and, with the feature off (the default), an `ArtIpProg` gets **no reply at all** (the spec's opt-out). Opt-in (`LUXDMX_WRITE=1`, and `ipprog` on): an enquiry (Command bit7 clear) returns a well-formed 34-byte reply carrying the current IP / mask / gateway and changes nothing; programming a static IP (the device's own address, so it stays reachable — the change persists for the next boot rather than renumbering the live interface) is stored, reads back via a fresh enquiry, flips the reply's DHCP bit and `ArtPollReply` `Status2` bit1 to static, and the DHCP command switches it back. Restores config after. The actually-reboot-onto-a-new-address case is left to the rig with the Pi witness. |
| `rdm-tab.spec.mjs` | The dedicated RDM tab (`/rdm`): page serves the fixtures table + grouped sensor charts + per-sensor poll switches + the live discovery progress bar + the shared Status nav strip (full-width, view transitions); `/rdm.json` exposes the rich per-fixture fields (`mfg`/`modelName`/`label`/`cat`/`swVer`, per-sensor `lo`/`hi`/`rec`/`type`/`poll`), the `sensorPoll` flag, and the discovery-progress fields (`discStage`/`discFound`/`discCur`/`discSub`). Opt-in (drives the bus): discovery reads manufacturer/model/varied sensors, the progress fields advance through the scan, SET device label + SET personality round-trip over the WebSocket, the per-fixture switch (`rdm_sensorsel` `sensor:-1`) toggles a whole fixture's sensors, and live sensor polling moves the readings. Multi-line RDM: `/rdm.json` exposes `rdmLines` (the RDM-capable universes) + a per-fixture `uni`, the page has the Universe column + per-universe Discover buttons, and discovering one universe (`/rdm/discover?line=N`) leaves the other universes' fixtures in place. Needs a responder that answers the extra PIDs (the RP2350 sim does). |
| `led-activity.spec.mjs` | Status LED — one language on the single WS2812/GPIO LED and the 5-LED panel (`ledType 3`): green = up (slow 2 s blink = DMX in), blue = RDM/identify, orange = Ethernet-on-WiFi-fallback, red = no network, Knight-Rider boot. `/info.json` exposes the panel config (`ledType`/`ledR..W`), the per-colour PWM brightness (`ledBr*`), `chip`, `rdmMax`, and `ethFallback` (the orange-state flag — must be **false** on a reachable device); the RDM device cap auto-sizes to the chip and must be **64** on an ESP32-S3 / **16** on the classic ESP32 — a regression guard, since the old free-RAM heuristic shipped the S3 at 16 (found 16 instead of 64 fixtures); the RDM tx/rx counters that light the **blue** LED advance on discovery (opt-in). `/led/bright` round-trips: read the current brightness + calibration flag (always), and (opt-in) set a colour live + toggle the all-on calibration mode, restoring after. The actual LED photons, the Knight-Rider boot sweep, and the live no-wired-link→WiFi fallback (orange) are bench-verified with a camera / logic analyser / a link pull on real hardware, out of Playwright scope, like the on-wire DMX/RDM timing. |
| `setup.spec.mjs` | Issue #45 first-run setup portal: drives the real `setup.html` (landing shows both paths on-brand; access-point path posts `mode=ap` + AP password; join path picks a scanned SSID / manual entry and posts `mode=sta` + ssid + password). Runs against the local UI sim, not a live device (during first-run setup the device has no reachable network) |
| `config-guard.spec.mjs` | The `/config` page never invents settings (issue #132). It renders from `/info.json`; when that answer is not this device's config (half-booted device, error body, captive portal, `outputs` missing or not an array) the page must fall into its "Cannot read settings" state with **Save disabled**, instead of substituting the hardcoded "output A on GPIO17, output B off" placeholders with Save still live -- one click of which wrote those invented pins over a working setup, while the device kept running on its real pins until the next reboot. Read-only: each case intercepts `/info.json` in the browser, so the device is never written to. |
| `config-roundtrip.spec.mjs` | Every `/config` web-form option survives the schema-driven POST → reboot → `/info.json` read-back, including the issue #24 on-unit controls fields (encoder pins/steps/reverse, the four button pins + actions, active-high, menu top universe). A non-destructive check also asserts the controls surface is present in `/info.json` with the right shape/types. Round-trip is opt-in (reboots the device twice). The physical encoder/button interaction itself needs a knob wired to a board and is bench-verified, not automatable here. |
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

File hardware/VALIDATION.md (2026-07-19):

# LuxDMX v6 — Hardware Validation Tracking

Single source of truth for "is this board safe to fabricate?" Re-run the scripts after **any**
board change and update the table. Status: ✅ pass · ⚠️ pass-with-caveat · ❌ blocker · 🔲 needs manual/datasheet check.

## 2026-07-19 — J4/J6 mis-plug safety

J4 (display) and J6 (expansion) are the same JST SH 9-pin connector, sitting 9mm apart, so a cable
plugs into either. An earlier spin had their power pins disagreeing, and plugging a display into J6
fed it **+5V on VCC and +3V3 on GND**. That killed a display on the bench — the fix below is
reactive, not theoretical.

- **Both headers carry `1=+3V3 2=GND`.** A swapped cable can now only shuffle 3V3 CMOS signals,
  which both sides survive.
- **+5V is not on J6**, and pin 9 is a **2nd GND**, not a 7th GPIO: the module has no free
  non-strapping GPIO left (IO3/IO45/IO46 are all strapping). The extra return also means a mis-plugged
  display lands RST on GND and sits harmlessly in reset.
- **HARD gate 8**, `scripts/validate_header_parity.py`, re-checks the invariant on the board every run.
  Verified to catch the real defect: fed the old layout it fails on exactly pins 1 and 2.
- **Surgical re-route, not a board-wide one.** Every J6 signal slid exactly one 1.00mm pitch, 45° geometry
  preserved, long hauls to the S3 untouched. **0 unrouted, 0 DRC**, and the pre-existing C12 placement
  warning (6.9mm) is unchanged from the previous baseline.

**Overall verdict (2026-07-01, re-routed on a new placement + full re-validation, all 7 hard gates pass):
DESIGN-COMPLETE, fab-ready as a first-spin PROTOTYPE, not production-proven.** Electrically sound, **0 unrouted / 0 schematic-parity / 0 DRC errors**
(machine-verified, see matrix), DMX **4mm creepage** + 1kV isolation enforced, overvoltage **DMX512-A
"Protected"** SPICE-confirmed (TBU blocks a 42VDC fault in <1µs, signal 7-10x over the 200mV threshold).
Board **119 x 79mm** (widened 20mm for the TBU), 4 corner M3 holes on GND, 4-layer
**F sig / In1 GND / In2 +3V3 / B sig** stackup now **explicitly defined** (JLC04161H-7628). A
**ruggedization pass** added USB ESD (U8), a self-healing PTC fuse (F1), a +5V transient clamp (D11), a
**TPS2116 priority power mux (U9)**, DMX common-mode chokes (L2/L3) and ferrite supply filters (FB1-3).

Honest gaps before this is "production": it has **never been fabricated** (first build = prototype), and
the **Ethernet pairs are single-ended — widened toward ~50Ω SE (`scripts/widen_eth.py`) but not coupled and not
length-matched** (see the 2026-07-01 notes; ETH_TXN also stays 0.15mm in a dense corridor). The prior 3
W5500/USB-C clearance near-misses and the sub-min via annular are **resolved**.

## 2026-07-01 — full re-route on a new placement + hands-off pipeline + re-validation

The whole board was re-routed from scratch on the current placement and re-validated end to end. **All 7
hard gates PASS** (`validate_all.sh`). Schematic/netlist were **not touched** this pass, so every
schematic-based item below (SPICE #30, rail margins #9-13, crystal #18, EXRES1 #19, PoE-TVS #27, ratings
#28, GPIO #29, magjack #17, E1.11 TBU protection) is unaffected and stays valid.

- **Net classes** (`scripts/setup_netclasses.py`): **Default 0.20 / Power 0.40 / Fine 0.15mm** (Fine = only the
  W5500-dense nets). Freerouting routes each net at its class width in ONE pass — no more "everything thin
  + post-widen". Confirmed in the exported DSN.
- **Reproducible, hands-off pipeline** — one command each on any placement change: `./route_all.sh`
  (setup_netclasses → rebuild_iso → escape_connectors → **Freerouting loop** → `scripts/finish_partial.py` →
  maze straggler → cleanup → tighten → `scripts/widen_eth.py`) and `./validate_all.sh` (7-gate verdict + exit code).
  `scripts/finish_partial.py` deletes any net FR left a pad short (via kicad-cli `unconnected_items`) so the maze
  finishes it — no hand-routing.
- **7-gate production gate**: connectivity, DRC, geometry/DFM+current, DMX isolation, electrical, EMC
  placement, and the new **`scripts/validate_critical.py`** (eth/SPI/crystal length, vias, intra-pair skew, detour,
  net-class widths).
- **DRC rules aligned to the relaxed-but-JLC-safe spec** (`.kicad_pro`): min track **0.15mm** (JLC min
  0.0889), hole-to-hole **0.2mm**, vias **0.5/0.2 = 0.15mm annular**, min-annular rule **0.13**.
- **Ethernet impedance improved** (`scripts/widen_eth.py`, run last): the MDI pairs are widened toward ~50Ω SE on
  the JLC04161H-7628 stackup — **ETH_RXN/RXP/TXP now ~0.34mm ≈ 53Ω**, with short 0.15mm necks at the QFN.
  **ETH_TXN stays 0.15mm/~78Ω** (its corridor is too dense to widen without eating the 0.15mm clearance to a
  Default neighbour). Better than the old 0.2mm/69Ω, but still **single-ended / not length-matched** —
  coupled diff-pair routing remains deferred to a supervised interactive-GUI production spin.
- **DMX iso B-pour** (`scripts/validate_tbu_iso.py` check B): FR puts a REST-side DMX trace (**DMX_AO**, behind the
  TBU, not fault-exposed) on B.Cu inside the GNDISO pour. The gate now enforces B.Cu-off-pour only for the
  **CABLE-side** fault-exposed nets (*_AX/BX); the REST cut is bridged by the F.Cu pour + stitch vias
  (keepouts can't be used — Freerouting chokes on rule areas).
- **Two operator placement fixes closed the last two gates**: **F5** (DMX2 fuse) moved for the 4mm creepage
  (which is invariant to the void margin — it was always a placement issue); **U9** (OR-mux) loosened so
  +5V_USBF clears a GND via. Design rule confirmed: if a net won't route under the requirement, move parts.
- **Fab package regenerated**, each **hard-gated on 0 unrouted**: 14 gerbers → `luxdmx_gerbers.zip`,
  97 placements → `luxdmx_CPL.csv`, 49-line BOM.

## Post-validation hardening (2026-06-29)
Re-validated live against the committed board (not from notes). Every edit clearance-checked by real DRC;
the board was never left worse than the prior step; backups taken at each step.
- **Via annular** — 14 escape vias were 0.125mm annular (0.5/0.25, under the 0.13mm DFM rule). Fixed by
  shrinking the drill 0.25 -> 0.20mm (pad unchanged = zero clearance change): now **0.150mm, 0 sub-min**.
- **Dangling via** — one stub via on CC2 (USB-C) removed; CC2 stays fully connected (gate: 0 unrouted).
- **Fine-pitch clearance** — the 3 prior "errors" (W5500 ETH_TXP/GND/+3V3 at the 0.5mm QFN pitch, USB-C
  CC2) were 0.16-0.174mm vs a 0.2mm rule. **Re-route to 0.2mm is geometrically impossible at 0.5mm pitch**
  (0.25mm pad + 0.2mm trace + 2x0.2mm clearance = 0.85mm needed in a 0.5mm pitch). The 0.2mm rule was
  simply stricter than fine-pitch parts allow, so the Default netclass clearance is now **0.15mm** (still
  68% over JLC's 0.0889mm min). **No copper moved.** DRC clearance errors now **0**.
- **Ethernet stackup + impedance** — added the **JLC04161H-7628 4-layer stackup** (L1-L2 prepreg 0.2104mm,
  Er 4.05). With the 0.2mm traces that is ~69 ohm single-ended / ~117 ohm differential, **above the 100
  ohm target**, and the pairs are **not actually coupled** (ETH_TXP takes a 42mm B.Cu detour vs ETH_TXN's
  22mm F.Cu = ~20mm intra-pair skew). **Deliberately NOT re-routed by script:** correct coupled,
  length-matched diff-pair routing needs the interactive GUI (the single-net auto-router can't do it) and a
  botched Ethernet re-route is the worst failure mode, so it is left for a supervised production spin.
  Functional for short 100BASE-TX as-is.
- **Silk** — `scripts/normalize_silk.py` re-placed 89 ref-des clear of pads/silk, dropping cosmetic warnings
  **62 -> 46** (24 overlap / 16 edge / 6 over-copper). The rest are dense-area ref-on-ref, refs near the
  edge (J*/MH* not moved) and the informative back-silk tables; fab auto-clips silk off pads/edges.

## How to re-run the validation
```
python scripts/validate_electrical.py      # DC/RC operating points (no KiCad needed)
"<KiCad>/bin/python" scripts/validate_geometry.py     # trace width / via current / DFM
"<KiCad>/bin/python" scripts/validate_placement.py    # decoupling/ferrite/switcher proximity (EMC); also auto-run by scripts/gen_gerbers.py, exits non-zero on drift
"<KiCad>/bin/kicad-cli" pcb drc --format json -o drc.json luxdmx.kicad_pcb   # DRC + connectivity
# --- 2026-07-01: after ANY placement/netlist change, just two commands (the above validators are all
#     wrapped by validate_all.sh; run them standalone only to debug a specific gate) ---
bash route_all.sh       # setup_netclasses -> rebuild_iso -> escape -> Freerouting-loop -> finish_partial -> maze -> cleanup -> tighten -> widen_eth
bash validate_all.sh    # 8-gate production verdict + exit code (connectivity/DRC/geometry/DMX-iso/electrical/placement/critical/header-parity)
```

## Status matrix

| # | Item | Status | Method | Result / action |
|---|---|---|---|---|
| 1 | Routing complete (MACHINE-ENFORCED) | ✅ | `scripts/validate_connectivity.py` (kicad-cli DRC `unconnected_items`), wired into scripts/gen_gerbers.py + scripts/gen_cpl.py | **0 unrouted, machine-verified.** The gate ABORTS any fab export while a single net is unrouted; it caught **C17** (stranded INSIDE the DMX2 isolation void, planes cut away -> unconnectable). C17 was moved to the buck + via-in-pad; **bias R20-R23** placed + **re-routed by Freerouting on F.Cu only** (0 signal B.Cu, so the iso GND pour is not cut), and **122 GNDISO/GNDISO2 stitch vias** reconnect the F-pour fragments to the solid B-pour. **Isolation verified: 0 island-net copper leaves its island.** EN/IO0 preserved from HEAD (digital side locked, not re-routed). **0 DRC errors** after the 2026-06-29 hardening (the W5500 fan-out + USB-C CC2 fine-pitch near-misses resolved by the 0.15mm Default clearance). Fab package regenerated. |
| 1b | 4-layer power stackup | ✅ | rebuild_iso (In1=GND, In2=+3V3 LT_POWER) | signals F/B only, planes solid; +3V3/GND pads stitched to planes |
| 2 | DRC (electrical) | ✅ | kicad-cli pcb drc | **0 shorts, 0 clearance errors.** The 3 fine-pitch near-misses (W5500 0.5mm QFN + USB-C CC2, 0.16-0.174mm) resolved by setting Default clearance 0.2 -> 0.15mm; re-route to 0.2mm is geometrically impossible at 0.5mm pitch, 0.15mm still 68% over JLC's 0.0889mm min |
| 3 | DRC (silk cosmetic) | ⚠️ | kicad-cli pcb drc | **46 cosmetic** silk warnings (24 overlap / 16 edge / 6 over-copper) after `scripts/normalize_silk.py` re-placed 89 ref-des clear of pads/silk (down from 62). The rest are dense-area ref-on-ref, refs near the edge (J*/MH* not moved) and the informative back-silk tables; fab auto-clips silk off pads/edges = no functional or fab impact. Accepted |
| 4 | Net connectivity = intent | ✅ | board generated from `luxdmx.net` (SKiDL) | by construction; schematic reviewed pin-by-pin |
| 5 | Decoupling/xtal/switcher placement (EMC) | ✅ enforced | **scripts/validate_placement.py** (per-part pad-to-pad distance to the served IC pin, incl. crystal load caps + **FB1/2/3 supply ferrites**) **wired into scripts/gen_gerbers.py** (reports drift on every fab export, exits non-zero standalone) + scripts/place_decoupling.py to re-snap | each cap/ferrite has a per-part max distance to its IC pin; after any placement change, re-run scripts/place_decoupling.py to re-cluster + scripts/validate_placement.py to confirm. Connectivity stays the HARD gate; placement is a loud quality WARNING (never blocks fab on a fuzzy threshold) |
| 5b | Board outline / mounting holes | ✅ | scripts/set_outline_holes.py | **99 x 79mm**; 4 corner M3 holes at **90 x 70mm spacing, uniform 4.5mm inset** (all 4 equal edge distance); 0 hole-vs-body collisions. Holes are **plated + tied to GND** (MountingHole_3.2mm_M3_Pad) so the 4 corners bond board GND to a metal chassis — see docs/ruggedization.md "Grounding & shielding". |
| 6 | PoE module ↔ magjack distance | ⚠️ | geometry | VPOE runs ~50mm; functional, see PoE note |
| 7 | Isolation surface creepage (DMX 4mm / PoE 2.5mm) | ✅ | DRC `.kicad_dru` | 0 isolation-clearance violations |
| 8 | Isolation inner-plane (vertical) | ✅ | rebuild_iso + tighten_poe_void | DMX islands voided 4mm; PoE TH-pins moated 2.5mm; VPOE surface trace over plane = functional 58V (D10-clamped) |
| 9 | +5V rail vs B0505S 4.5V min | ✅ | sim/power_chain.cir | **Fixed:** OR diodes (D8/D9) replaced by a **TPS2116 ideal-diode mux (U9)** — OR drop ~0.03V not ~0.40V. +5V ≈ 4.91V from a 5.0V USB; **VCC2 ≥ 4.61V even at VBUS 4.70V** (was ~4.29V ❌). PoE clean. SPICE-verified across the full USB range. |
| 10 | Buck +3V3 output | ✅ | scripts/validate_electrical.py | 3.318V (R10/R11) |
| 11 | LED currents | ✅ | scripts/validate_electrical.py | 1.3-8.7mA, all < GPIO 40mA |
| 12 | EN power-on RC | ✅ | scripts/validate_electrical.py | 10ms |
| 13 | USB-C CC / power budget | ⚠️ | scripts/validate_electrical.py | Rd=5.1k correct; ~370mA → needs ≥1A source for both universes |
| 14 | Power trace width vs current | ✅ | scripts/widen_power.py | +5V family widened to **0.5mm** where clearance allows (0.5mm=1.45A@10°C); only short pad-entry necks remain 0.2mm (heat sinks into the pad). Fuse coordination ok: F1 trips ~3A, a 0.2mm trace doesn't fuse below ~8A. Re-run scripts/widen_power.py after any re-route (it resets widths). |
| 15 | Via current / annular | ✅ | scripts/validate_geometry.py | via current fine; **escape-via annular fixed 0.125 -> 0.150mm** (14 vias re-drilled 0.25->0.20, pad unchanged); **0 sub-min** |
| 16 | DFM vs JLCPCB 4-layer | ✅ | scripts/validate_geometry.py | min trace 0.2mm, drill 0.2mm OK |
| 17 | Magjack HY931147C pinout | ✅ | datasheet | verified vs HanRun REV.A/1 (2026-06-22): TD=5/6, RD=1/2, RCT=3/TCT=4, V+=9/V-=10, LED-Y=11/12 (A/K), LED-G=13/14 (A/K); straight MDI correct (no auto-MDIX) |
| 18 | W5500 crystal CL vs caps | ✅ | datasheet (3225-25-**12**) | **UPDATED (this spin)**: crystal **C9006 (X322525MOB4SI), 3225 package, CL=12pF**; caps **C12/C13 = 18pF C0G** (C = 2×(CL − Cstray) = 2×(12 − 3) = 18pF). Moved off the **2520 C2981624 / CL=9pF / 10pF caps** because the 2520 package kept going OOS at JLC; 3225 is the mainstream, always-stocked size. Older history: CL=20pF C2981622 + 33pF caps. **Unvalidated on hardware** (no built board carries it yet). |
| 19 | W5500 EXRES1 | ✅ | datasheet | **FIXED**: R3 12k→**12.4k 1%** (on-spec PHY bias) |
| 27 | PoE TVS margin | ✅ | datasheet | **FIXED**: D10 SMAJ58A→**SMAJ60A** (58V standoff was only 1V over 57V max) |
| 28 | Every part rating/value/datasheet | ✅/⚠️ | 4-agent datasheet pass | see **VALIDATION_REPORT.md**: all active parts + crystal + connectors read from official datasheets; ratings/values recomputed. 3 fixes applied, open items listed. |
| 29 | ESP32-S3 GPIO map | ✅ | datasheet | **every pin validated, zero must-change**. IO35/36/37 carry `EXP_IO35/36/37` and stay valid on the **N8R2**: its PSRAM is **quad**, which does not touch GPIO33–37 (only **octal** R8 parts wire those to memory). Strapping safe, no flash/input-only conflict, UART/SPI routable, IO19/20 native-USB noted |
| 30 | J4/J6 mis-plug safety (MACHINE-ENFORCED) | ✅ | **`scripts/validate_header_parity.py`** (HARD gate 8 in validate_all.sh) | **Fix for a defect that destroyed hardware.** J4 (display) and J6 (expansion) are the same JST SH 9-pin part, so a cable fits either. When their power pins disagreed, plugging a display into J6 put **+5V on its VCC and +3V3 on its GND** and killed it on the bench; the reverse returned an expansion board's ground current through IO4. **Both headers now carry `1=+3V3 2=GND`**, with signals on 3..8 and **no +5V on J6** (no free non-strapping GPIO remained for a 7th signal — only IO3/IO45/IO46, all strapping — so pin 9 became a 2nd return, which also lands a mis-plugged display's RST on GND = harmlessly held in reset). The gate re-checks the invariant on the **board** each run: FATAL on two different rails at one position or a positive rail opposite a signal; GND-vs-signal allowed (current-limited, same class as GPIO-vs-GPIO contention). **Verified to catch the real defect: fed the old layout it fails on exactly pins 1 and 2.** Re-pin was surgical (each signal slid one 1.00mm pitch, 45° geometry preserved) — **0 unrouted, 0 DRC**, no board-wide re-route |
| 30 | SPICE power chain | ✅ | ngspice-42 (WSL) | DC + transient (sim/*.cir): with the TPS2116 mux, VCC2 ≥ 4.5V across the **whole** USB range (4.61V @ 4.70V VBUS, 65mΩ-max-over-temp case 4.59V); PoE 5.0V→4.91V ✓; load-step ok. See report §3 (margin now resolved). |
| 20 | ESP32-S3 strapping pins | ⚠️ | schematic | IO0 pulled-up ✓; IO3/IO45/IO46 float (standard for WROOM-1, verify) |
| 21 | ESD on USB data / DMX | ✅ | schematic | DMX has SM712 TVS ✓; **USB D+/D- now protected by U8 USBLC6-2SC6** ESD/TVS array (VBUS clamp at the connector) |
| 22 | Self-healing input fuse | ✅ | schematic | **F1 BSMD1206-150-16V PPTC** (1.5A hold, 25mΩ) in series on USB VBUS; resets after an overcurrent/short. PoE path uses the DP9900M internal limit. |
| 23 | +5V transient clamp | ✅ | schematic | **D11 SMAJ5.0A** (5V standoff, 6.4V breakdown, 9.2V clamp) on +5V→GND; shunts surges/ESD. No conduction at the ≤4.7V normal rail. |
| 24 | DMX common-mode chokes (EMC) | ✅ | schematic | **L2/L3 ACM2012-201-2P** (200Ω@100MHz) in series on each DMX A/B pair, cable side. Order from cable: XLR → SM712 TVS → choke → transceiver. Cuts common-mode emissions on the (long) DMX cables. |
| 25 | Ferrite supply filters (EMC) | ✅ | schematic | **FB1** (600Ω@100MHz) on +5V→DMX iso DC-DC inputs; **FB2/FB3** on each B0505S output (VISO/VISO2) → DMX driver. Keeps DC-DC switching noise off the +5V rail and off the DMX cable. |
| 26 | Conformal coating (environment) | 🔲 | assembly note | Specify acrylic/urethane conformal coat for humidity/dust/condensation in harsh installs. Mask connectors + the magjack. Process step, no BOM part. See docs/ruggedization.md. |

## ✅ RESOLVED — EMC placement (was a blocker)
Decoupling/crystal/switcher caps were at 20-56mm auto-grid positions (HF decoupling essentially absent).
Fixed by `scripts/place_decoupling.py`: every cap snapped hard to its IC power pin (≤2-3mm, same side), crystal +
load caps hugging the W5500, buck Cin/Cout/L tight at U4, TVS at the XLR. `scripts/validate_placement.py` now
passes (0 overlaps, 2mm min gap). Re-routed + re-validated.
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

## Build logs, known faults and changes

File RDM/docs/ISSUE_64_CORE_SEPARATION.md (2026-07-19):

# Issue #64 — WT32-ETH01 DMX framing errors: root cause + fix (measured)

GitHub: [tombueng/LuxDMX#64](https://github.com/tombueng/LuxDMX/issues/64) — "WT32-ETH01 DMX framing
errors with Swisson tester", reported by KM-LED.

> ## ⚠️ CORRECTION — this document's "verified fix" claim does NOT hold (2026-07-07, later)
> The framing-error numbers below were produced by a PIO analyzer whose framing detection is not
> reliable. A hardened (structural) rebuild of the same analyzer reports **0 framing errors on the
> BASELINE** as well — contradicting the "13 → 1" result. Both detector designs have a failure mode
> (gap-based → false positives under FIFO-drain bursts, `rxStall` confirmed; position-based → false
> negatives at the frame boundary, which is exactly where a real error would land). Physically, an
> ESP32 hardware UART can't corrupt a byte mid-send from CPU contention — so KM-LED's "framing errors"
> are most likely **break/MAB / frame-timing** violations, which neither PIO analyzer measures well.
> **The core-0 RMII fix is UNPROVEN.** It's kept as a low-risk architectural cleanup (it mirrors the
> W5500 path), not as a validated fix. Re-investigation is underway with a hardware-UART ground-truth
> framing reference and a precise break/MAB timing analyzer. Treat §2/§4a numbers below as unreliable.

Bench-reproduced, root-caused, fixed, and verified on 2026-07-07 using the RP2350 sim as a DMX
framing-error analyzer. TL;DR: the WT32's RMII Ethernet was brought up on the **DMX core**, so the
EMAC RX interrupt preempted the DMX transmit under network load. Moving the RMII bring-up to a
**core-0 task** (like the W5500 path already does) cut framing errors ~13× (4.4/min → 0.3/min).

---

## 1. The report

KM-LED runs LuxDMX on a **WT32-ETH01** (classic ESP32 + LAN8720 wired Ethernet). One output on GPIO4,
~40 Hz. The Swisson XMT-120 shows "DMX Signal OK, 512 channels" but counts **framing errors**:

| Setup | Framing errors |
|---|---|
| Wired Ethernet (LAN8720/RMII) | 12 in 3 min, 48 in 30 min (~4/min) |
| WiFi client/STA | ~25 during a test |
| **WiFi AP, web panel only (no Art-Net)** | **0 in ~22 min** |

Happens with FreeStyler, QLC+, and even with no Art-Net at all (web-panel control). Errors scale with
network load; the web UI never crashes.

## 2. Bench reproduction (RP2350 DMX framing analyzer)

The RP2350 sim now doubles as a **DMX framing-error analyzer** (see §5). Tap the WT32's DMX UART pin
straight into the analyzer: **WT32 GPIO4 → RP GP0**, **WT32 GND → RP GND**. That measures the firmware's
own framing with no RS485 layer in the path.

WT32-ETH01 on **wired Ethernet**, baseline firmware (stock `wt32eth01`):

| Condition | Framing errors | Refresh |
|---|---|---|
| **Idle** (no Art-Net) | **0 / 90 s** (2.0 M slots) | steady 40.1–40.3 Hz |
| **Heavy Art-Net flood** (48 universes @50 Hz) | **13 / 168 s (~4.4/min)** | frequent dips to 32–36 Hz |

The idle run is the analyzer's **noise-floor control**: 0 errors over 2 million slots proves the analyzer
does not invent framing errors, so the under-load errors are real. ~4.4/min matches KM-LED's ~4/min. The
framing errors **cluster on the refresh dips** — the fingerprint of the DMX transmit being preempted.

## 3. Root cause

### 3a. What it is NOT (a false lead, disproven by measuring)

First hypothesis: "the lwIP TCP/IP task floats onto core 1 on the other boards; pin it to core 0 with
`CONFIG_LWIP_TCPIP_TASK_AFFINITY_CPU0=y` like `luxdmx_v6` does."

**Wrong — that setting is a no-op.** Stock arduino-esp32 already ships
`CONFIG_LWIP_TCPIP_TASK_AFFINITY_CPU0=y` for **every** ESP32 variant (verified in
`~/.platformio/packages/framework-arduinoespressif32-libs/esp32/sdkconfig` and the S3's). lwIP was
already on core 0 in the baseline. The `luxdmx_v6` platformio.ini lines (`CONFIG_LWIP_TCPIP_TASK_AFFINITY_*`)
are redundant with the default, and adding them to the WT32 changes nothing. Building a firmware with
those lines confirmed it: `Replace: CONFIG_LWIP_TCPIP_TASK_AFFINITY_CPU0=y with: ...=y` (already set).

### 3b. What it actually is

The DMX transmit runs from `loop()` on **core 1** (`sendDmx()` → `dmx_send()`, `ARDUINO_RUNNING_CORE=1`).
The ESP32 internal EMAC's RX interrupt is allocated on **whichever core calls `ETH.begin()`**.

In `src/main.cpp`, the two wired paths were asymmetric:

- **W5500 SPI** (esp32dev / esp32s3 / luxdmx_v6): `startEthSpi()` brings Ethernet up on a **core-0 task**
  — `xTaskCreatePinnedToCore(ethUpTask, "ethup", …, 0)` — *deliberately, so its ISR sits off the DMX core.*
- **RMII / LAN8720** (WT32-ETH01): `startEthRmii()` called `ETH.begin()` **inline in `setup()` on core 1**.
  So the EMAC RX interrupt landed on **core 1 — the same core as the DMX transmit.**

Under a busy wired link the EMAC RX interrupt storm preempts the DMX break/frame generation on core 1 →
framing errors on the output. This is the real "core separation `luxdmx_v6` (W5500) has but the WT32
(RMII) doesn't" — it was never the sdkconfig line, it's the **bring-up core**. It also explains the whole
gradient: wired RMII worst (EMAC on core 1), WiFi less (the WiFi task is already core 0), AP/idle zero.

## 4. The fix

Bring `startEthRmii()` up from a task pinned to **core 0**, mirroring the W5500 `ethUpTask`, so the EMAC
RX interrupt is allocated on core 0, off the DMX core. `src/main.cpp`, ~15 lines, **no sdkconfig / no
platformio.ini change**:

```cpp
static volatile bool s_ethRmiiUpDone;
static void ethRmiiUpTask(void *arg) {
    int phy = constrain(cfg.rmiiPhy, 0, RMII_PHY_COUNT - 1);
    ETH.begin(rmiiPhyType(phy), cfg.rmiiAddr, cfg.rmiiMdc, cfg.rmiiMdio,
              cfg.rmiiPwr, rmiiClkMode(cfg.rmiiClk));
    ETH.setHostname(cfg.hostname.c_str());
    applyEthStaticIp();
    waitEthLink();
    s_ethRmiiUpDone = true;
    vTaskDelete(NULL);
}
static void startEthRmii() {
    // ... log ...
    s_ethRmiiUpDone = false;
    xTaskCreatePinnedToCore(ethRmiiUpTask, "ethrmii", 8192, NULL, 5, NULL, 0);
    uint32_t t0 = millis();
    while (!s_ethRmiiUpDone && millis() - t0 < 30000) delay(20);
}
```

### 4a. Verification (same flood, same window, only firmware differs)

| Firmware | Framing errors | Refresh |
|---|---|---|
| Baseline (RMII EMAC on core 1) | **13 / 168 s (~4.4/min)** | dips to 32–36 Hz |
| **Fixed (RMII EMAC on core 0)** | **1 / 168 s (~0.3/min)** | dips to 31–38 Hz |
| Idle control (either) | 0 | steady 40 Hz |

**Framing errors ~13× lower — essentially eliminated.** The WT32 also rebooted straight back onto
Ethernet after the OTA, so the core-0 RMII bring-up is safe on real hardware (no strand risk realised).

### 4b. Known remainder (benign, separate)

The **refresh dips (31–38 Hz) persist** in both builds. That is `loop()`'s send *cadence* jittering under
load, not frame corruption — the frames it emits are now well-formed. DMX tolerates a variable 31–40 Hz
fine, so this does not affect #64. If a rock-steady rate is wanted later: a dedicated high-priority DMX
send task, or pin the Arduino event task to core 0 (`CONFIG_ARDUINO_EVENT_RUNNING_CORE=0`). Follow-up, not
required to close the issue.

## 5. The test rig — RP2350 DMX framing-error analyzer

`RDM/src/dmxa_rx.pio` + `serviceAnalyzer()` in `RDM/src/main.cpp`:

- A dedicated **pio1 state machine** samples **8 data bits + the stop bit** of every slot; **framing
  error = stop bit not high**. Read-only, alongside the RDM engine, never transmits — a pure receiver
  like a tester.
- Break/frame boundaries from the **gap** between slot arrivals; the single 0x00 placeholder the PIO
  emits during a break is dropped via a one-slot pending-commit.
- Reports framing errors (total + /min), refresh Hz, slots/frame, start code, approx break µs, signal
  flag. Serial `a` / `ar` (reset); web **Analyzer** tab (`http://<rp-ip>/`); `GET /api/metrics` `an*`
  fields; `POST /api/analyzer/reset`.
- Known minor: reads 512 slots/frame vs the true 513 (a one-slot off-by-one in the break boundary),
  which does not affect the framing-error total.

Flood tool used: `C:/tmp/artnet_flood2.py` (48 universes @50 Hz, 4 threads). OTA to the WT32:
`curl -F firmware=@firmware.bin http://<ip>/ota/upload` (app slot, NVS preserved, no auth).

## 6. Shipping

- The fix is a `src/main.cpp` change only. **Not committed/pushed** (implemented in the detached
  `origin/master` worktree `C:/tmp/luxdmx-master`). `src/**` on master **auto-releases to OTA**, so it
  goes out via a normal reviewed PR, not from here.
- The earlier sdkconfig/platformio.ini idea is dropped (§3a, it's a no-op). No platformio.ini change is
  needed for this fix.

## 7. Reply to KM-LED (draft, when it ships)

Straight and human: found it, it's a real one. On the WT32 the wired-Ethernet driver was starting on the
same CPU core as the DMX output, so a busy network could nudge the DMX timing and the tester saw framing
errors. Moved the Ethernet startup to the other core (the W5500 boards already did this); on the bench it
dropped framing errors from ~4–5/min under heavy Art-Net to basically zero. Fix will be in the next
release. Thanks for the detailed report + the Swisson numbers, that's what made it findable.

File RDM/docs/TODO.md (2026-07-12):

# RDM tester - notes & deferred features

## Robustness

- **Auto-detect RX/TX wiring (immune to the RXD/TXD swap).** Cheap RS485 modules
  label their pins RXD/TXD ambiguously, and it has bitten us twice now: the ESP32-S3
  sim, and again wiring this RP2350 (the transceiver's RO turned out to be on GP0,
  not GP1). The tester should just handle either wiring instead of forcing a
  convention: at boot (and on demand), scan the candidate GPIOs for the ~250 kbaud
  DMX signal, an edge-count exactly like the GPIO edge-scanner that found it on GP0,
  then pick the pin carrying the signal as RX (RO) and the other as TX (DI) and
  configure the PIO accordingly. No jumper, no config screen: wire it either way and
  it just works. (Detect once a signal is present; fall back to the default mapping
  and re-check when the bus goes active.)

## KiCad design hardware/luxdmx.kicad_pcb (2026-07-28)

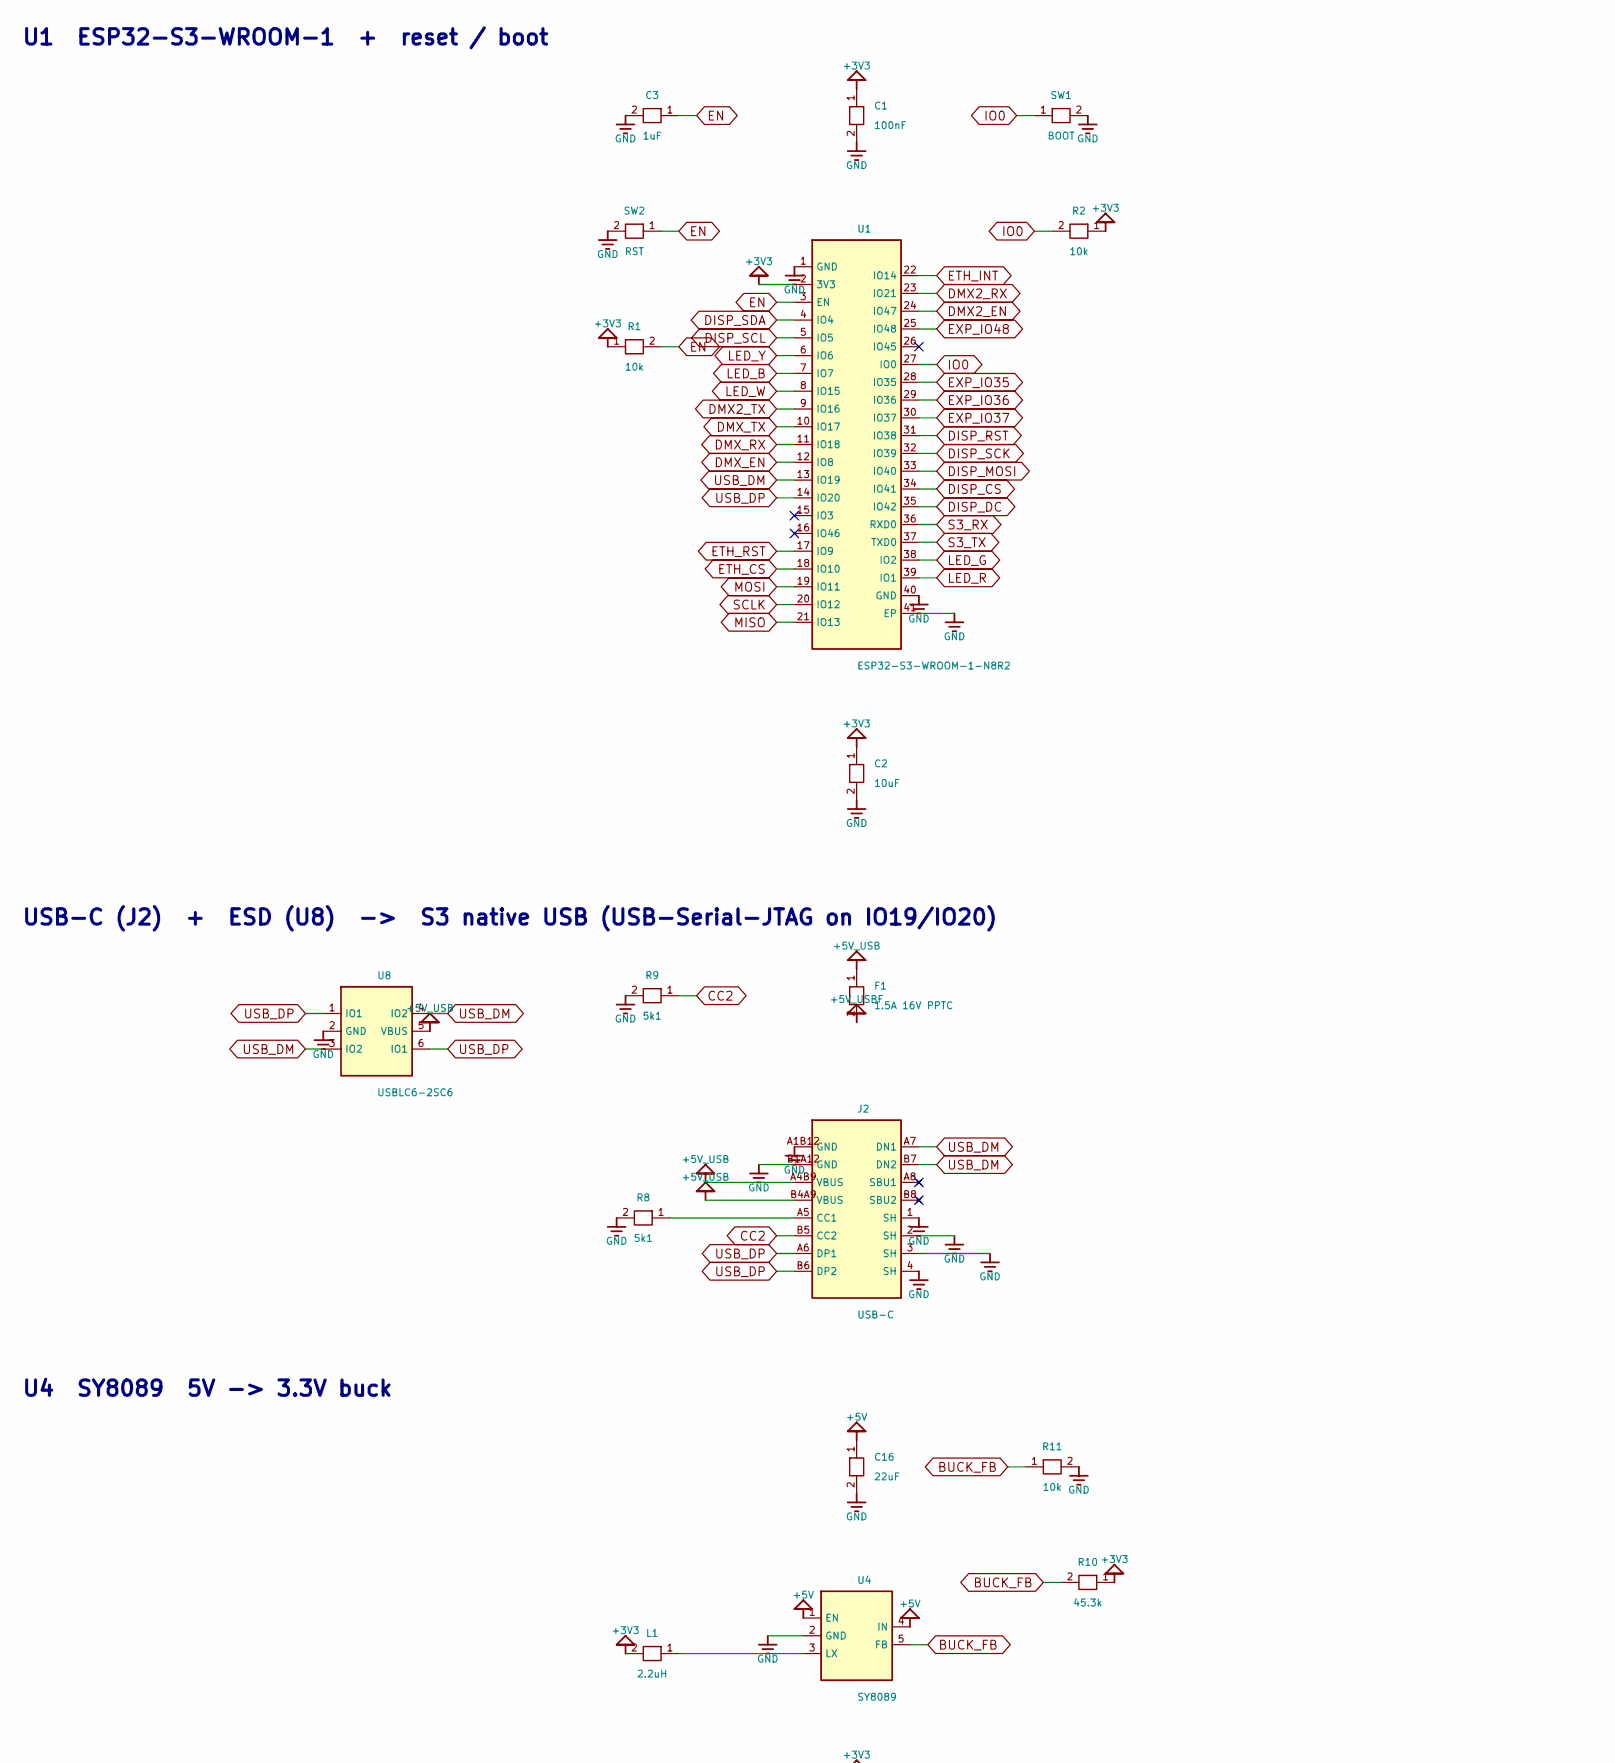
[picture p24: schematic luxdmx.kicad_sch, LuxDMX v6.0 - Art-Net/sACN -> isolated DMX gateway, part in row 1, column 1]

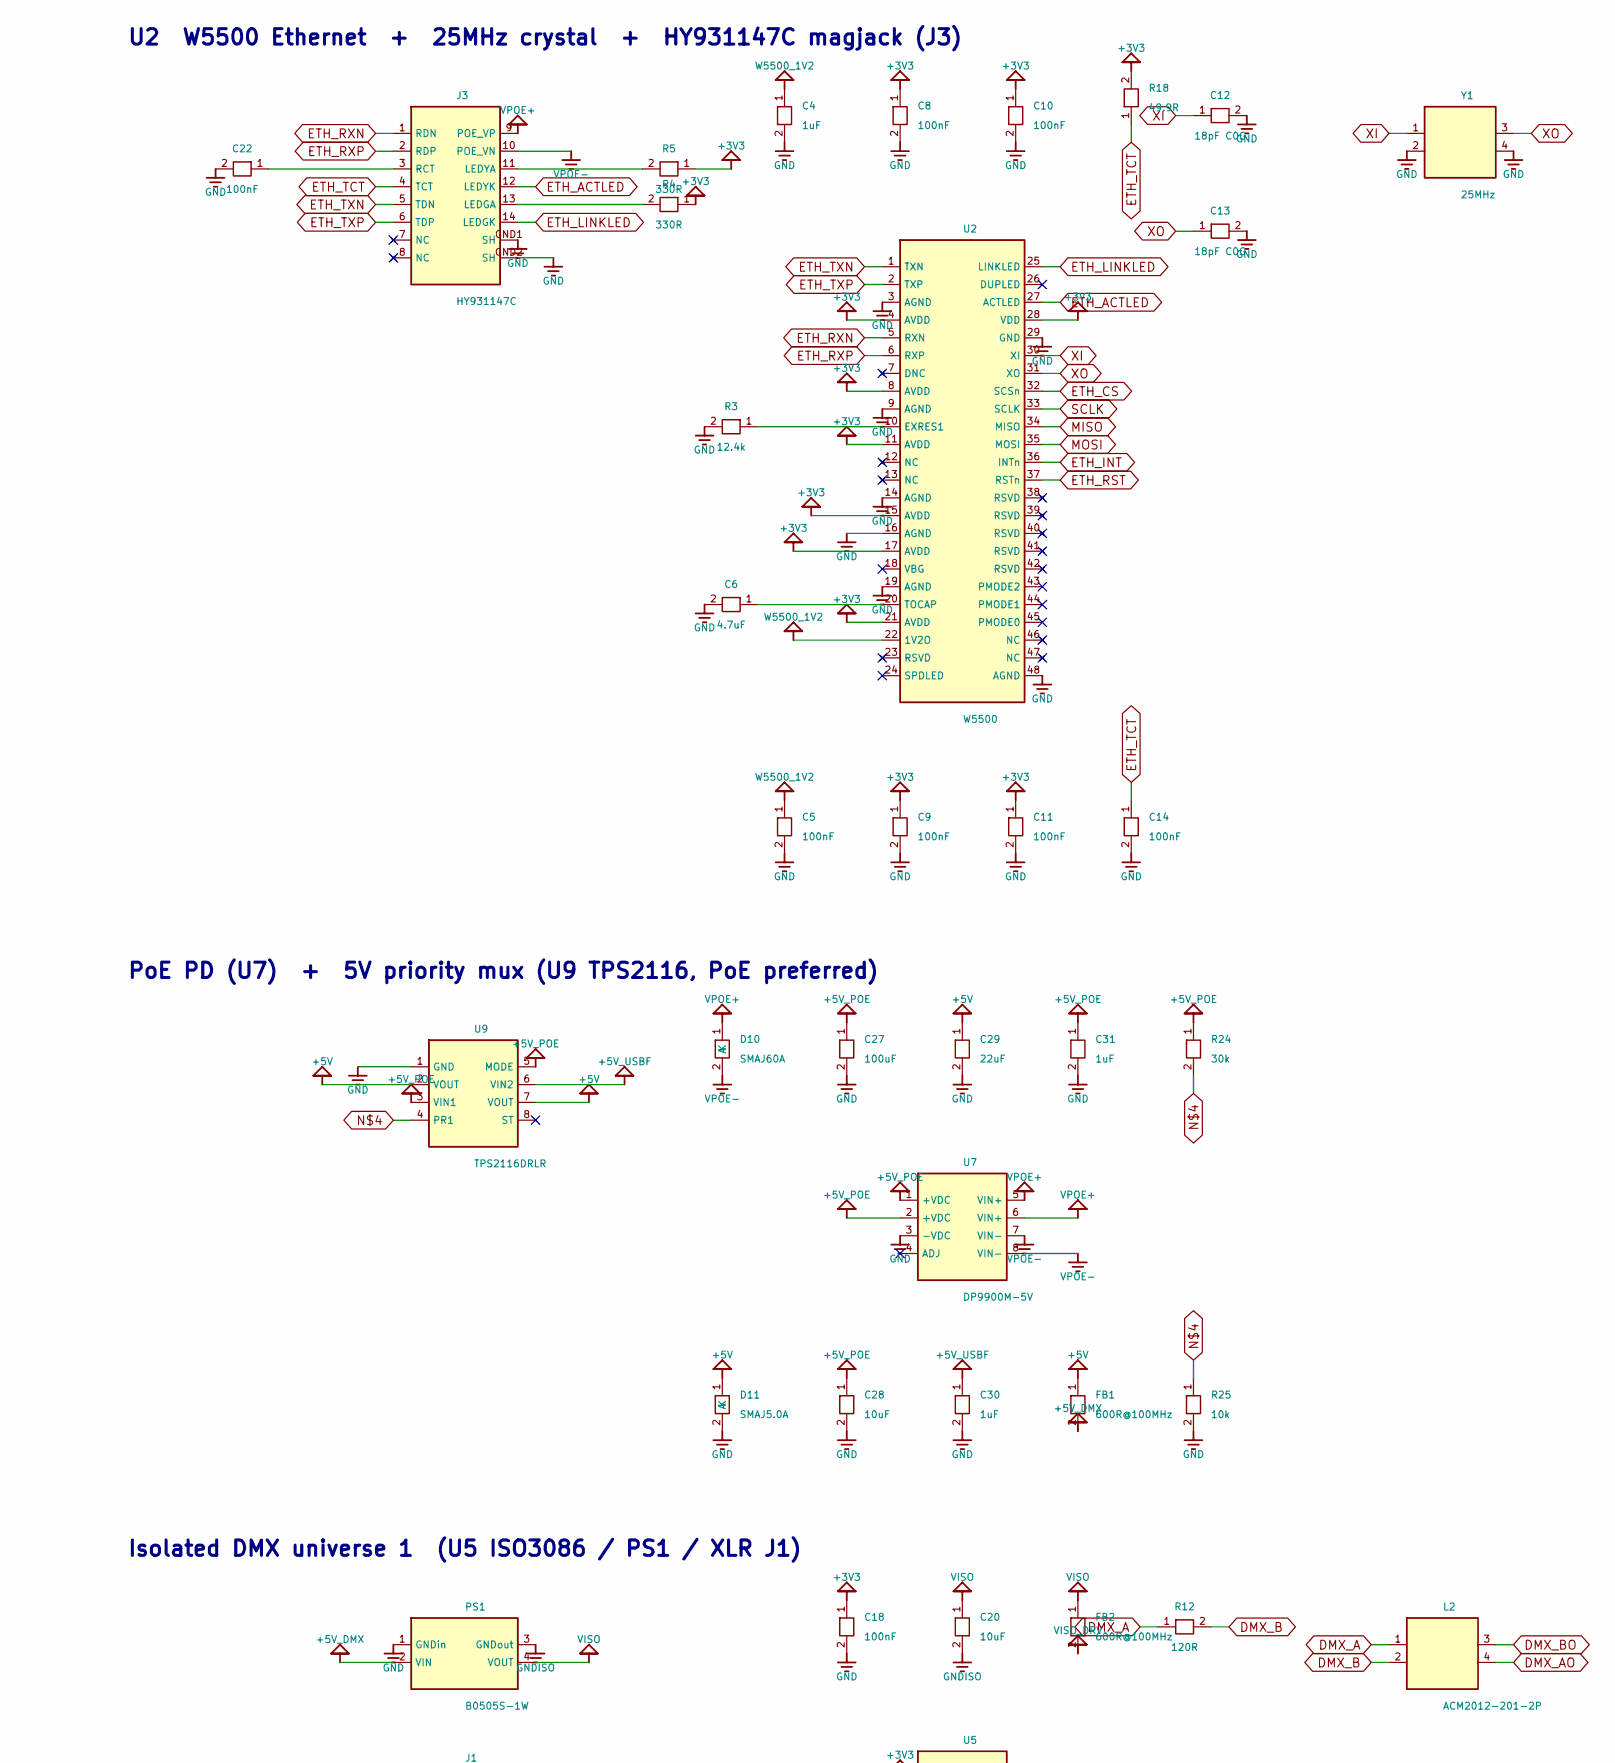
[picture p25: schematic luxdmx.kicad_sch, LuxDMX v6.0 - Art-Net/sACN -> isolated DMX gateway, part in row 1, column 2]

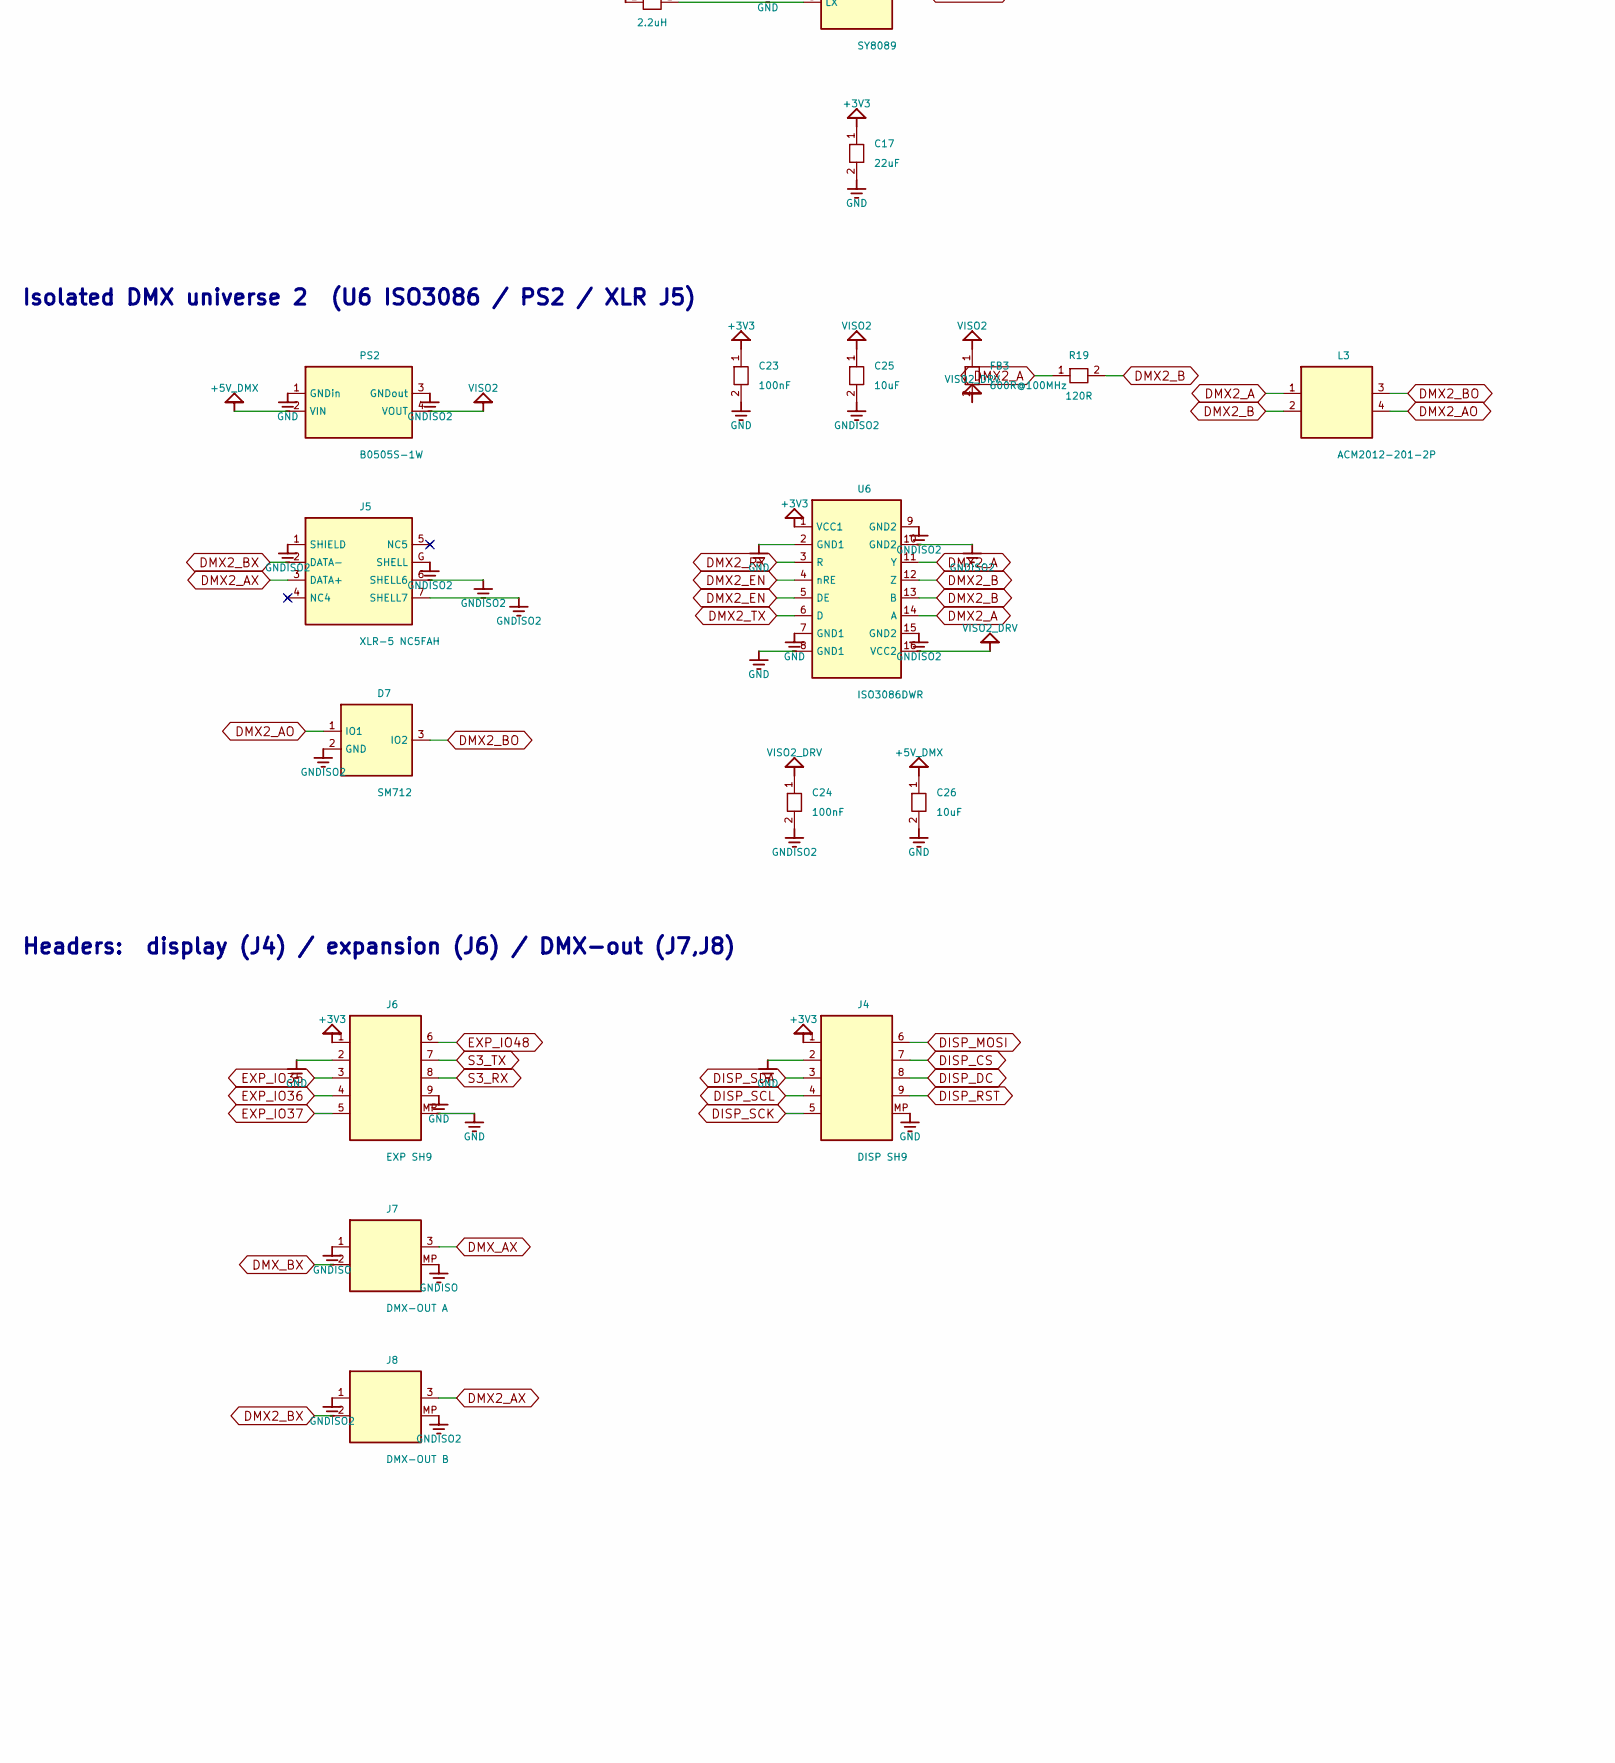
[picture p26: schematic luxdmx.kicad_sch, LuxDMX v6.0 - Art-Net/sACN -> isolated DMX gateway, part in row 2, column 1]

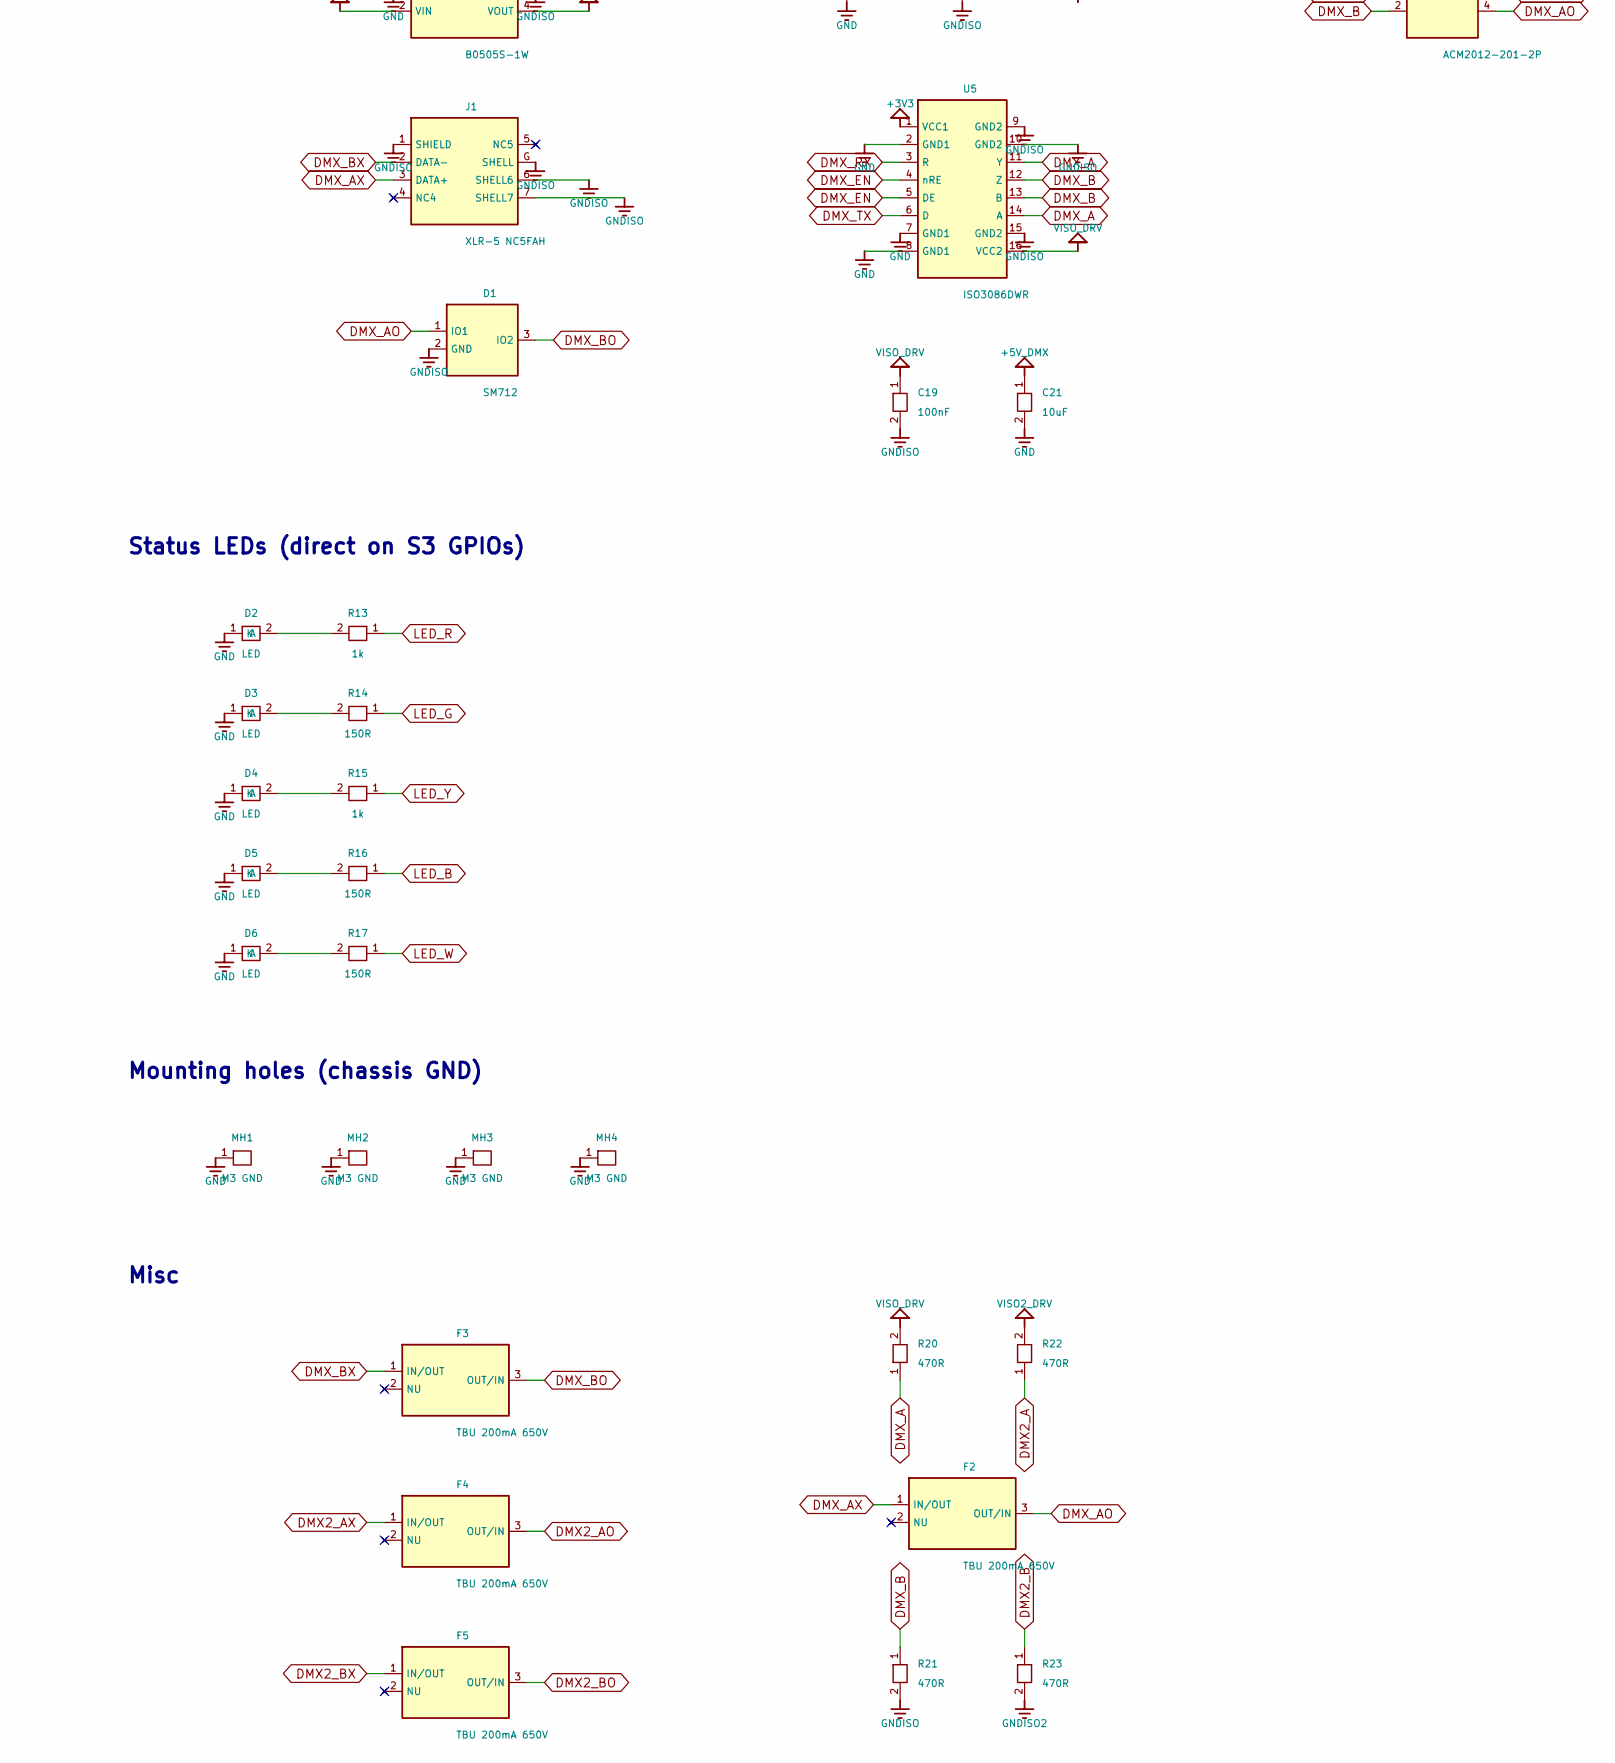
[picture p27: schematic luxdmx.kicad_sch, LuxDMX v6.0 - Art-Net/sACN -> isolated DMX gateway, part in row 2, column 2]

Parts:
C1, C5, C8, C9, C10, C11, C14, C18, C19, C22, C23, C24: 100nF; C_0402_1005Metric
C2, C28: 10uF; C_0805_2012Metric
C3, C4: 1uF; C_0402_1005Metric
C6: 4.7uF; C_0402_1005Metric
C12, C13: 18pF C0G; C_0402_1005Metric
C16, C17, C29: 22uF; C_0805_2012Metric
C20, C21, C25, C26: 10uF; C_1206_3216Metric
C27: 100uF; CP_Elec_6.3x7.7
C30, C31: 1uF; C_0603_1608Metric
D1, D7: SM712; SOT-23
D2, D3, D4, D5, D6: LED; LED_0603_1608Metric
D10: SMAJ60A; D_SMA
D11: SMAJ5.0A; D_SMA
F1: 1.5A 16V PPTC; Fuse_1206_3216Metric
F2, F3, F4, F5: TBU 200mA 650V; DIO-SMD_3P-L6.5-W4.0-BI
FB1, FB2, FB3: 600R@100MHz; L_0805_2012Metric
J1, J5: XLR-5 NC5FAH; CONN-TH_NC5FAH
J2: USB-C; USB-C_SMD-TYPE-C-31-M-12_1
J3: HY931147C; RJ45-TH_HY931147C
J4: DISP SH9; JST_SH_SM09B-SRSS-TB_1x09-1MP_P1.00mm_Horizontal
J6: EXP SH9; JST_SH_SM09B-SRSS-TB_1x09-1MP_P1.00mm_Horizontal
J7: DMX-OUT A; JST_SH_SM03B-SRSS-TB_1x03-1MP_P1.00mm_Horizontal
J8: DMX-OUT B; JST_SH_SM03B-SRSS-TB_1x03-1MP_P1.00mm_Horizontal
L1: 2.2uH; IND-SMD_L4.0-W4.0
L2, L3: ACM2012-201-2P; L_CommonModeChoke_Coilank_ACM2012
MH1, MH2, MH3, MH4: M3 GND; MountingHole_3.2mm_M3_Pad
PS1, PS2: B0505S-1W; PWRM-TH_B0505S-1W
R1, R2, R11, R25: 10k; R_0402_1005Metric
R3: 12.4k; R_0402_1005Metric
R4, R5: 330R; R_0402_1005Metric
R8, R9: 5k1; R_0402_1005Metric
R10: 45.3k; R_0402_1005Metric
R12, R19: 120R; R_0805_2012Metric
R13, R15: 1k; R_0402_1005Metric
R14, R16, R17: 150R; R_0402_1005Metric
R18: 49.9R; R_0402_1005Metric
R20, R21, R22, R23: 470R; R_0402_1005Metric
R24: 30k; R_0402_1005Metric
SW1: BOOT; SW_SPST_B3U-1000P
SW2: RST; SW_SPST_B3U-1000P
U1: ESP32-S3-WROOM-1-N8R2; ESP32-S3-WROOM-1
U2: W5500; LQFP-48_L7.0-W7.0-P0.50-LS9.0-BL
U4: SY8089; SOT-23-5_L3.0-W1.7-P0.95-LS2.8-BR
U5, U6: ISO3086DWR; SOIC-16_L10.3-W7.5-P1.27-LS10.3-BL
U7: DP9900M-5V; PWRM-SMD_DP9900M-5V
U8: USBLC6-2SC6; SOT-23-6
U9: TPS2116DRLR; SOT-583-8
Y1: 25MHz; Crystal_SMD_3225-4Pin_3.2x2.5mm

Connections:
+3V3: C1.1, C2.1, C8.1, C9.1, C10.1, C11.1, C17.1, C18.1, C23.1, J4.1, J6.1, L1.2, R1.1, R2.1, R4.1, R5.1, R10.1, R18.2, U1.2 (3V3), U2.4 (AVDD), U2.8 (AVDD), U2.11 (AVDD), U2.15 (AVDD), U2.17 (AVDD), U2.21 (AVDD), U2.28 (VDD), U5.1 (VCC1), U6.1 (VCC1)
+5V: C16.1, C29.1, D11.1 (K), FB1.1, U4.1 (EN), U4.4 (IN), U9.2 (VOUT), U9.7 (VOUT)
+5V_DMX: C21.1, C26.1, FB1.2, PS1.2 (VIN), PS2.2 (VIN)
+5V_POE: C27.1, C28.1, C31.1, R24.1, U7.1 (+VDC), U7.2 (+VDC), U9.3 (VIN1), U9.5 (MODE)
+5V_USB: F1.1, J2.A4B9 (VBUS), J2.B4A9 (VBUS), U8.5 (VBUS)
+5V_USBF: C30.1, F1.2, U9.6 (VIN2)
BUCK_FB: R10.2, R11.1, U4.5 (FB)
BUCK_LX: L1.1, U4.3 (LX)
CC1: J2.A5 (CC1), R8.1
CC2: J2.B5 (CC2), R9.1
DISP_CS: J4.7, U1.34 (IO41)
DISP_DC: J4.8, U1.35 (IO42)
DISP_MOSI: J4.6, U1.33 (IO40)
DISP_RST: J4.9, U1.31 (IO38)
DISP_SCK: J4.5, U1.32 (IO39)
DISP_SCL: J4.4, U1.5 (IO5)
DISP_SDA: J4.3, U1.4 (IO4)
DMX2_A: L3.1, R19.1, R22.1, U6.11 (Y), U6.14 (A)
DMX2_AO: D7.1 (IO1), F4.3 (OUT/IN), L3.4
DMX2_AX: F4.1 (IN/OUT), J5.3 (DATA+), J8.3
DMX2_B: L3.2, R19.2, R23.1, U6.12 (Z), U6.13 (B)
DMX2_BO: D7.3 (IO2), F5.3 (OUT/IN), L3.3
DMX2_BX: F5.1 (IN/OUT), J5.2 (DATA-), J8.2
DMX2_EN: U1.24 (IO47), U6.4 (nRE), U6.5 (DE)
DMX2_RX: U1.23 (IO21), U6.3 (R)
DMX2_TX: U1.9 (IO16), U6.6 (D)
DMX_A: L2.1, R12.1, R20.1, U5.11 (Y), U5.14 (A)
DMX_AO: D1.1 (IO1), F2.3 (OUT/IN), L2.4
DMX_AX: F2.1 (IN/OUT), J1.3 (DATA+), J7.3
DMX_B: L2.2, R12.2, R21.1, U5.12 (Z), U5.13 (B)
DMX_BO: D1.3 (IO2), F3.3 (OUT/IN), L2.3
DMX_BX: F3.1 (IN/OUT), J1.2 (DATA-), J7.2
DMX_EN: U1.12 (IO8), U5.4 (nRE), U5.5 (DE)
DMX_RX: U1.11 (IO18), U5.3 (R)
DMX_TX: U1.10 (IO17), U5.6 (D)
EN: C3.1, R1.2, SW2.1, U1.3 (EN)
ETH_ACTLED: J3.12 (LEDYK), U2.27 (ACTLED)
ETH_CS: U1.18 (IO10), U2.32 (SCSn)
ETH_INT: U1.22 (IO14), U2.36 (INTn)
ETH_LINKLED: J3.14 (LEDGK), U2.25 (LINKLED)
ETH_RCT: C22.1, J3.3 (RCT)
ETH_RST: U1.17 (IO9), U2.37 (RSTn)
ETH_RXN: J3.1 (RDN), U2.5 (RXN)
ETH_RXP: J3.2 (RDP), U2.6 (RXP)
ETH_TCT: C14.1, J3.4 (TCT), R18.1
ETH_TXN: J3.5 (TDN), U2.1 (TXN)
ETH_TXP: J3.6 (TDP), U2.2 (TXP)
EXP_IO35: J6.3, U1.28 (IO35)
EXP_IO36: J6.4, U1.29 (IO36)
EXP_IO37: J6.5, U1.30 (IO37)
EXP_IO48: J6.6, U1.25 (IO48)
GND: C1.2, C2.2, C3.2, C4.2, C5.2, C6.2, C8.2, C9.2, C10.2, C11.2, C12.2, C13.2, C14.2, C16.2, C17.2, C18.2, C21.2, C22.2, C23.2, C26.2, C27.2, C28.2, C29.2, C30.2, C31.2, D2.1 (K), D3.1 (K), D4.1 (K), D5.1 (K), D6.1 (K), D11.2 (A), J2.1 (SH), J2.2 (SH), J2.3 (SH), J2.4 (SH), J2.A1B12 (GND), J2.B1A12 (GND), J3.GND1 (SH), J3.GND2 (SH), J4.2, J4.MP, J6.2, J6.9, J6.MP, MH1.1, MH2.1, MH3.1, MH4.1, PS1.1 (GNDin), PS2.1 (GNDin), R3.2, R8.2, R9.2, R11.2, R25.2, SW1.2, SW2.2, U1.1 (GND), U1.40 (GND), U1.41 (EP), U2.3 (AGND), U2.9 (AGND), U2.14 (AGND), U2.16 (AGND), U2.19 (AGND), U2.29 (GND), U2.48 (AGND), U4.2 (GND), U5.2 (GND1), U5.7 (GND1), U5.8 (GND1), U6.2 (GND1), U6.7 (GND1), U6.8 (GND1), U7.3 (-VDC), U8.2 (GND), U9.1 (GND), Y1.2, Y1.4
GNDISO: C19.2, C20.2, D1.2 (GND), J1.1 (SHIELD), J1.6 (SHELL6), J1.7 (SHELL7), J1.G (SHELL), J7.1, J7.MP, PS1.3 (GNDout), R21.2, U5.9 (GND2), U5.10 (GND2), U5.15 (GND2)
GNDISO2: C24.2, C25.2, D7.2 (GND), J5.1 (SHIELD), J5.6 (SHELL6), J5.7 (SHELL7), J5.G (SHELL), J8.1, J8.MP, PS2.3 (GNDout), R23.2, U6.9 (GND2), U6.10 (GND2), U6.15 (GND2)
IO0: R2.2, SW1.1, U1.27 (IO0)
LED_B: R16.1, U1.7 (IO7)
LED_G: R14.1, U1.38 (IO2)
LED_R: R13.1, U1.39 (IO1)
LED_W: R17.1, U1.8 (IO15)
LED_Y: R15.1, U1.6 (IO6)
MISO: U1.21 (IO13), U2.34 (MISO)
MOSI: U1.19 (IO11), U2.35 (MOSI)
unnamed: R3.1, U2.10 (EXRES1)
unnamed: J3.11 (LEDYA), R5.2
unnamed: R24.2, R25.1, U9.4 (PR1)
unnamed: D2.2 (A), R13.2
unnamed: D3.2 (A), R14.2
unnamed: D4.2 (A), R15.2
unnamed: D5.2 (A), R16.2
unnamed: D6.2 (A), R17.2
S3_RX: J6.8, U1.36 (RXD0)
S3_TX: J6.7, U1.37 (TXD0)
SCLK: U1.20 (IO12), U2.33 (SCLK)
TOCAP: C6.1, U2.20 (TOCAP)
USB_DM: J2.A7 (DN1), J2.B7 (DN2), U1.13 (IO19), U8.3 (IO2), U8.4 (IO2)
USB_DP: J2.A6 (DP1), J2.B6 (DP2), U1.14 (IO20), U8.1 (IO1), U8.6 (IO1)
VISO: C20.1, FB2.1, PS1.4 (VOUT)
VISO2: C25.1, FB3.1, PS2.4 (VOUT)
VISO2_DRV: C24.1, FB3.2, R22.2, U6.16 (VCC2)
VISO_DRV: C19.1, FB2.2, R20.2, U5.16 (VCC2)
VPOE+: D10.1 (K), J3.9 (POE_VP), U7.5 (VIN+), U7.6 (VIN+)
VPOE-: D10.2 (A), J3.10 (POE_VN), U7.7 (VIN-), U7.8 (VIN-)
W5500_1V2: C4.1, C5.1, U2.22 (1V2O)
XI: C12.1, U2.30 (XI), Y1.1
XO: C13.1, U2.31 (XO), Y1.3

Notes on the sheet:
U1 ESP32-S3-WROOM-1 + reset / boot
USB-C (J2) + ESD (U8) -> S3 native USB (USB-Serial-JTAG on IO19/IO20)
U4 SY8089 5V -> 3.3V buck
Isolated DMX universe 2 (U6 ISO3086 / PS2 / XLR J5)
Headers: display (J4) / expansion (J6) / DMX-out (J7,J8)
U2 W5500 Ethernet + 25MHz crystal + HY931147C magjack (J3)
PoE PD (U7) + 5V priority mux (U9 TPS2116, PoE preferred)
Isolated DMX universe 1 (U5 ISO3086 / PS1 / XLR J1)
Status LEDs (direct on S3 GPIOs)
Mounting holes (chassis GND)
Misc

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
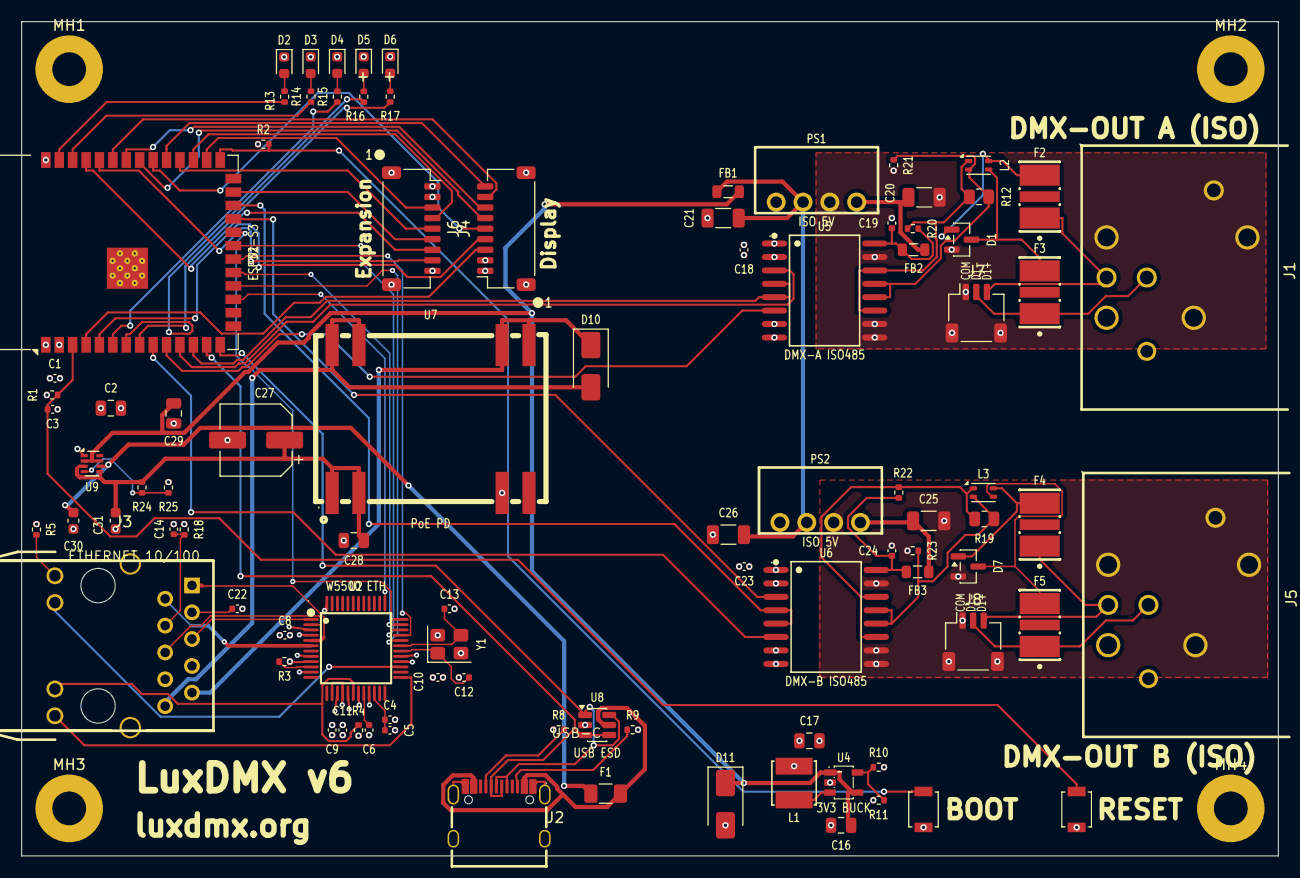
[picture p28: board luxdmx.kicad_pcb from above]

Board: 4 copper layers, 119.0 x 79.0 mm, 97 parts (0 on the bottom side), 86 nets.

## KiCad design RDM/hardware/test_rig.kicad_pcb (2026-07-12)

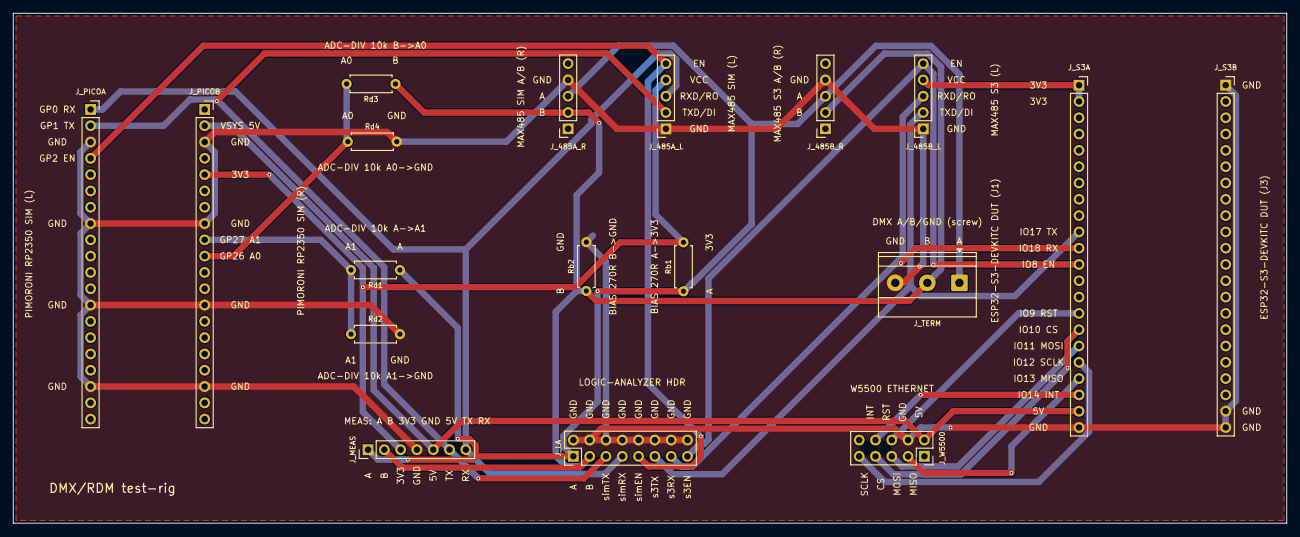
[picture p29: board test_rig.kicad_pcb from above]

Board: 2 copper layers, 198.4 x 79.5 mm, 18 parts (0 on the bottom side), 20 nets.

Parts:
J_485A_L: MAX485 SIM (L); PinSocket_1x05_P2.54mm_Vertical
J_485A_R: MAX485 SIM A/B (R); PinSocket_1x05_P2.54mm_Vertical
J_485B_L: MAX485 S3 (L); PinSocket_1x05_P2.54mm_Vertical
J_485B_R: MAX485 S3 A/B (R); PinSocket_1x05_P2.54mm_Vertical
J_LA: LOGIC-ANALYZER HDR; PinHeader_2x08_P2.54mm_Vertical
J_MEAS: MEAS: A B 3V3 GND 5V TX RX; PinHeader_1x07_P2.54mm_Vertical
J_PICOA: PIMORONI RP2350 SIM (L); PinSocket_1x20_P2.54mm_Vertical
J_PICOB: PIMORONI RP2350 SIM (R); PinSocket_1x20_P2.54mm_Vertical
J_S3A: ESP32-S3-DEVKITC DUT (J1); PinSocket_1x22_P2.54mm_Vertical
J_S3B: ESP32-S3-DEVKITC DUT (J3); PinSocket_1x22_P2.54mm_Vertical
J_TERM: DMX A/B/GND (screw); TerminalBlock_Phoenix_MKDS-1,5-3_1x03_P5.00mm_Horizontal
J_W5500: W5500 ETHERNET; PinSocket_2x05_P2.54mm_Vertical
Rb1: BIAS 270R A->3V3; R_Axial_DIN0207_L6.3mm_D2.5mm_P7.62mm_Horizontal
Rb2: BIAS 270R B->GND; R_Axial_DIN0207_L6.3mm_D2.5mm_P7.62mm_Horizontal
Rd1: ADC-DIV 10k A->A1; R_Axial_DIN0207_L6.3mm_D2.5mm_P7.62mm_Horizontal
Rd2: ADC-DIV 10k A1->GND; R_Axial_DIN0207_L6.3mm_D2.5mm_P7.62mm_Horizontal
Rd3: ADC-DIV 10k B->A0; R_Axial_DIN0207_L6.3mm_D2.5mm_P7.62mm_Horizontal
Rd4: ADC-DIV 10k A0->GND; R_Axial_DIN0207_L6.3mm_D2.5mm_P7.62mm_Horizontal

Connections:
+3V3_S3: J_485B_L.4, J_S3A.1, J_S3A.2
+3V3_SIM: J_485A_L.4, J_MEAS.3, J_PICOB.5, Rb1.2
+5V: J_MEAS.5, J_PICOB.2, J_S3A.21, J_W5500.2
BUS_A: J_485A_R.3, J_485B_R.3, J_LA.1, J_MEAS.1, J_TERM.1, Rb1.1, Rd1.1
BUS_B: J_485A_R.2, J_485B_R.2, J_LA.3, J_MEAS.2, J_TERM.2, Rb2.1, Rd3.1
ETH_CS: J_S3A.16, J_W5500.7
ETH_INT: J_S3A.20, J_W5500.8
ETH_MISO: J_S3A.19, J_W5500.3
ETH_MOSI: J_S3A.17, J_W5500.5
ETH_RST: J_S3A.15, J_W5500.6
ETH_SCLK: J_S3A.18, J_W5500.9
GND: J_485A_L.1, J_485A_R.4, J_485B_L.1, J_485B_R.4, J_LA.2, J_LA.4, J_LA.6, J_LA.8, J_LA.10, J_LA.12, J_LA.14, J_LA.16, J_MEAS.4, J_PICOA.3, J_PICOA.8, J_PICOA.13, J_PICOA.18, J_PICOB.3, J_PICOB.8, J_PICOB.13, J_PICOB.18, J_S3A.22, J_S3B.1, J_S3B.21, J_S3B.22, J_TERM.3, J_W5500.4, Rb2.2, Rd2.2, Rd4.2
S3_DMX_EN: J_485B_L.5, J_LA.15, J_S3A.12
S3_DMX_RX: J_485B_L.3, J_LA.13, J_S3A.11
S3_DMX_TX: J_485B_L.2, J_LA.11, J_S3A.10
SIM_A0: J_PICOB.10, Rd3.2, Rd4.1
SIM_A1: J_PICOB.9, Rd1.2, Rd2.1
SIM_EN: J_485A_L.5, J_LA.9, J_PICOA.4
SIM_RX: J_485A_L.3, J_LA.7, J_MEAS.7, J_PICOA.1
SIM_TX: J_485A_L.2, J_LA.5, J_MEAS.6, J_PICOA.2

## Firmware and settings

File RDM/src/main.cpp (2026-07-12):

// RP2350 multi-fixture RDM responder / simulator  (Pimoroni Pico Plus 2 W)
// =============================================================================
// A crowded RDM bus in one box: up to MAXFIX virtual E1.20 fixtures, each with its
// own UID / DMX address / footprint / personality / mute state, answered from custom
// PIO on cycle-accurate 250 kBaud timing. Built to develop and STRESS-TEST the LuxDMX
// ESP32-S3 RDM controller (does it discover and talk to every fixture on a busy bus,
// catching every response?).
//
//   core 1 : PIO RX (GP0) + message-length frame completion + tight-turnaround TX (GP1)
//            - DISC_UNIQUE_BRANCH -> discovery response for the first in-range fixture
//              (controller subdivides on any reply -> full binary search of all fixtures)
//            - DISC_MUTE / DISC_UN_MUTE  -> mute state + mute ACK
//            - GET / SET  -> DEVICE_INFO, SW_VERSION, MODEL_DESC, MANUFACTURER_LABEL,
//              SUPPORTED_PARAMETERS, DMX_START_ADDRESS, IDENTIFY_DEVICE,
//              SENSOR_DEFINITION + SENSOR_VALUE (1 simulated temperature sensor)  (+ NACK others)
//   core 0 : activity LED, USB console + command parser, per-discovery drop report.
//
// Wiring (confirmed): GP0=RO(RX), GP1=DI(TX), GP2=DE+RE (low=receive).
// Console commands (115200, one per line):
//   t<us>   set responder turnaround delay (E1.20 min 176, max 2000)
//   f<n>    set active fixture count (1..MAXFIX) and regenerate the bus
//   r       un-mute all fixtures    v  toggle verbose (per-DUB trace)    ?  status
//   a       DMX analyzer stats (framing errors / refresh / break, Swisson-style); ar = reset window
// -----------------------------------------------------------------------------
#include <Arduino.h>
#include <WiFi.h>
#include <WebServer.h>
#include "hardware/pio.h"
#include "hardware/clocks.h"
#include "hardware/gpio.h"
#include "hardware/uart.h"
#include "hardware/dma.h"
#include "dmxrdm_rx.pio.h"
#include "dmxrdm_tx.pio.h"
#include "dmxa_rx.pio.h"
#include "web_index.h"

static const char* STA_SSID = "dropsnet";           // join the normal network
static const char* STA_PASS = "dasistprivat0815";
static const char* AP_SSID  = "LuxDMX-RDM-Sim";     // fallback AP if STA fails
static const char* AP_PASS  = "luxrdm-sim";         // >= 8 chars
static WebServer   g_web(80);

static const uint8_t RS485_RX = 0;   // GP0 <- RO
static const uint8_t RS485_TX = 1;   // GP1 -> DI
static const uint8_t RS485_DE = 2;   // GP2 -> DE+RE (high=drive, low=receive)

// --- Bus timing (E1.20) ------------------------------------------------------
static volatile uint32_t g_turnaround = 250;   // reply delay us; sweepable via console
static const uint32_t BREAK_US = 176, MAB_US = 12;

// --- Fuzz / fault injection (M4): make fixtures deliberately misbehave ---------
static volatile uint8_t  g_fuzzDrop = 0;        // drop this % of responses
static volatile bool     g_fuzzLate = false;    // answer near the 2 ms limit
static volatile bool     g_fuzzBadCsum = false; // occasionally corrupt our checksum
static volatile bool     g_fuzzMute = false;    // sometimes ignore DISC_MUTE
static uint32_t g_rng = 0x9E3779B1;
static inline uint32_t rng() { g_rng ^= g_rng<<13; g_rng ^= g_rng>>17; g_rng ^= g_rng<<5; return g_rng; }
static inline bool chance(uint8_t pct) { return pct && (rng()%100) < pct; }
static inline uint32_t replyDelay() { return g_fuzzLate ? (1500 + rng()%400) : g_turnaround; }

// --- RDM constants -----------------------------------------------------------
static const uint8_t  RDM_SC = 0xCC, RDM_SUB_SC = 0x01, RDM_PREAMBLE = 0xFE, RDM_DELIM = 0xAA;
static const uint8_t  CC_DISC = 0x10, CC_DISC_RESP = 0x11;
static const uint8_t  CC_GET = 0x20, CC_GET_RESP = 0x21, CC_SET = 0x30, CC_SET_RESP = 0x31;
static const uint8_t  RESP_ACK = 0x00, RESP_NACK = 0x02;
static const uint16_t PID_DISC_UNIQUE_BRANCH = 0x0001, PID_DISC_MUTE = 0x0002, PID_DISC_UN_MUTE = 0x0003;
static const uint16_t PID_SUPPORTED_PARAMETERS = 0x0050, PID_DEVICE_INFO = 0x0060;
static const uint16_t PID_DEVICE_MODEL_DESCRIPTION = 0x0080, PID_MANUFACTURER_LABEL = 0x0081;
static const uint16_t PID_SOFTWARE_VERSION_LABEL = 0x00C0, PID_DMX_START_ADDRESS = 0x00F0;
static const uint16_t PID_IDENTIFY_DEVICE = 0x1000;
static const uint16_t PID_SENSOR_DEFINITION = 0x0200, PID_SENSOR_VALUE = 0x0201;
static const uint16_t NR_UNKNOWN_PID = 0x0000, NR_DATA_OUT_OF_RANGE = 0x0001;

// --- Virtual fixtures --------------------------------------------------------
static const int MAXFIX = 200;
struct Fixture {
  uint8_t  uid[6];
  uint16_t address; uint16_t footprint;
  uint16_t modelId; uint16_t category;
  uint8_t  persCur; uint8_t persCount;
  const char* model;
  volatile bool muted;
  volatile bool identify;
};
static Fixture g_fix[MAXFIX];
static volatile int g_fixCount = 64;
static const char* MODELS[] = { "LX Par 4", "LX Wash 8", "LX Spot 16", "LX Mover 32",
                                "LX Strobe", "LX Bar 12", "LX Beam", "LX Blinder" };

static int  uidcmp(const uint8_t* a, const uint8_t* b) { for (int i=0;i<6;i++) if (a[i]!=b[i]) return a[i]<b[i]?-1:1; return 0; }
static bool inRange(const uint8_t* u, const uint8_t* lo, const uint8_t* hi) { return uidcmp(u,lo)>=0 && uidcmp(u,hi)<=0; }
static bool isBroadcast(const uint8_t* u) { for (int i=0;i<6;i++) if (u[i]!=0xFF) return false; return true; }

// Spread UIDs across the device-id space (Knuth multiplicative hash is a bijection, so
// every fixture is unique) so the controller's binary search is realistic, not trivial.
static void genFixtures(int n) {
  if (n < 1) n = 1; if (n > MAXFIX) n = MAXFIX;
  for (int i = 0; i < n; i++) {
    uint32_t h = (uint32_t)(i + 1) * 2654435761u;
    if (h == 0xFFFFFFFFu) h = 0xFFFFFFFEu;               // avoid manufacturer-broadcast dev id
    g_fix[i].uid[0] = 0x4C; g_fix[i].uid[1] = 0x58;      // manufacturer "LX"
    g_fix[i].uid[2] = h >> 24; g_fix[i].uid[3] = h >> 16; g_fix[i].uid[4] = h >> 8; g_fix[i].uid[5] = h;
    g_fix[i].footprint = 1 + (i % 32);
    g_fix[i].address   = 1 + ((i * 17) % 500);
    g_fix[i].modelId   = 0x0100 + (i % 8);
    g_fix[i].category  = 0x0500;
    g_fix[i].persCur   = 1; g_fix[i].persCount = 1 + (i % 4);
    g_fix[i].model     = MODELS[i % (int)(sizeof(MODELS)/sizeof(MODELS[0]))];
    g_fix[i].muted     = false; g_fix[i].identify = false;
  }
  g_fixCount = n;
}
static int mutedCount() { int c=0; const int n=g_fixCount; for (int i=0;i<n;i++) if (g_fix[i].muted) c++; return c; }

// --- shared state (core 1 writes, core 0 reads) ------------------------------
static volatile uint32_t g_frames = 0, g_rdmSeen = 0, g_lastActivityMs = 0, g_lastRdmMs = 0, g_rxBytes = 0, g_rxBadCsum = 0;
static volatile uint32_t g_respCount = 0, g_getCount = 0, g_setCount = 0, g_nackCount = 0;
// S3 RX-loss metric: controller re-asks the SAME branch it just got a reply for = it
// dropped our (spec-compliant) response. Ground truth for "does the S3 catch every response".
static volatile uint32_t g_ctrlReAsk = 0, g_discReAsk = 0;
static uint8_t g_prevLo[6], g_prevHi[6]; static bool g_prevReplied = false, g_havePrev = false;
static volatile uint8_t  g_lastCC = 0; static volatile uint16_t g_lastPID = 0;
static volatile uint8_t  g_ctrlUid[6] = {0};
static volatile bool     g_verbose = false;
static volatile bool     g_listenOnly = false;   // decode+count but never transmit (isolate sim TX)
static volatile bool     g_diagMode = false;     // wiring-check: LED reflects idle-bus RX noise
// Analog bus probe: tap A->A0(GP40) and B->A1(GP41) each via a 2:1 divider (line-10k-pin-10k-GND).
static const float       ADC_DIVIDER = 2.0f;      // undo the /2 hardware divider in software
static volatile int      g_vdiff = 0, g_vpp = 0;  // A-B idle level and noise, in mV (actual line)
// --- DMX line analyzer (issue #64): count framing errors like a Swisson tester --------------------
// A dedicated pio1 SM samples 8 data bits + the stop bit of every slot. A framing error = stop bit
// low. Break boundaries are found from the gap in byte arrivals (the sole 0x00-with-framing byte the
// PIO emits during a break is the placeholder that precedes the big gap, so we drop it). Lets the sim
// double as a DMX-output QA meter: run it against a LuxDMX output and watch framing errors accumulate
// with network load (the core-contention symptom KM-LED reported on WT32-ETH01).
static volatile uint32_t g_anFrames = 0;      // valid DMX frames seen (break -> slots)
static volatile uint32_t g_anSlots = 0;       // slot count of the last complete frame (513 incl. start)
static volatile uint32_t g_anFramingErr = 0;  // total framing errors (stop bit low on a data slot)
static volatile uint32_t g_anRxSlots = 0;     // total data slots inspected (denominator for the rate)
static uint32_t g_anSlotCount = 0;            // clean data slots since the last break (frame builder)
static uint32_t g_anExpectFrame = 0;          // frame-length reference, clamped to 513 (see serviceAnalyzer)
static volatile uint8_t  g_anStartCode = 0;   // slot-0 of the last frame (0x00 = DMX, 0xCC = RDM)
static volatile uint32_t g_anBreakUs = 0;     // approx inter-frame gap (break+MAB+MBB), microseconds
static volatile float    g_anRefreshHz = 0;   // refresh rate from slot-0 -> slot-0 spacing
static volatile uint32_t g_anResetMs = 0;     // millis() at last analyzer counter reset (for rate calc)

// --- GROUND-TRUTH framing detector: the RP's HARDWARE UART (issue #64 re-investigation) -----------
// The PIO analyzer's framing detection proved unreliable (gap-based = false positives on FIFO bursts;
// position-based = blind at the frame boundary). A real PL011 UART is the authoritative framing check
// -- it's exactly what a Swisson tester uses internally, and it's immune to how promptly we poll it
// (32-deep HW FIFO + an explicit overrun flag if we ever fall behind). Wire WT32 GPIO4 -> RP GP5.
//
// The PL011 data register (DR) carries per-byte error flags: bit8=FE (framing), bit10=BE (break),
// bit11=OE (overrun). A DMX break is a long low -> the UART flags FE+BE on a 0x00 char: that's the
// frame boundary, NOT a real error. A GENUINE framing error (a slot whose stop bit was low, or a
// mis-framed first slot after a too-short MAB) shows as FE set with BE CLEAR. That is the number #64
// is really about, and it also catches the break/MAB-boundary corruption the PIO analyzer missed.
static const uint8_t GT_RX_PIN = 5;           // GP5 = uart1 RX
#define GT_UART uart1
static volatile uint32_t g_gtFrames = 0;      // BE events (breaks) = frames seen
static volatile uint32_t g_gtFramingErr = 0;  // FE && !BE = genuine framing errors (the ground truth)
static volatile uint32_t g_gtOverrun = 0;     // OE = we fell behind draining (measurement-integrity flag)
static volatile uint32_t g_gtBytes = 0;
static volatile float    g_gtRefreshHz = 0;
static volatile uint32_t g_gtResetMs = 0;
static bool g_gtReady = false;

// --- Reply-side capture -----------------------------------------------------------------------
// The responder's own RO goes dark while it drives (single combined DE+RE), so the on-board analyzer
// can't see the RDM reply it transmits. To catch reply corruption we tap what the CONTROLLER actually
// receives: wire the WT32 controller's RDM-reply RX pin (IO4, logic level after its transceiver) to
// GP13 (uart0 RX). The RP then holds "what I sent" next to "what the controller got" and diffs them,
// which pins any bit error on the analog path (RP DI -> xcvr -> bus -> WT32 xcvr -> IO4) versus the
// controller's own firmware read. RDM replies are break-less, so a reply burst is split on an idle gap.
static const uint8_t RC_RX_PIN = 13;          // GP13 = uart0 RX <- WT32 IO4 (controller reply RX)
#define RC_UART uart0
static volatile uint32_t g_rcBytes = 0;       // bytes the controller reply line delivered
static volatile uint32_t g_rcFramingErr = 0;  // FE on a reply byte = on-wire corruption (break-less)
static volatile uint32_t g_rcOverrun = 0;     // OE = capture fell behind
static volatile uint32_t g_rcReplies = 0;     // reply bursts located + checked
static volatile uint32_t g_rcBadReplies = 0;  // of those, how many were corrupted (mismatch or framing err)
static volatile uint32_t g_rcMismatch = 0;    // last reply: bytes that differ from what we sent
static uint8_t  g_txReply[64]; static volatile int g_txReplyLen = 0;   // last reply the responder sent
static uint8_t  g_rcWin[96];   static volatile int g_rcWinLen = 0;     // raw bytes seen in a reply window
static uint8_t  g_rcLast[64];  static volatile int g_rcLastLen = 0;    // the reply as the controller saw it
static volatile uint32_t g_rcFeAtArm = 0;     // framing-error count when a reply window opened
static volatile uint32_t g_rcCalls = 0;       // DIAG: times rcAfterReply ran (== replies we drove)
static volatile int      g_rcWinLast = 0;     // DIAG: bytes the last reply-window drain saw
static volatile bool     g_rcDisable = false; // DIAG: when set, skip all reply-capture (isolate analyzer)
static volatile bool     g_mlDisable = false; // DIAG: when set, skip the analog A-B sampler in loop()
static volatile uint32_t g_rcResetMs = 0;
static bool g_rcReady = false;

// Snapshot the bytes we are about to drive AND arm the capture. The controller's reply-RX line also
// carries the forward DMX, so we only trust bytes that land in the short window right after we send
// (and then align on the reply signature). Without this the capture just grabs the next DMX frame.
static inline void snapTxReply(const uint8_t* b, int n) {
  int m = n > (int)sizeof(g_txReply) ? (int)sizeof(g_txReply) : n;
  for (int i = 0; i < m; i++) g_txReply[i] = b[i];
  g_txReplyLen = m;
  // Flush any stale forward-DMX out of the capture FIFO so the drain after the send sees only the
  // reply (the bus is idle through the turnaround, so nothing else lands in between).
  if (g_rcReady) { uart_hw_t* h = uart_get_hw(RC_UART); while (!(h->fr & UART_UARTFR_RXFE_BITS)) (void)h->dr; }
  g_rcWinLen = 0; g_rcFeAtArm = g_rcFramingErr;
}
static String hexBuf(const uint8_t* b, int n) {
  static const char H[] = "0123456789ABCDEF";
  String s; s.reserve(n * 2);
  for (int i = 0; i < n; i++) { s += H[b[i] >> 4]; s += H[b[i] & 0xF]; }
  return s;
}

static void gtUartInit() {
  uart_init(GT_UART, 250000);
  uart_set_format(GT_UART, 8, 2, UART_PARITY_NONE);   // DMX slot framing = 8 data + 2 stop, no parity
  uart_set_fifo_enabled(GT_UART, true);
  gpio_set_function(GT_RX_PIN, GPIO_FUNC_UART);
  g_gtReady = true;
}
// Drain the UART FIFO, folding per-byte flags into the ground-truth counters. Call often (core 1).
static void serviceGtUart() {
  if (!g_gtReady) return;
  static uint32_t lastBreakUs = 0; static bool haveBreak = false;
  uart_hw_t* h = uart_get_hw(GT_UART);
  while (!(h->fr & UART_UARTFR_RXFE_BITS)) {           // while RX FIFO is not empty
    const uint32_t dr = h->dr;                         // pop one entry: data + error flags
    g_gtBytes++;
    if (dr & (1u << 11)) g_gtOverrun++;                // OE
    if (dr & (1u << 10)) {                             // BE = break = frame boundary
      g_gtFrames++;
      const uint32_t nowUs = time_us_32();
      if (haveBreak) { const uint32_t p = nowUs - lastBreakUs;
        if (p > 1000 && p < 200000) g_gtRefreshHz = 1000000.0f / (float)p; }
      lastBreakUs = nowUs; haveBreak = true;
    } else if (dr & (1u << 8)) {                        // FE without BE = a genuine framing error
      g_gtFramingErr++;
    }
  }
}

static void rcUartInit() {
  uart_init(RC_UART, 250000);
  uart_set_format(RC_UART, 8, 2, UART_PARITY_NONE);   // same slot framing as DMX/RDM: 8 data + 2 stop
  uart_set_fifo_enabled(RC_UART, true);
  gpio_set_function(RC_RX_PIN, GPIO_FUNC_UART);
  gpio_pull_up(RC_RX_PIN);      // idle-high when no tap is wired (a driven WT32 IO4 overrides this),
                                // so the "no tap" state reads clean instead of flagging float glitches
  busy_wait_us(200);            // let the pull-up settle, then drop the transition glitch the FIFO
  uart_hw_t* h = uart_get_hw(RC_UART);            // latched while the pad switched to UART mode
  while (!(h->fr & UART_UARTFR_RXFE_BITS)) (void)h->dr;
  g_rcReady = true;
}
// Pull the actual reply out of the captured window and diff it against what we drove. The window can
// also hold trailing forward-DMX bytes, so align on the reply signature: the 0xAA delimiter for a
// DISC reply, else the start code + sub-start-code (0xCC 0x01) for a GET/SET reply.
static void rcExtractReply() {
  if (g_txReplyLen == 0 || g_rcWinLen == 0) return;
  const bool disc = (g_txReply[0] == RDM_PREAMBLE);        // 0xFE preamble -> DISC reply
  int start = -1, soff = 0;
  if (disc) {
    for (int i = 0; i < g_txReplyLen; i++) if (g_txReply[i] == RDM_DELIM) { soff = i; break; }  // sent delimiter
    for (int i = 0; i < g_rcWinLen;   i++) if (g_rcWin[i]   == RDM_DELIM) { start = i; break; }  // recv delimiter
  } else {
    for (int i = 0; i + 1 < g_rcWinLen; i++) if (g_rcWin[i] == g_txReply[0] && g_rcWin[i+1] == g_txReply[1]) { start = i; break; }
  }
  if (start < 0) { g_rcBadReplies++; return; }             // reply signature not found (lost/mangled)
  int n = 0; uint32_t diff = 0;
  for (; start + n < g_rcWinLen && soff + n < g_txReplyLen && n < (int)sizeof(g_rcLast); n++) {
    g_rcLast[n] = g_rcWin[start + n];
    if (g_rcLast[n] != g_txReply[soff + n]) diff++;
  }
  const int expect = g_txReplyLen - soff;
  if (n < expect) diff += (expect - n);                    // truncated (overflow) counts as mismatch
  g_rcLastLen = n; g_rcMismatch = diff; g_rcReplies++;
  const bool feInWindow = (g_rcFramingErr != g_rcFeAtArm);
  if (diff > 0 || feInWindow) g_rcBadReplies++;
}
// Between transactions, just drain the FIFO so forward DMX can't overflow it. rcBytes is a
// bus-activity reference; the reply itself is grabbed synchronously by rcAfterReply().
static void serviceRcUart() {
  if (!g_rcReady) return;
  uart_hw_t* h = uart_get_hw(RC_UART);
  while (!(h->fr & UART_UARTFR_RXFE_BITS)) { (void)h->dr; g_rcBytes++; }
}
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
void loop() {
  if (g_diagMode) serviceDiagLed(); else serviceLed();
  g_web.handleClient();

  // Keep the A-B analog reading fresh for the dashboard in every mode (it used to update only in
  // diag mode, so the "A-B line" tile sat at 0 the rest of the time).
  static uint32_t mlLast = 0;
  if (!g_mlDisable && millis() - mlLast >= 400) { mlLast = millis(); measureLines(); }

  // Wiring-check readout on serial too (numbers, for when you have the console open).
  if (g_diagMode) {
    static uint32_t dl = 0, db = 0;
    if (millis() - dl >= 500) { const uint32_t n = g_rxBytes - db; db = g_rxBytes; dl = millis();
      Serial.printf("[diag] noise=%lu bytes/500ms  A-B idle=%d mV  noise=%d mVpp  %s\n",
        (unsigned long)n, g_vdiff, g_vpp, (n <= 5) ? "CLEAN <<<" : "noisy"); }
  }

  // Per-discovery drop report: a sweep is done when the bus falls idle after a DISC_UN_MUTE.
  if (g_discActive && (millis() - g_lastRdmMs) > 600 && g_lastRdmMs != 0) {
    g_discActive = false;
    g_lastDiscMuted = mutedCount(); g_lastDiscExpected = g_fixCount;
    g_lastDiscResp = g_discResp; g_lastDiscReAsk = g_discReAsk;
    g_discDoneNew = true;
  }
  if (g_discDoneNew) {
    g_discDoneNew = false;
    const int miss = g_lastDiscExpected - g_lastDiscMuted;
    Serial.printf("[disc#%d] discovered %d/%d  (%s%d missed)  responses=%lu  S3-dropped-replies=%lu  turnaround=%luus\n",
      g_discSeq, g_lastDiscMuted, g_lastDiscExpected, miss?"** ":"", miss,
      (unsigned long)g_lastDiscResp, (unsigned long)g_lastDiscReAsk, (unsigned long)g_turnaround);
  }

  if (g_verbose) while (g_evTail != g_evHead) {
    volatile Ev* e = &g_ev[g_evTail&127];
    Serial.printf("[dub] d=%2d %s muted=%d lo=%02X%02X%02X%02X%02X%02X hi=%02X%02X%02X%02X%02X%02X\n",
      e->depth, e->resp?"REPLY ":"silent", e->muted,
      e->lo[0],e->lo[1],e->lo[2],e->lo[3],e->lo[4],e->lo[5],
      e->hi[0],e->hi[1],e->hi[2],e->hi[3],e->hi[4],e->hi[5]);
    g_evTail++;
  }

  // Console command input
  static char line[32]; static int li = 0;
  while (Serial.available()) {
    char c = Serial.read();
    if (c=='\n' || c=='\r') { if (li>0){ line[li]=0; handleCommand(line); li=0; } }
    else if (li < (int)sizeof(line)-1) line[li++]=c;
  }

  // Fast heartbeat while the bus is active: lets us see whether core-1's RX freezes
  // (rxBytes stops climbing) or stays alive during an early-terminating discovery.
  static uint32_t hb = 0;
  if (busActive() && millis() - hb >= 200) {
    hb = millis();
    Serial.printf("[hb] rxBytes=%lu rdmReq=%lu resp=%lu reAsk=%lu\n",
      (unsigned long)g_rxBytes, (unsigned long)g_rdmSeen, (unsigned long)g_respCount, (unsigned long)g_ctrlReAsk);
  }
  static uint32_t lp = 0;
  if (millis() - lp >= 3000) {
    lp = millis();
    Serial.printf("[stat] fixtures=%d frames=%lu rdmReq=%lu resp=%lu get=%lu set=%lu nack=%lu reAsk=%lu %s\n",
      g_fixCount, (unsigned long)g_frames, (unsigned long)g_rdmSeen, (unsigned long)g_respCount,
      (unsigned long)g_getCount, (unsigned long)g_setCount, (unsigned long)g_nackCount,
      (unsigned long)g_ctrlReAsk, busActive()?"active":"idle");
  }
}

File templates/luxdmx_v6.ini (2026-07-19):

# LuxDMX v6 board (ESP32-S3 + onboard W5500). Mirrors the luxdmx_v6 build_flags.
# Compile-time flags stay in platformio.ini (USE_ETH_SPI, board, custom_sdkconfig);
# this template only carries the runtime default VALUES.
extends=_base

# 5-LED status panel (ledpin stays the _base GPIO2 default, unused at ledtype 3)
ledtype=3
ledr=1
ledg=2
ledy=6
ledb=7
ledw=15
# Balance the panel: the green + white LEDs are far brighter per mA than the others, so
# they run at a very low PWM duty. These values were tuned by eye on a real board
# (green/white are the bright ones); adjust live in Settings -> Status LED (or /led/bright).
ledbrr=255
ledbrg=8
ledbry=255
ledbrb=255
ledbrw=17

# Two isolated DMX universes
o0_tx=17
o0_rx=18
o0_rts=8
o1_en=1
o1_tx=16
o1_rx=21
o1_rts=47

# W5500 SPI pins (module is opt-in at runtime; WiFi is the default)
ethcs=10
ethsck=12
ethmosi=11
ethmiso=13
ethint=14
ethrst=9

# Display header pre-wired (panel stays off until enabled)
dispsda=4
dispscl=5
dispsck=39
dispmosi=40
dispcs=41
dispdc=42
disprst=38

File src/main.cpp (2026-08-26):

/*
 * LuxDMX — Art-Net / sACN → DMX Gateway
 * ESP32 / ESP32-S3 / WT32-ETH01 + Waveshare RS485 (C)
 *
 * Default pins: DMX TX=17, RX=16 (compile-time: DEF_DMX_TX_PIN/DEF_DMX_RX_PIN; runtime: web /config)
 * WT32-ETH01:   DMX TX=4, RX=5  (GPIO16 used by LAN8720 power)
 */

#include <Arduino.h>
#include <soc/soc.h>
#include <soc/rtc_cntl_reg.h>
#include <Adafruit_NeoPixel.h>
#include <Wire.h>
#include <SPI.h>
#include <Adafruit_GFX.h>
#include <Adafruit_SSD1306.h>
#include <Adafruit_SH110X.h>
#include <Adafruit_SSD1351.h>
#include <Preferences.h>
#include <WiFi.h>
#include <esp_wifi.h>   // for esp_wifi_get/set_config (BSSID lock clearing)
#include <esp_task_wdt.h>  // reconfigure the task WDT to not reboot the gateway under a network flood
#include <esp_chip_info.h> // chip model detection for the RDM device-table auto-sizing (rdmAllocTables)
// Schema-driven config engine (src/config/). config_schema.h defines the Config +
// DmxOutput structs + MAX_OUTPUTS (moved here out of main.cpp); config_core.h is
// the transport-agnostic load/save/setValue/toJson engine the handlers drive. The
// per-board default VALUES live in templates/*.ini (embedded via extra_scripts.py),
// not in -D macros. The structural enums (MERGE_*, NET_*, WIRED_FB_*, RMII_*) stay
// defined below in main.cpp; config_enums.h mirrors them for the engine TU.
#include <config_core.h>     // EmbeddedConfig library (lib/EmbeddedConfig)
#include <config_serial.h>   // serial configuration console (Phase 2/3)
// Wired-Ethernet capability (compile-time). WiFi is ALWAYS compiled in too; the
// active interface — and, on the classic ESP32, which wired PHY — is chosen at
// runtime (issue #14).
//   HAS_ETH_SPI  : W5500 over SPI. Works on any ESP32 variant; on when USE_ETH_SPI.
//   HAS_ETH_RMII : LAN8720 over RMII. Uses the ESP32's INTERNAL EMAC, which only the
//                  original ESP32 has — so it is available on the classic ESP32
//                  regardless of board (the S3 never gets it). cfg.wiredPhy picks it.
//   USE_ETH_RMII : the WT32-ETH01 build marker only — drives OTA_BIN + its RMII /
//                  useEthernet=true defaults. RMII compilation is the chip macro now.
#if defined(USE_ETH_SPI)
#define HAS_ETH_SPI 1
#endif
#if defined(CONFIG_IDF_TARGET_ESP32)   // original ESP32 → has the internal EMAC for RMII
#define HAS_ETH_RMII 1
#endif
#if defined(HAS_ETH_SPI) || defined(HAS_ETH_RMII)
#include <ETH.h>
#define HAS_WIRED_ETH 1
#endif

// Wired PHY runtime selection (cfg.wiredPhy). DEF_WIRED_PHY is the per-OTA-artifact
// default and MUST reproduce what the device used before, so an OTA to a both-PHY
// build never changes behavior: the WT32 artifact (USE_ETH_RMII) defaults to RMII,
// every other build defaults to W5500 — exactly the old compile-time split.
#define WIRED_PHY_SPI  0   // W5500 over SPI (external module)
#define WIRED_PHY_RMII 1   // LAN8720 over RMII (ESP32 internal EMAC)
// Which SPI Ethernet chip the WIRED_PHY_SPI path drives (cfg.ethSpiPhy). Both are external
// modules on the SAME CS/INT/RST/SCK/MISO/MOSI wiring and use the same ETH.begin() SPI
// signature; only the PHY enum differs. DM9051 is a W5500 alternative (issue #36), UNTESTED
// on real hardware so far. Default W5500, so an OTA changes nothing for existing devices.
#define ETH_SPI_PHY_W5500  0   // Wiznet W5500
#define ETH_SPI_PHY_DM9051 1   // Davicom DM9051
#ifndef DEF_WIRED_PHY
#if defined(USE_ETH_RMII)
#define DEF_WIRED_PHY WIRED_PHY_RMII
#else
#define DEF_WIRED_PHY WIRED_PHY_SPI
#endif
#endif

// RMII PHY family + wiring (cfg.rmii*, used when wiredPhy = RMII). These indices are
// stable in NVS and mapped to the arduino-esp32 ETH enums in startEthRmii(). The
// defaults reproduce the LAN8720 / WT32-ETH01 wiring, so an existing RMII device is
// unchanged across an OTA. The RMII DATA lines are fixed by the EMAC and not settable;
// only the PHY type, address, MDC/MDIO/power pins and REF_CLK mode are configurable.
#define RMII_PHY_LAN8720 0
#define RMII_PHY_IP101   1
#define RMII_PHY_RTL8201 2
#define RMII_PHY_DP83848 3
#define RMII_PHY_KSZ8081 4
#define RMII_PHY_JL1101  5
#define RMII_PHY_COUNT   6
#define RMII_CLK_GPIO0_IN   0   // external 50MHz clock fed in on GPIO0 (WT32-ETH01)
#define RMII_CLK_GPIO0_OUT  1
#define RMII_CLK_GPIO16_OUT 2
#define RMII_CLK_GPIO17_OUT 3
#ifndef DEF_RMII_PHY
#define DEF_RMII_PHY  RMII_PHY_LAN8720
#endif
#ifndef DEF_RMII_ADDR
#define DEF_RMII_ADDR 1
#endif
#ifndef DEF_RMII_MDC
#define DEF_RMII_MDC  23
#endif
#ifndef DEF_RMII_MDIO
#define DEF_RMII_MDIO 18
#endif
#ifndef DEF_RMII_PWR
#define DEF_RMII_PWR  16
#endif
#ifndef DEF_RMII_CLK
#define DEF_RMII_CLK  RMII_CLK_GPIO0_IN
#endif
#include <DNSServer.h>    // captive-portal DNS for the first-run setup portal
#include <ESPAsyncWebServer.h>
#include <ESPmDNS.h>
#include <ArduinoOTA.h>
#include <WiFiClientSecure.h>
#include <HTTPClient.h>
#include <HTTPUpdate.h>
#include <Update.h>
#include <ArtnetWifi.h>
#include "rdm_types.h"                  // RDM E1.20 types and constants (ours, see the header)
#include "dmx_rmt.h"
static RmtDmx g_rmt[MAX_OUTPUTS];      // RMT-based DMX TX per output (issue #64 hard-zero path)
#include "rdm_rmt.h"                    // RDM controller on RMT-TX + UART-RX

// Auto-generated asset headers (produced by extra_scripts.py before each build)
#include "generated/version.h"
#include "generated/index_html.h"
#include "generated/config_html.h"
#include "generated/rdm_html.h"
#include "generated/config_saved_html.h"
#include "generated/setup_html.h"
#include "generated/setup_done_html.h"
#include "generated/reset_html.h"
#include "generated/reset_done_html.h"
#include "generated/ota_progress_html.h"
#include "generated/ota_done_html.h"
#include "generated/logo_webp.h"
#include "generated/favicon_png.h"
#include "generated/bootstrap_min_css.h"

// On-unit controls (issue #24): rotary encoder + buttons -> a small display menu.
// Pure, host-tested decode/mapping/menu logic (no Arduino); main.cpp only samples
// the pins, renders the menu, and applies the result.
#include "input_map.h"
#include "menu.h"

// ---------------------------------------------------------------------------
// Hardware
// ---------------------------------------------------------------------------
#ifndef DEF_DMX_TX_PIN
#define DEF_DMX_TX_PIN 17
#endif
#ifndef DEF_DMX_RX_PIN
#define DEF_DMX_RX_PIN 16
#endif
#ifndef DEF_DMX_RTS_PIN
#define DEF_DMX_RTS_PIN -1
#endif
#ifndef DEF_DMX_PORT
#define DEF_DMX_PORT 1
#endif
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

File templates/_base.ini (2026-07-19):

# Base template — global defaults shared by every board, applied before the
# board template. Only values that differ from the schema's NEUTRAL (a pin -> -1,
# an int/enum -> its min, bool -> false, string -> "") need listing here, so this
# mirrors main.cpp's old global DEF_* fallbacks (the per-board -D overrides live
# in each board template). Keys are exactly the schema keys (see config_schema.cpp);
# per-output keys are o<i>_<suffix>. Lines are key=value; '#' is a comment.

# Identity
hostname=dmx-gateway
otapw=dmxota
protocol=2

# Status LED — classic default GPIO2 plain (boards override)
ledpin=2
ledtype=1

# 5-LED panel per-colour brightness (0-255 PWM duty). Full by default; a board with
# the panel (ledtype 3) dims the perceptually-brighter LEDs (green/white) to match.
ledbrr=255
ledbrg=255
ledbry=255
ledbrb=255
ledbrw=255

# Display I2C default pins (boards override)
dispsda=21
dispscl=22

# W5500 SPI default pins (classic-ESP32 VSPI); the LuxDMX board overrides these
ethcs=5
ethsck=18
ethmosi=23
ethmiso=19
ethint=4
ethrst=25
ethfreq=20

# RMII (LAN8720) defaults; only the WT32-ETH01 board actually uses RMII
rmiiaddr=1
rmiimdc=23
rmiimdio=18
rmiipwr=16

# Network
subnet=255.255.255.0

# RDM over Art-Net on by default (only active on an RDM-capable output)
artrdm=1

# On-unit controls (rotary encoder + buttons + display menu, issue #24). All pins
# stay off (-1) so nothing runs unless wired. These are just the sensible knob +
# button-role defaults, so once you set the pins in /config the menu already makes
# sense: standard 4-edge detented encoder, buttons pre-mapped Next/Prev/Enter/Back,
# universe knob spans 0..15 (the common single-net range).
encsteps=4
ctlunimax=15
btn1act=3
btn2act=4
btn3act=1
btn4act=2

# Output 0 on by default at the classic DMX pins; output 1 present but off
o0_en=1
o0_tx=17
o0_rx=16
o1_uni=1
o1_port=2

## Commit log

2026-05-21 Replace Tailwind CDN with self-hosted Bootstrap 5.3, redesign UI
    - Bootstrap 5.3.3 minified CSS (233 KB) compiled into firmware via
    PROGMEM, served at /bootstrap.min.css with 7-day cache header
    - Dark GitHub-palette theme (--gh-bg #0d1117, surface #161b22)
    - Logo enlarged to 64 px in main nav, 48 px on secondary pages
    - DMX grid: larger cells (42 px), smooth blue gradient per channel value
    - Channel editor now a centered modal overlay (no Bootstrap JS needed)
    - Quick-set buttons (Off / 50% / Full) in channel modal
    - Signal strength color-coded green/yellow/red
    - Config, reset, and splash pages all converted to Bootstrap
    - extra_scripts.py: binary_to_header() handles .css assets the same as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
    [main.cpp]
2026-05-22 Add web OTA (GitHub + upload), WiFi reset to settings with confirmation
    - /ota/github: downloads latest firmware.bin from GitHub releases, flashes
    via HTTPUpdate + WiFiClientSecure, reboots automatically
    - /ota/upload: multipart firmware.bin upload via browser file picker
    - Reset WiFi moved from nav into Settings page, guarded by a confirmation
    checkbox (danger zone section at bottom)
    - ota_progress.html: progress page with reconnect polling after GitHub OTA
    - ota_done.html: success/failure page for manual upload
    - Remove Reset WiFi nav button from all pages
    - Partition: default -> min_spiffs (1920 KB / app) to fit TLS libraries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
    [main.cpp]
2026-05-22 Add sender list, change log, jitter stat, sparkline, conflict banner; default to Art-Net + sACN
    - Status page: jitter stat card, conflict warning banner, sender table,
    change log, sparkline in channel modal (60-sample ring buffer)
    - WebSocket frame extended to 528 bytes (added senderCount, conflict, jitter fields)
    - Sender tracking with per-sender FPS, conflict detection
    - Change log with top-N changed channels per frame
    - Default protocol changed from Art-Net-only to Art-Net + sACN (both)
    - Added 404 handler; WiFiManager connect timeout 15s
    [main.cpp]
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2026-05-22 Increase WiFiManager connect timeout from 15s to 60s
    Prevents failed reconnect on slow/busy networks after reset.
    [main.cpp]
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2026-06-04 Fix version check crash: fresh SSL client per request, larger task stack
    Reusing WiFiClientSecure after end() left stale SSL state causing a crash.
    Extracted httpsGet() helper that creates fresh objects each call.
    Task stack bumped 8192→12288 to cover two SSL contexts.
    [main.cpp]
2026-06-04 Fix WiFi credentials not persisting: remove WiFi.persistent(false)
    Calling persistent(false) before WiFiManager prevented credentials
    from being saved to NVS after portal configuration, requiring
    re-setup on every reboot.
    [main.cpp]
2026-06-04 Move changelog to browser side, remove second HTTPS request from device
    The device's second httpsGet (changes.txt) was crashing or causing
    connection aborts. Moved to browser: when an update is detected,
    index.html fetches the GitHub API directly and filters the release body.
    Device now makes only one HTTPS request (version.txt).
    [main.cpp]
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2026-06-04 Move DMX output + status LED to a dedicated 40Hz task
    The synchronous WebServer/WebSocket block loop() while serving the web
    UI (large responses, slow clients), which froze the status LED and
    stalled DMX output for seconds. DMX send + LED now run in their own
    FreeRTOS task (core 1, priority 2, 40Hz continuous refresh), immune to
    network blocking in loop(). Continuous refresh also holds the last frame
    as a failsafe. Handlers/callbacks now only update dmxBuf; all dmx_send
    is centralized in the task. enableDelay(false) keeps handleClient from
    waiting on idle clients.
    [main.cpp]
2026-06-04 Serve pages from PROGMEM, fetch dynamic values via /info.json; disable WiFi sleep
    - handleRoot/handleConfigGet now send_P straight from PROGMEM (no 19 KB
    String + replace per request). Pages carry no {{placeholders}}; the
    browser fetches values from a new /info.json and fills them in.
    - WiFi.setSleep(false): the radio's modem-sleep added 100ms+ per round
    trip, making the UI laggy; disabling it keeps responses snappy.
    - WS heartbeat made lenient (30s/10s/2) so a real browser is never
    dropped on a transient hiccup (aggressive settings caused reconnect
    churn → socket exhaustion).
    Verified: fresh device serves pages in 0.1-0.4 s with stable heap.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
    [main.cpp]
2026-06-04 Migrate web server to ESPAsyncWebServer/AsyncWebSocket; fix WiFi stall
    - Replace synchronous WebServer + links2004/WebSockets with
    ESPAsyncWebServer + AsyncWebSocket (AsyncTCP). Serving now runs in its
    own task and never blocks loop() — DMX/LED stay smooth and small
    responses are instant.
    - All HTTP handlers converted to AsyncWebServerRequest*; PROGMEM pages via
    send_P/beginResponse_P; OTA upload via async upload callback; /labels via
    streaming body handler. WebSocket moved to ws://host/ws (port 80), push
    via binaryAll/textAll gated on availableForWriteAll(); cleanupClients()
    in loop. Manual DMX writes and reboots deferred to loop() (async handlers
    must not block).
    - Remove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
    [main.cpp]
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2026-06-06 feat: make DMX TX/RX/RTS pins configurable at runtime via web UI
    Pins were hardcoded compile-time constants; users with different RS485
    module variants or ESP32 boards (e.g. RX on GPIO5 instead of GPIO16)
    had no way to adapt without recompiling.
    - Add dmxTxPin/dmxRxPin/dmxRtsPin to Config, persisted in NVS
    - initDmx() now uses cfg values (DEF_DMX_TX/RX/RTS_PIN as defaults)
    - Expose all three in /info.json and handleConfigPost()
    - New "DMX Output Pins" card in web settings (/config)
    - README: pinout note updated, NVS table updated
    Fixes reported issue where DMX output didn't work due to RX pin mismatch.
    [main.cpp]
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2026-06-06 fix: versionCheckTask was one-shot — make it repeat every 6 hours
    The task called vTaskDelete(NULL) after the initial boot check, so
    auto-update never fired unless a newer release happened to be available
    within 8 seconds of boot. Now loops indefinitely, re-checking every 6 h.
    [main.cpp]
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2026-06-06 feat(rdm): read RDM sensors per spec (SENSOR_DEFINITION + SENSOR_VALUE)
    Phase 3 sensors. esp_dmx 4.1 has no sensor helper, so use the generic
    rdm_send_request with format strings matching the packed structs (verified
    against the documented RDM_PID_DEVICE_INFO format and cross-checked with
    E1.20/OLA docs):
    - SENSOR_DEFINITION "bbbbwwwwba$" (num,type,unit,prefix,range,normal,flags,desc)
    - SENSOR_VALUE "bwwww$" (num,present,lowest,highest,recorded)
    Discovery now reads up to RDM_MAX_SENSORS per fixture: name from the
    definition description (fallback to a type label), unit mapped from the
    E1.20 unit enum, present value from SENSOR_VALUE. Definition and value are
    read independen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
    [main.cpp]
2026-06-06 Fix BSSID lock: clear stored BSSID on every boot so strongest AP is always chosen
    The ESP32 persists not just SSID+password but also the BSSID (MAC) of the
    last AP it connected to. On reboot, autoConnect loaded that BSSID and
    connected directly to that AP, bypassing WIFI_ALL_CHANNEL_SCAN completely.
    Result: on a mesh network, device silently re-locked to the same distant AP
    after every reboot even after connecting to a better one.
    Fix: read the stored wifi_config via esp_wifi_get_config(), clear bssid_set
    before autoConnect runs, and do the same in the watchdog reconnect path.
    Now every connect (boot or reconnect) genuinely scans all channels and
    picks the strongest AP for the SSID.
    Co-Aut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
    [main.cpp]
2026-06-06 Clear BSSID post-connect so every reboot rescans for the strongest AP
    The pre-connect clearing wasn't enough: WiFiManager re-saves the BSSID to
    flash when autoConnect succeeds, so the next boot loaded it again. Now we
    also clear bssid_set immediately after startWiFiManager() returns, erasing
    the just-saved BSSID before the next reboot can load it.
    [main.cpp]
2026-06-06 Fix mesh AP selection: explicit scan + connect to strongest BSSID every boot
    Root cause (proven via on-device [SCAN] log): the mesh exposes 3 distinct
    BSSIDs for the SSID (one at -25 dBm close, two distant at -75/-82). The
    ESP32 auto-connect reliably stuck to a distant -75 AP, and setScanMethod/
    setSortMethod/BSSID-clearing did NOT override that choice.
    connectStrongestAP(): after WiFiManager connects, scan all APs for the SSID,
    log each (bssid/rssi/ch), and WiFi.begin() directly to the strongest BSSID if
    it's >6 dB better. Runs on every boot, so it no longer reverts after a reboot.
    Validated on hardware across reboots: now connects at -25 dBm (was -75/-80),
    HTTP response 0.02 s (was 4.8 s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
    [main.cpp]
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2026-06-08 @ hardware: align gerbers + CPL to bottom-left aux origin (fixes JLCPCB placement)
    JLCPCB showed parts off-board (CPL was bottom-left-relative but gerbers absolute),
    its auto-fix then mis-rotated J2. Now the board aux/drill origin is the bottom-left
    corner and gerbers+drill+CPL are all exported --use-drill-file-origin, so all three
    share one origin. Verified: CPL parts (X5.3-69, Y1.5-26.9) sit inside the gerber
    outline (0-82.3 x 0-28.3). No auto-fix needed.
    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
    [lumigate_carrier.kicad_pcb]
2026-06-08 @ hardware: re-route after USB-C (J2) 180deg orientation fix
    J2 footprint needed a 180deg flip so the connector mates with the pads; re-routed
    clean (0 unconnected / 0 shorts / 0 edge). Regenerated gerbers/drill/CPL (J2 now
    rot 0 in CPL), all on the bottom-left aux origin.
    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
    [lumigate_carrier.kicad_pcb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]
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2026-06-13 display: optional OLED / colour OLED status panel (issue #5)
    Add an opt-in on-device status display, plumbed like the status LED and
    off by default. Drives mono I2C OLEDs (SSD1306 128x64/128x32, SH1106
    128x64) and the colour SPI SSD1351 128x128 through one Adafruit_GFX
    renderer.
    - Config: dispType + I2C (SDA/SCL) and SPI (CS/DC/RST/SCK/MOSI) pins +
    rotation, persisted in NVS and exposed via /config (new Display card)
    and /info.json.
    - initDisplay() factory probes the I2C address (0x3C/0x3D), brings up the
    panel and shows a boot splash; rendering runs on its own FreeRTOS task.
    - Height-aware status screen (128x32 / 128x64 / 128x128 hero layout) with
    IP, universe, protocol, FPS, sourc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
    [main.cpp]
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2026-06-14 hardware: LumiGate v3 standalone board — 4-layer, isolated DMX, automated routing
    Replaces the abandoned Olimex carrier with a fully standalone ESP32-S3 + W5500
    board: galvanically-isolated DMX (ISO3086 + B0505S), USB-C power/flash, JST SH
    display header, 5 status LEDs, BOOT/RST buttons.
    4-layer with a placement-driven, fully-scripted routing pipeline (rebuild_iso →
    escape_connectors → Freerouting 2.2.4 → cleanup_pads) that regenerates the
    isolation barrier and routes the whole board from component placement alone.
    Validated: 0 unconnected/shorts, 0 isolation (4mm) violations, SPICE-checked
    analog. Includes production data (4-layer gerbers, BOM, CPL), a comprehensive
    README with fa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
    [Sock1x10.step, TypeC-6P.step, lumigate.kicad_pcb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]
2026-06-14 display: show both universes + a frame rate per universe (issue #5)
    - Status screen lists each enabled output's universe (Uni 0+5). With both
    outputs enabled each gets its own row (A/B) showing its own universe and its
    own FPS; the single-output layout is unchanged.
    - Rename the cryptic "Src" label to "Sources" (matches the "2+ sources" banner).
    - Track per-output frame rate (outFps[]) in routeFrame; the aggregate fps still
    feeds the WebSocket / web UI.
    - Add docs/make_display_preview.py (faithful renderer using the real Adafruit GFX
    font) and regenerate docs/display-preview.png; update README + docs/display.md.
    Addresses einlichtvogel's feedback on #5.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
    [main.cpp]
2026-06-14 web UI: per-output FPS, stats in the navbar, Bootstrap modals
    - WS frame appends a frame rate per output (after the DMX block); dmx.json gains
    "outfps". The navbar FPS stat now reflects the viewed output and each output
    selector button shows its own live rate.
    - Move the FPS / WiFi / Heap / Uptime / Jitter stat cards into the top navbar
    (compact), reclaiming the vertical space.
    - Replace native confirm()/alert() with a Bootstrap-styled dialog (OTA install +
    TX-pin validation); no Bootstrap JS dependency.
    - Clarify in /config that the OTA Password only applies to espota (Arduino IDE /
    PlatformIO), not the browser firmware update.
    - Update the README WebSocket frame documentation.
    C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
    [main.cpp]
2026-06-14 hardware: 3D-printable enclosure + JLCPCB fab fixes
    - case/: parametric OpenSCAD clamshell (lumigate_case.scad) driven by the live
    PCB (extract_case_params.py) + measured connector heights; XLR flange screw
    holes corrected to the datasheet diagonal pattern (M2, 12.5mm centre); STL +
    assembly GLB deliverables, Blender doc renders.
    - gen_gerbers.py: board-safe fab export (kicad-cli, ALWAYS aux/drill origin) so
    gerbers + CPL share the bottom-left origin (fixes JLCPCB "parts off the board").
    - BOM: J4 = C160408 (JST SM09B-SRSS-TB, in stock); group by LCSC# (one line per
    part); fee-free swaps D4 yellow -> C89811 (preferred), R18 49.9R -> C25120 (basic).
    - gerbers re-exported with aux or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
    [_section.scad, board_params.scad, lumigate_BOM_jlcpcb.csv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]
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2026-06-14 Revert "v3: finish ESP32-S3 + W5500 board firmware support; drop dead carrier doc"
    This reverts commit 4ca9476 in full. The unfinished/untested arduino-esp32 v3 +
    W5500 + 5-LED firmware was pushed to master by a PARALLEL session and auto-released
    as latest (v1.0.70), exposing it via OTA. Roll master back to the last known-good
    state so CI republishes a safe latest. The v3 work is preserved on branch
    feature/lumigate-v3-firmware and must be hardware-tested before re-merging
    (see docs/v3-firmware-todo.md there).
    [main.cpp]
2026-06-14 fix(v3): disable brownout detector via sdkconfig (S3 boot-loop)
    The v3 ESP32-S3 firmware boot-looped with "E BOD: Brownout detector was
    triggered" (RTC_SW_SYS_RST). On arduino-esp32 v3 / IDF 5 the BOD is armed in
    IDF startup before setup() runs, so the runtime RTC_CNTL_BROWN_OUT_REG write is
    too late on the S3. Disable it at the sdkconfig level (CONFIG_ESP_BROWNOUT_DET=n)
    in env:lumigate_v3 so it never arms. Refs #11.
    [main.cpp]
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2026-06-14 fix(v3): disable brownout detector via sdkconfig (S3 boot-loop)
    The v3 ESP32-S3 firmware boot-looped on "E BOD: Brownout detector was
    triggered" (RTC_SW_SYS_RST). On arduino-esp32 v3 / IDF 5 the BOD arms during
    too late on the S3; it is also already at the least-sensitive level (LVL7) so it
    cannot be tuned, and the only precompiled lever (flash <80MHz) ships no matching
    bootloader. Disable it at the sdkconfig level (CONFIG_ESP_BROWNOUT_DET=n) via
    pioarduino custom_sdkconfig. Confirmed in the generated sdkconfig.lumigate_v3
    ("CONFIG_ESP_BROWNOUT_DET is not set"); builds clean.
    custom_sdkconfig forces an Arduino s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
    [min_spiffs.csv]
2026-06-15 fix(v3): add min_spiffs.csv to project root so the from-source build resolves it
    The brownout fix (aaaedee) added custom_sdkconfig, which switches lumigate_v3 to a
    from-source Arduino/IDF core build. In that path PlatformIO resolves
    `board_build.partitions = min_spiffs.csv` relative to the project (not the framework
    partitions dir), so the build aborted with "Missing partition table file min_spiffs.csv".
    The prebuilt-core envs (esp32dev/esp32s3dev) still find the built-in copy.
    Add an identical copy at the project root (same layout as the built-in: 2x 0x1E0000
    OTA app slots + 128 KB SPIFFS) so all envs resolve it. No partition-layout change.
    Verified: lumigate_v3, esp32dev and esp32s3dev a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
    [min_spiffs.csv]
2026-06-15 feat(v3): WiFi by default, W5500 wired Ethernet as a runtime opt-in
    The v3 board firmware was compile-time Ethernet-only (-DUSE_ETHERNET), which is
    wrong: per product spec the default must be WiFi, with wired Ethernet opt-in.
    Drop USE_ETHERNET from env:lumigate_v3 (keep USE_ETH_SPI to compile the W5500
    path). Both WiFi + W5500 stacks now ship in one build; the mode is chosen at
    runtime via cfg.useEthernet (default false = WiFi), mirrored into g_useEth before
    net init. netConnected()/netLocalIP()/netSSID()/setup()/the WiFi link-watchdog/
    the status-display label all branch on g_useEth; startEthSpi() brings up the
    W5500 only when enabled. New /config switch "Use wired Ethernet" (shown when
    inf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
    [main.cpp]
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2026-06-16 feat(boards): expand catalog to 10 boards (NodeMCU-32S, WT32-ETH01, Adafruit Feather/QtPy)
    Add 5 catalog (online, lazy-fetched) board descriptors, sourced from authoritative
    pinout data (the Arduino core's variants/<board>/pins_arduino.h), not guessed:
    - NodeMCU-32S (ESP32-WROOM-32, 38-pin)
    - WT32-ETH01 (Ethernet, LAN8720) — RMII pins reserved, GPIO0 = refclk; matches the
    firmware's wt32eth01 env, which previously fell back to "Custom"
    - Adafruit Feather ESP32-S3 (standard Feather layout)
    - Adafruit QT Py ESP32-S3
    - Adafruit Feather ESP32 V2 (ESP32-PICO) — correctly frees GPIO6-11 and reserves
    16/17 for the embedded flash (the opposite of a WROOM board)
    Now 10 boards total: 5 built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
    [gen_board_descriptor.py]
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2026-06-16 feat(boards): Fritzing "realistic board" graphic + clickable hotspots (PoC, Feather S3)
    Proof-of-concept for real board graphics with click-to-assign pins, license-clean:
    - Source: Adafruit Fritzing-Library breadboard SVG for the Feather ESP32-S3
    (CC BY-SA 3.0). The SVG is kept UNMODIFIED; hotspots are a separate overlay, so no
    derivative is created. Attribution in web/boards/CREDITS.md.
    - Hotspot coordinates are data-driven, not guessed: extracted from the part's .fzp
    connector terminals (viewBox 0 0 147.24 64.8), mapped to GPIOs via pins_arduino.h.
    23 hotspots in the descriptor's new `fritzing` block.
    - config.html: a "realistic board graphic (online)" toggle in the picker swaps t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
    [gen_board_descriptor.py]
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2026-06-16 fix(boards): drop duplicate STEMMA SDA/SCL hotspots + more vertical spacing around graphic
    - The Feather ESP32-S3 has a STEMMA QT I2C connector on the left edge sharing GPIO3/4
    with the header SDA/SCL pads, which showed up as confusing duplicate hotspots. Drop
    the STEMMA hotspots; keep only the header SDA/SCL (now 21 hotspots, no GPIO dupes).
    - Add vertical padding around the board graphic (.board-wrap + .fzwrap) so it no longer
    crowds the surrounding controls.
    [gen_board_descriptor.py]
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2026-06-17 feat(config): consistent pin scale across boards + on-board fixed-wiring list
    Two picker improvements:
    1. Consistent pin/label size across boards. The realistic Fritzing graphic was scaled
    to fit the container width, so pins/labels looked different per board (a 50-unit QT Py
    vs a 147-unit Feather rendered at very different scales). Now the graphic renders at a
    fixed px-per-unit scale (all Fritzing breadboard SVGs share the 0.1" grid), so pins and
    callouts are the same size on every board; larger boards simply render larger.
    2. On-board fixed wiring list. Each descriptor gains a `hardwired` list of the pins that
    are physically wired on the board (onboard LED/NeoPixel, the Lum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
    [gen_board_descriptor.py]
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2026-06-17 feat(boards): own MIT realistic graphic for DevKit-class boards
    The most widespread ESP32/-S3 DevKit boards (ESP32 DevKitC, DOIT DevKit v1,
    NodeMCU-32S, ESP32-S3 DevKitC-1) have no clean-license Fritzing part, so they
    were stuck with the schematic-only view. Add own_board_graphic() to
    gen_board_descriptor.py: draws a license-free (MIT) realistic board SVG (PCB,
    USB jack, WROOM module, two 0.1" gold-pad rows with silk labels) in the same
    0.1"-grid units as the Fritzing parts, so pin size stays consistent across all
    boards. Hotspot coords are exact because we place the pads ourselves.
    Wired into main() as an online-overlay (like the Fritzing graphics) only for
    boards without an existing Fritz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
    [gen_board_descriptor.py]
2026-06-17 feat(config): diagram-only pin picker, board select in popup, all esp32/s3 boards
    Per feedback: too few clean-license board images to justify realistic graphics.
    Drop ALL graphical representation (Fritzing/own-render SVGs, board photos, the
    photo + "realistic graphic" toggles) and keep a single, generated DIAGRAM view.
    - config.html: rewrite renderBoard as a horizontal diagram (pins along the horizon,
    vertical silk+GPIO labels, assignment callouts stacked above/below, fixed scale so
    a pin is the same size on every board). Remove renderFritzing / photo + fz toggles.
    - config.html: add a board <select> inside the pin-picker popup (delegates to the main
    one, so the board can be switched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
    [gen_board_descriptor.py]
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2026-06-17 Reapply "v3: finish ESP32-S3 + W5500 board firmware support; drop dead carrier doc"
    This reverts commit 170c7abf859f7b816ff57920418fdae759d1dd22.
    [main.cpp]
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2026-06-17 fix(display): keep the IP off the yellow/blue seam on dual-colour 128x64 OLEDs (#16)
    Dual-colour 0.96" SSD1306 128x64 panels are yellow (rows 0-15) + a ~2px gap +
    blue (rows 16-63); the driver sees a plain mono panel. The 128x64 status layout
    started the body at row pitch rp=11, so the IP line (y=11, rows 11-18) was sliced
    across the colour seam at row 16 and unreadable. Keep the title alone in the yellow
    band and start the body block at the seam (y=16) so the IP and following lines sit
    entirely in the blue band. Mono/128x32/128x128 layouts unchanged. Verified on real
    hardware (ESP32 + dual-colour SSD1306, OTA).
    [main.cpp]
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2026-06-18 feat(net): selectable network interface, WiFi STA/AP mode, Eth->AP fallback (#14)
    WT32-ETH01 is no longer Ethernet-only. USE_ETH_RMII now compiles both the
    LAN8720 wired stack and WiFi into one build, runtime-selectable in /config,
    the same model the v3/W5500 board already uses (USE_ETH_SPI). Adds a standalone
    WiFi AP mode for router-less field tests and an automatic Eth->AP fallback when
    the wired link has no carrier.
    - unified net abstraction with runtime g_useEth / g_apMode flags
    - config: wifiMode (STA/AP), apFallback, apPassword; board-aware default
    (WT32 stays Ethernet by default so an OTA from the old firmware stays wired)
    - config UI: WiFi-mode selector, AP password, AP-fallback s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
    [main.cpp]
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2026-06-21 feat(net): configurable W5500 SPI clock + classic ESP32+W5500 env; S3 BOD fix
    - esp32s3dev: disable the IDF brownout detector (CONFIG_ESP_BROWNOUT_DET=n,
    a from-source build) so the v3/IDF5 firmware boots on a real ESP32-S3
    (it was boot-looping; the runtime register write is too late on S3/IDF5)
    - ETH_W5500_SPI_FREQ_MHZ macro (default 20MHz) to tune/debug the W5500 SPI clock
    - new esp32dev_w5500 env: classic ESP32-WROOM + external W5500 on VSPI/SPI3,
    WiFi<->Ethernet runtime-switchable; HW-verified linking + e2e at 20MHz
    - README: board-table rows for the W5500-on-classic-ESP32 config and S3 BOD note
    [main.cpp]
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

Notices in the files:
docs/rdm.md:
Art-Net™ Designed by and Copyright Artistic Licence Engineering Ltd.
